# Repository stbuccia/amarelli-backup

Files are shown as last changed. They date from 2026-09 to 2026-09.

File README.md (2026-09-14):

# Liquorice Backup

Liquorice Backup is a liquorice tin backup box. 

## Why

As a photographer travelling without a laptop, you need a safe way to free your camera SD card anywhere. This project was born for that:

* Insert the camera SD into the box: it copies every new photo to a local cache immediately, so you can remove the card right away and keep shooting
* No internet needed for caching; no SD needed for uploading. The box uploads in background to your cloud when Wi-Fi is available
* A small database avoids re-uploading the same file twice

It is a low-cost, open-source alternative to commercial backup devices, built inside an Amarelli liquorice tin.

This project was made for the [Laboratorio di Making](https://www.unibo.it/it/studiare/insegnamenti-competenze-trasversali-moocs/insegnamenti/insegnamento/2025/545359) exam at the University of Bologna.

## How it works

You put your camera microSD card in the box and it backups your photo copying them locally, and then uploading in your favorite cloud storage (WebDav Server ory any place with rclone supports like Dropbox, Google Drive and over 70 more cloud storages). E-ink screen show you the progress, four buttons allow you to interact and a LED show the status with the colour.  

You can check by yourself in this demo video, it shows the local caching, the upload and how you can pause/resume it:

https://github.com/user-attachments/assets/87a310ae-04e9-4852-b67a-d44d25a2fe82

## Documentation

The full step-by-step guide is in the [wiki](wiki/Home.md). Follow the chapters in order the first time:

1. [What you need](wiki/01-what-you-need.md) - parts lists, where to buy and the prices
2. [Wiring and assembly](wiki/02-wiring-and-assembly.md) - how to connect everything
3. [Prepare the SD card and OS](wiki/03-prepare-os.md) - Raspberry Pi OS, SSH and Wi-Fi
4. [Install the software](wiki/04-install-software.md) - The process of installing the project
5. [Backup destination](wiki/05-backup-destination.md) - WebDAV or rclone
6. [Daily use](wiki/06-daily-use.md) - screen, buttons, LED and web page
7. [Run as a service and troubleshooting](wiki/07-service-and-troubleshooting.md) - if you come in to errors check this page for a solution

## Quick start

On the Raspberry Pi, after cloning the repository:

```bash
./install.sh          # installs everything and enables the service
sudo reboot
```

The box starts on its own through the `liquorice` service. To try the software on a PC with no hardware:

```bash
./install.sh --mock
.venv/bin/python software/main.py --mock
```

More in [Install the software](wiki/04-install-software.md).

## Repository layout

+ `software/`: the Python app
+ `config.json`: app settings
+ `.env`: secrets (WebDAV, Wi-Fi). You create this yourself; keep it private and out of git
+ `software/tests/hardware/`: small scripts to test each part
+ `hardware/`: wiring, schematic and electronics notes
+ `systemd/`: the service unit
+ `wiki/`: the step-by-step guide

## Credits

- [Amarelli Fabbrica di Liquirizia SRL](https://www.amarelli.it/) a company which produces delicious liquorice and very nice tin boxes (that i collect)
- [rclone project](https://rclone.org/) , that make my project more universal allowing to backup photos to every possible (virtual) place
- [@sudomod_wermy](https://linktr.ee/sudomod_wermy) which inspires me with him with his [MintyPi](). Sadly the project page is actually down.
- Luca Jacopo, a friend which lent me his 3d printer

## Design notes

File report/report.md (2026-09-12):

# Liquorice Backup

### Un dispositivo di backup fotografico in una scatoletta di liquirizia

Relazione per l'esame di Laboratorio di Making
Alma Mater Studiorum, Università di Bologna
Anno Accademico 2025/26

Autore: Stefano Bucciarelli  
Repository: <https://github.com/stbuccia/amarelli-backup>  
Documentazione utente (wiki): <https://github.com/stbuccia/amarelli-backup/blob/main/wiki/Home.md>

<table>
<tr>
<td style="width:50%; text-align:center; vertical-align:top;">
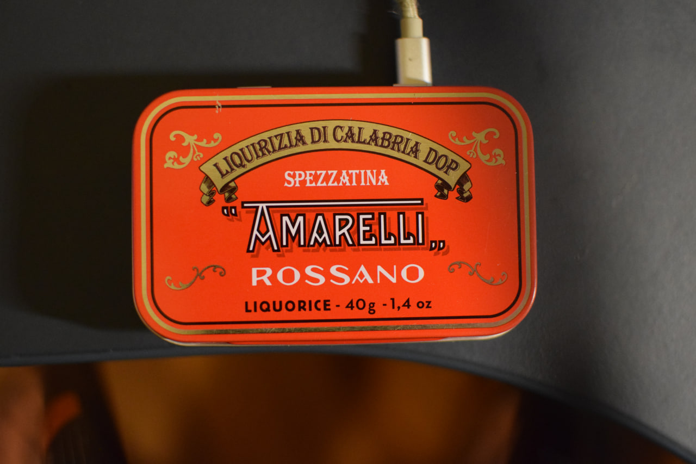
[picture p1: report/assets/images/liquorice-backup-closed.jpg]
Dispositivo chiuso nella scatoletta Amarelli

<br><em>Figura 1: Dispositivo chiuso — scatoletta Amarelli rossa (usabile a coperchio chiuso tramite LED).</em>
</td>
<td style="width:50%; text-align:center; vertical-align:top;">
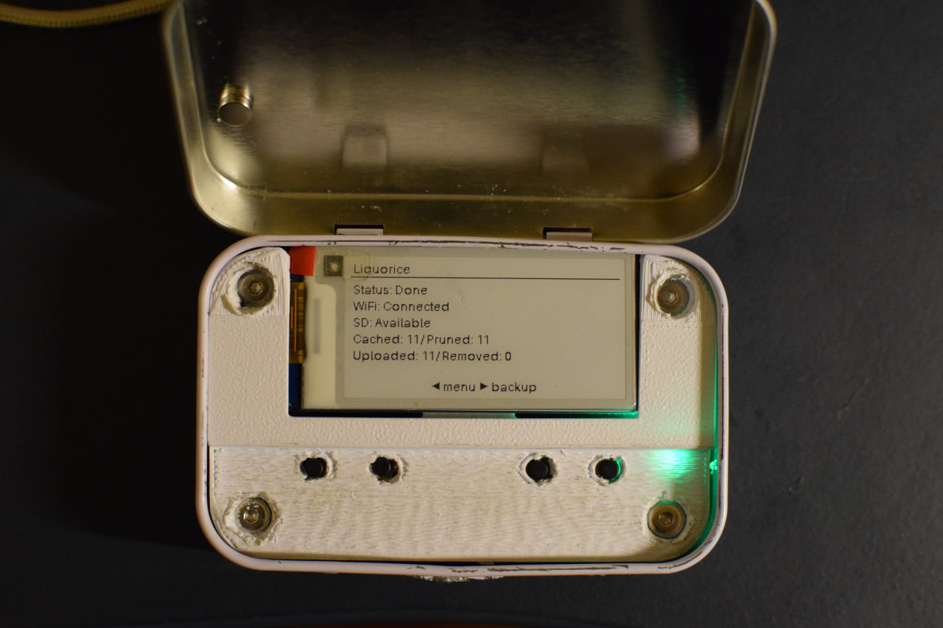
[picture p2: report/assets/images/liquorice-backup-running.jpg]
Dispositivo aperto con schermo acceso

<br><em>Figura 2: Dispositivo aperto — e-paper 2.13" con stato "Done" e LED verde, topper bianco.</em>
</td>
</tr>
</table>

---

## Indice

1. [Introduzione](#1-introduzione)
2. [Hardware](#2-hardware)
3. [Breadboard e circuito](#3-breadboard-e-circuito)
4. [Assemblaggio](#4-assemblaggio)
5. [Modellazione e stampa 3D](#5-modellazione-e-stampa-3d)
6. [Software](#6-software)
7. [Sviluppi futuri](#7-sviluppi-futuri)
8. [Conclusioni](#8-conclusioni)

---

## 1. Introduzione

Questa relazione è in italiano perché è finalizzata all'esame, mentre tutto il resto del repository è in inglese, per garantire migliore riprodubilità.

Liquorice Backup è un dispositivo di backup fotografico costruito dentro una scatoletta di latta di liquirizia Amarelli. L'utilizzo è il seguente, si infila la microSD della fotocamera nel lettore sul fianco e il dispositivo copia subito le foto nuove in una cache locale per poi caricarle in background sul cloud. Un database tiene traccia di cosa ha già fatto, così non carica mai due volte lo stesso file.

I due passaggi sono deliberatamente indipendenti: per fare la cache non serve Internet, per fare l'upload non serve la SD. È questa separazione che rende il dispositivo utile in viaggio, che è il caso d'uso per cui è nato.

L'interazione avviene tramite uno schermo e-paper da 2.13", quattro pulsanti, un LED RGB e, per configurazioni più comode, come per impostare una connessione a una nuova rete WiFi, una pagina web servita dal dispositivo stesso.

Questa relazione si concentra sul perché delle scelte e sui dettagli implementativi, comprese le strade sbagliate. Non è un manuale, quindi chi volesse riprodurre il progetto o usarlo come utente finale trova tutto nella [wiki del repository](https://github.com/stbuccia/amarelli-backup/blob/main/wiki/Home.md).

### 1.1 L'idea

L'idea nasce da un problema reale: quando vado in vacanza porto la fotocamera ma non il portatile, e questo significa che per giorni le foto vivono in un unico posto, la scheda SD nella fotocamera, sperando sempre che non si corrompa. Esistono dispositivi commerciali che risolvono il problema, ma sono costosi, chiusi e legati all'ecosistema del produttore, e non ho trovato un progetto DIY open source equivalente.

Il secondo ingrediente è che il mio gusto apprezza abbondantemente le liquirizia Amarelli e, di conseguenza, un collezionista involontario delle loro scatolette di latta.

Per il progetto però ho scoperto che le lattine Amarelli misurano circa 94 × 60 × 22 mm, che è uno standard di fatto per le scatoline delle caramelle alla menta (ad esempio le Altoids) hanno praticamente le stesse dimensioni. Questo ha due conseguenze concrete. Il progetto diventa universale, perché chi non trova le scatolette Amarelli può usare qualsiasi altra mint tin standard. E come vedremo successivamente esistono già componenti pensati per quel formato, in particolare la Mint Tin Sized Perma-Proto Breadboard, che entra nella scatoletta senza tagli.

L'ispirazione formale viene dal MintyPi di sudomod, una console portatile per retrogaming costruita in una scatoletta di Altoids che avevo visto anni fa su YouTube. Da lì viene la voglia di provarci, ma le due implementazioni divergono, perché MintyPi si basa su un PCB progettato su misura mentre qui ho scelto la strada della perfboard cablata a mano (la scelta è rimandata al paragrafo 3.3).

### 1.2 Requisiti

Oltre a garantire il funzionamento sopra citato ho fissato tre ulteriori requisiti, che poi hanno determinato alcune scelte implementative successive:

1. Usabile anche a scatoletta chiusa. In viaggio il dispositivo starà in uno zaino, non su un tavolo, quindi serve un feedback che funzioni senza guardare lo schermo (il LED RGB) e una modalità automatica in cui il backup parte da solo.
2. Nessuna dipendenza da una rete Wi-Fi già configurata. Un dispositivo da viaggio si trova per definizione su reti sconosciute, da cui la separazione fra cache e upload e la possibilità di far creare al dispositivo un proprio access point.
3. Minimizzare gli accessi via SSH. Se per cambiare un'impostazione devo aprire un terminale, il dispositivo non è finito: da qui il menù a bordo e la pagina web.

---

## 2. Hardware

### 2.1 Il microcomputer: Raspberry Pi Zero W

Ho puntato su Raspberry Pi per la notorietà e per la quantità di documentazione disponibile. La scelta del modello è stata un processo di esclusione.

La gamma "grande" (Pi 3, 4, 5) l'ho esclusa per le dimensioni: 85 × 56 mm, e con i connettori Ethernet e USB-A pieni supera in altezza i 22 mm utili della scatoletta.

La gamma Pico l'ho esclusa perché essendo un microcontrollore non esegue un sistema operativo, ed avrei avuto complicazioni a riguardo, come: niente filesystem montabile, nessun modo di far girare rclone o SQLite, e una memoria RAM troppo piccola.

I Compute Module 4 e 5 li ho esclusi perché sono System-on-Module, non schede complete e non hanno l'header a 40 pin.

Restava la gamma Zero: 65 × 30 mm, header a 40 pin come le sorelle maggiori, Wi-Fi integrato, che qui è un requisito e non un extra. Fra Zero W e Zero 2 W ho scelto lo Zero W per il prezzo, molto inferiore al momento dell'acquisto, accettandone il limite. Avendo i due modelli identici GPIO e dimensioni, il progetto funziona senza modifiche anche con uno Zero 2 W.

### 2.2 Il lettore microSD: il problema della seconda scheda

Il Pi Zero ha un solo slot microSD, occupato dal sistema operativo, quindi serviva una seconda porta per la scheda della fotocamera. Ho valutato tre strade.

La prima era saldare sui pad dello slot SD del Pi. L'ho provato materialmente: non funziona, e a posteriori è ovvio, perché quello slot è collegato al controller SDIO del SoC, che gestisce una scheda sola ed è già occupato dal boot. Non si possono mettere due schede sullo stesso bus senza un controller che le multiplexi.

La seconda era cannibalizzare un adattatore USB-microSD e dissaldare il connettore USB liberando i quattro pad come mostrato in figura (VBUS, GND, D+, D-) :

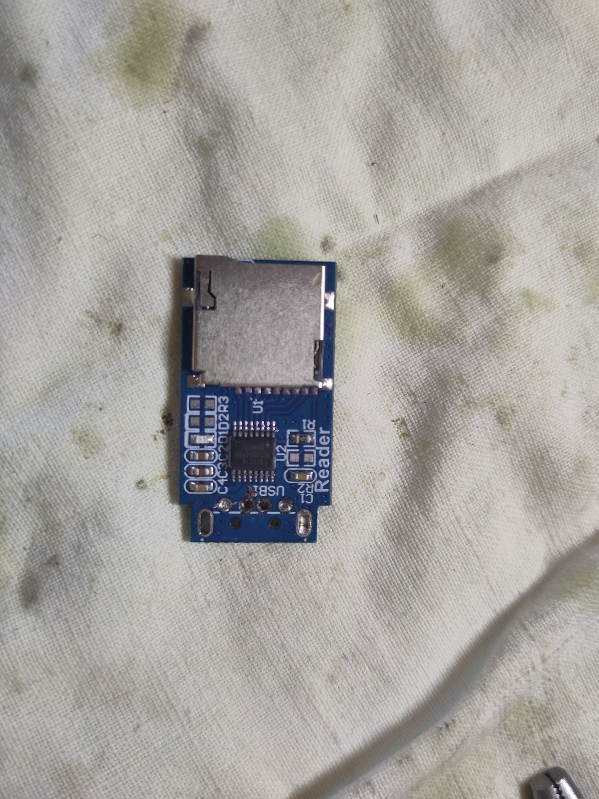
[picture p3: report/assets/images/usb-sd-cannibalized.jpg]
Lettore USB-microSD cannibalizzato


*Figura 3: Lettore USB-microSD cannibalizzato: connettore USB dissaldato, visibili i quattro pad saldati a mano. Strada provata su banco ma scartata perché la Raspberry non rilevava la scheda.*

Per poi collegare i quattro pad del connettore a quattro pad della Raspberry (VBUS in PP1, GND in PP6, D+ in P22 e D- in P23) tramite fili saldati. In fase di test è stata provata questa strada ma dalla Raspberry non veniva letta la SD, quindi è stata scartata.

La seconda, che è quella scelta, è un lettore microSD su SPI: un modulino con sei pin che si attacca al bus SPI0. Il kernel Linux ha il driver `mmc_spi`, quindi la scheda diventa un normale device a blocchi (`/dev/mmcblk1`) montabile come qualsiasi altro. Si è rivelata giusta anche per una ragione che all'inizio non avevo considerato: è la meno esosa in termini di corrente, e visti i problemi di alimentazione descritti più avanti l'opzione USB non avrebbe comunque tenuto.

Il prezzo da pagare è la velocità più ridotta, che si traduce in maggior tempo per la copia locale precedente all'upload remoto. È accettabile perché il collo di bottiglia percepito è comunque l'upload sul cloud.

Un dettaglio importante è che il lettore condivide il bus SPI0 con lo schermo: lo schermo sta su CE0 (BCM 8), il lettore su CE1 (BCM 7), mentre MOSI e CLK sono in comune. È il funzionamento normale di SPI, dove il chip-select decide chi ascolta, ma richiede una configurazione esplicita.

### 2.3 Lo schermo: e-paper contro LCD

Ho valutato sia un display e-paper sia un LCD: L'LCD vince su reattività, colore e prezzo, ma consuma in modo continuo. L'e-paper ha le proprietà opposte, ed entrambe sono allineate ai requisiti: è bistabile, quindi l'immagine consuma solo durante il refresh, che per un dispositivo il cui stato cambia poche volte al minuto è il profilo ideale, ed è leggibile in pieno sole. I contro sono il refresh lento, il bianco e nero puro, nell'ordine dei secondi per un aggiornamento completo, ma dal momento che l'interazione utente è comunque limitata non ho valutato questi fattori come eccessivamente critici.

Ho scelto un Waveshare 2.13" e-Paper HAT (V4): 250 × 122 pixel, monocromatico a 1 bit, controller SSD1680, interfaccia SPI, controllando che la dimensione rientrasse nei limiti imposti dalla lattina. Nonostante abbia preso l'HAT per semplicità, ma non ho usato il suo connettore a 40 pin, perché impilarlo sopra il Raspberry avrebbe consumato tutta l'altezza disponibile. Ho usato invece il connettore laterale a 8 fili, tagliando le terminazioni femmina per saldare direttamente sulla board (vedi paragrafo 4.2).

### 2.4 Pulsanti, LED e reed switch

Quattro pulsanti tattili 6 × 6 × 6 mm, scelti per economicità e reperibilità, collegati fra il proprio GPIO e massa. Il numero è una decisione di progetto: inizialmente pensavo che due bastassero, ma il requisito di minimizzare gli accessi SSH implicava che tutte le impostazioni fossero modificabili a bordo, e quindi un menù navigabile. Con quattro tasti (su, giù, indietro, conferma) la navigazione in un menù è naturale, quindi mi sono sembrati il costo minimo per un'interfaccia decente.

Gli altri due componenti servono al primo requisito, l'usabilità a scatoletta chiusa, che schermo e pulsanti non soddisfano perché presuppongono entrambi il coperchio aperto.

Il primo è un LED indirizzabile WS2812B: la scelta dell'RGB invece di LED monocromatici è dettata dal numero di stati da rappresentare e la codifica avviene per colore, più il lampeggio come dimensione aggiuntiva (vedi paragrafo 6.4).

Il secondo è un reed switch, un interruttore che si chiude in presenza di un campo magnetico, abbinato a un magnetino incollato al coperchio: chiudendo la scatoletta il contatto si chiude e il software manda lo schermo in sleep, risparmiando energia ed evitando refresh inutili di un pannello che nessuno sta guardando. Qui ho sbagliato al primo tentativo comprando i reed in ampolla di vetro, i più comuni ed economici e anche estremamente fragili: si sono rotti mentre piegavo i terminali per farli stare nella board. Sono passato alla versione in plastica, che sicuramente si è prestata di più per essere maneggiata (vedi Figura 7 per il test su breadboard del reed in vetro).

### 2.5 Alimentazione: il tentativo fallito

Nel dispositivo finale la batteria non c'è e si alimenta via micro-USB. Questo implica che il dispositivo deve essere usato vicino a una presa di corrente o tramite powerbank. L'idea della batteria però c'è stata dall'inizio alla fine, e questa reputo sia la mancanza più grande nel risultato finale.

Dopo aver misurato lo spazio residuo avevo identificato una LiPo 803450 da 1500 mAh (50,7 × 34 × 8 mm), abbastanza compatta da lasciare spazio, sul piano orizzontale, anche al modulo di boost e carica.

Il primo tentativo è stato con boost e caricabatteria separati: un boost converter basato su TPS61023 più un modulo di carica per LiPo indipendente. Il problema è stato reso evidente già dai test con raspberry che non c'è nessun power path: con boost e caricatore indipendenti la batteria è contemporaneamente sorgente per il carico e destinazione della carica, e questo rende impossibile usare il dispositivo mentre si carica.

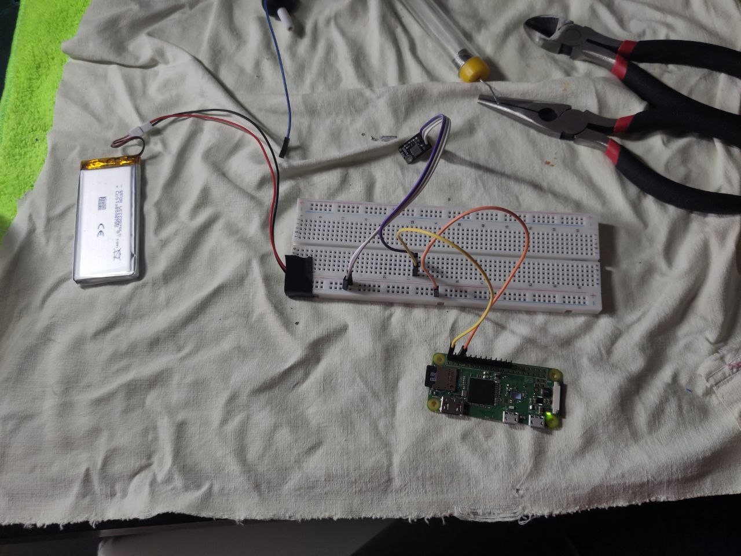
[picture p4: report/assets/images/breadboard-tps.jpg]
Test breadboard con boost TPS61023 e LiPo


*Figura 4: Primo tentativo di alimentazione su breadboard: modulo boost TPS61023 + caricatore LiPo separato (senza power path). Funzionante a banco ma inutilizzabile sotto carica.*

Il secondo tentativo è stato con un Adafruit PowerBoost 1000C, che sulla carta risolveva il problema: integra sulla stessa scheda un caricabatteria per LiPo con gestione del power path erogacorrente a 5V tramite boost TPS61090 e segnala la batteria scarica.

Inizialmente i test sono andati bene, il problema si è manifestato solo con il software completo e tutti i componenti collegati, il Raspberry continuava a riavviarsi, e da lì non ho più avuto tempo per sistemare la cosa. Non ho quindi una diagnosi definitiva, solo delle ipotesi: che il carico completo (Pi con Wi-Fi attivo, refresh dello schermo, lettura della SD e LED acceso) superi comunque l'ampere erogabile dal modulo nei momenti peggiori

Nelle prove avevo usato anche un MAX17043, un fuel gauge I2C, per leggere lo stato di carica e mostrarlo sullo schermo, e i test sul bus I2C erano andati a buon fine.

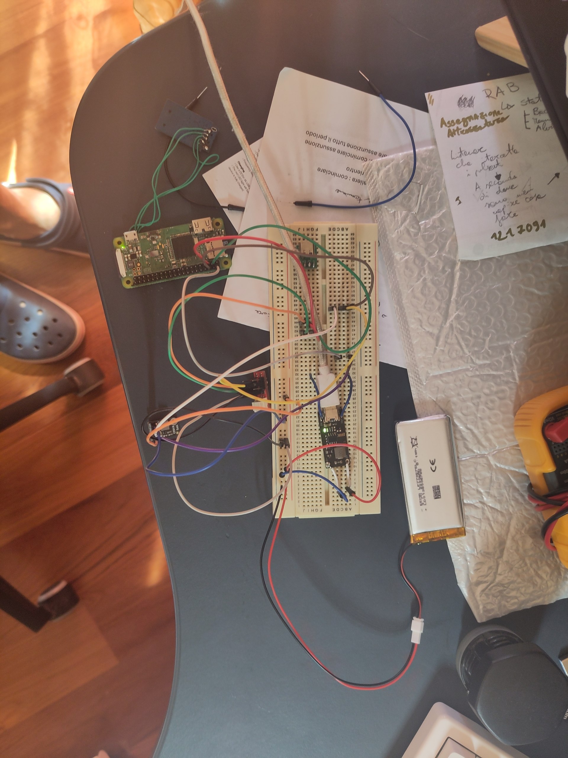
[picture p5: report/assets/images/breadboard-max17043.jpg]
Test breadboard con MAX17043 e LiPo 803450


*Figura 5: Test del fuel gauge MAX17043 su I2C con LiPo 803450 1500 mAh. La lettura dello stato di carica funzionava correttamente.*

Finito il tempo prima della scadenza dell'esame, ho preferito consegnare un dispositivo che funziona in modo affidabile alimentato via USB piuttosto che uno con la batteria e i riavvii. Rimane il primo punto degli sviluppi futuri (vedi capitolo 7), e la buona notizia è che la rinuncia alla batteria ha liberato parecchio spazio in altezza, semplificando l'assemblaggio finale.

---

## 3. Breadboard e circuito

### 3.1 Prototipazione su breadboard

Partendo da un basso livello di competenza elettronica, la breadboard è stata un passaggio necessario. La strategia è stata piuttosto semplice: un componente alla volta, ognuno con il suo test scritto ad hoc, per controllare di aver compreso come andassero collegati i componenti e che non ci fossero guasti fisici.

Questi test sono rimasti nel repository (`software/tests/hardware/`) e sono diventati uno strumento diagnostico permanente: quando qualcosa non va nel dispositivo assemblato, il primo passo è sempre rilanciarli per capire se il problema è nel cablaggio o nel software.

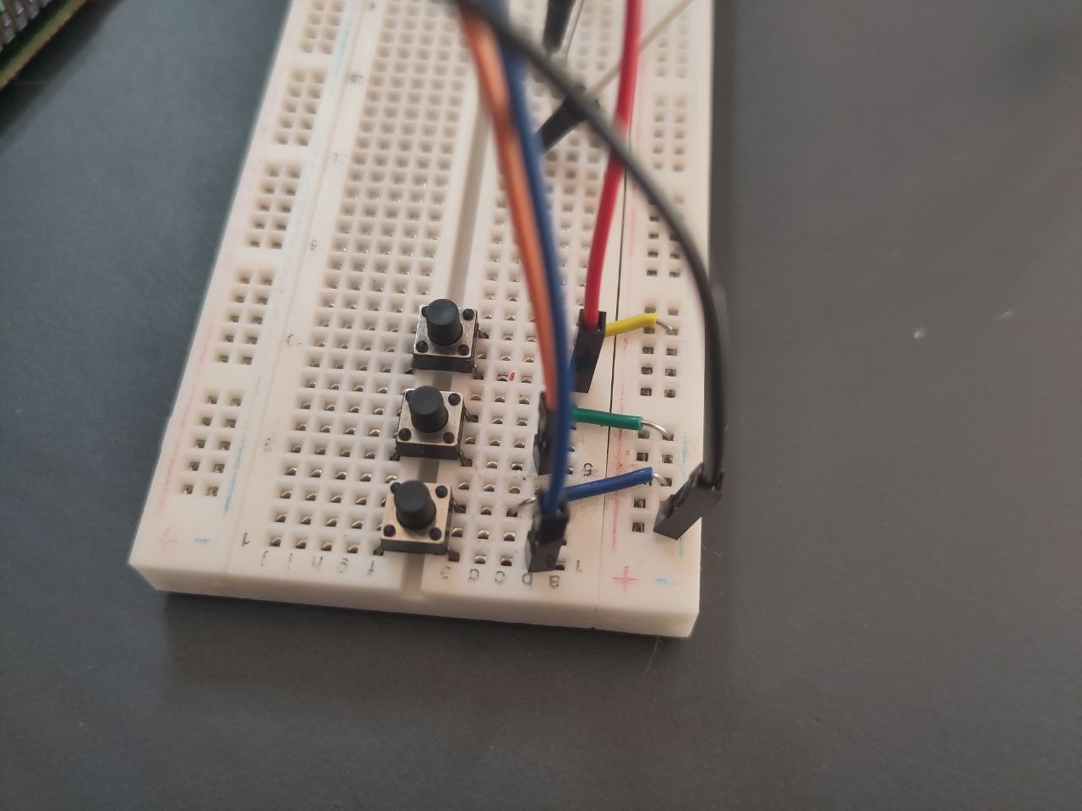
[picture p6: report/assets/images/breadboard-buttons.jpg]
Test pulsanti su breadboard


*Figura 6: Test dei pulsanti tattili su breadboard (tre pulsanti in fase iniziale, poi quattro nel dispositivo finale): verifica di cablaggio e debounce.*

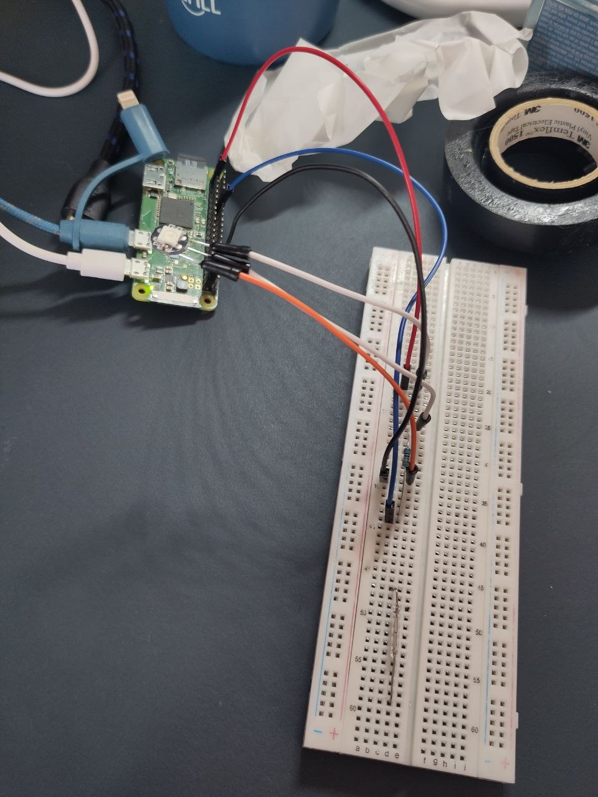
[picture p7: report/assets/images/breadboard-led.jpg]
Test LED WS2812B e reed switch


*Figura 7: Test LED WS2812B + reed switch (ampolla di vetro, poi sostituito con versione in plastica) collegati al Pi Zero W: validazione del feedback a scatoletta chiusa.*

### 3.2 Lo schema elettrico

Prima di passare al circuito definitivo ho disegnato lo schema con EasyEDA (<https://easyeda.com>), un software per la progettazione PCB, l'ho scelto perché gira nel browser e ha una curva di apprendimento molto bassa.

Seguendo i consigli di alcune guide online non ho disegnato i collegamenti come fili, ma ho usato le net label: ogni pin porta un'etichetta, e due pin con la stessa etichetta sono elettricamente connessi.

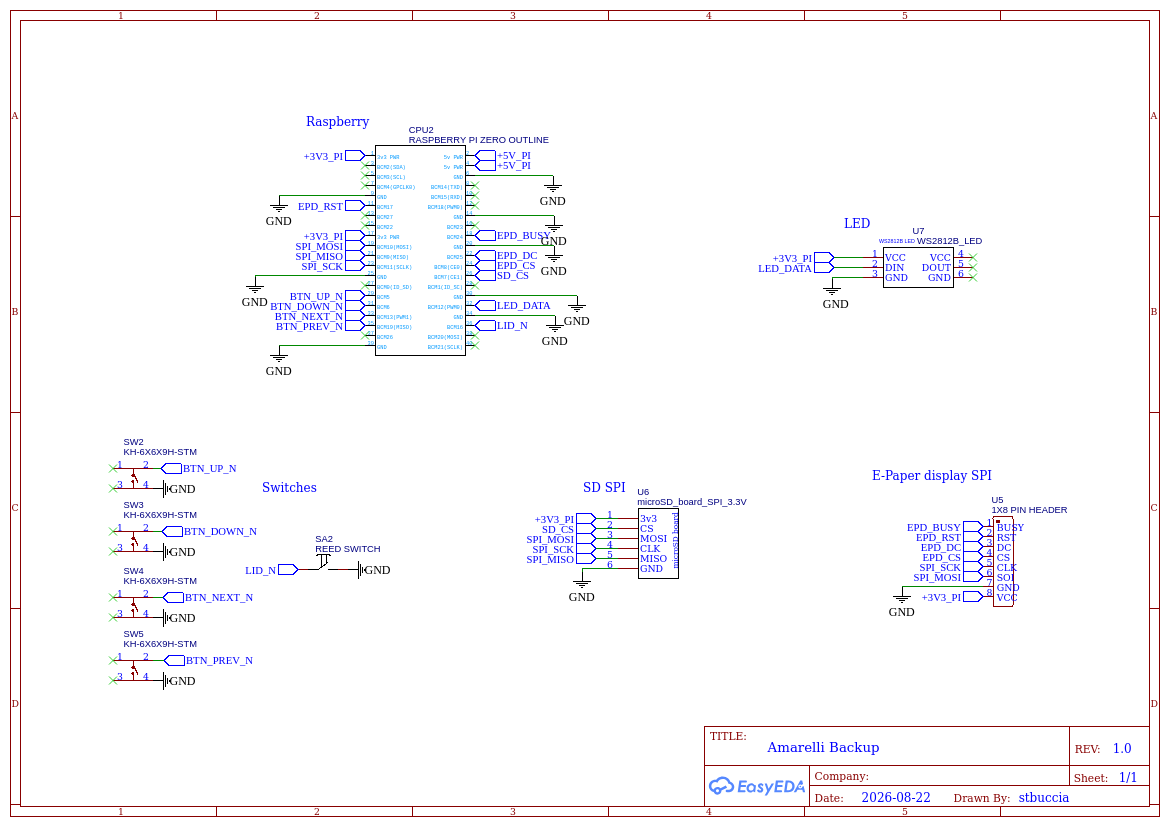
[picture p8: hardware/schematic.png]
Schema elettrico


*Schema elettrico: tutti i collegamenti verso il Raspberry Pi Zero.*

Il risultato, in sintesi:

| Componente | Interfaccia | Pin (BCM) |
|---|---|---|
| Display e-paper | SPI0, CE0 | DIN 10, CLK 11, CS 8, DC 25, RST 27, BUSY 24 |
| Lettore microSD | SPI0, CE1 | MISO 9, CLK 11, MOSI 10, CS 7 |
| Pulsanti | GPIO in pull-up | Left 5, Down 6, Up 13, Right 19 |
| LED WS2812B | PWM0 hardware | DIN 12 |
| Reed switch | GPIO in pull-up | 16 |

Una nota su RST 27: la documentazione Waveshare usa BCM 17 per il reset del display, ma sul mio Raspberry quel pin è danneggiato, quindi ho spostato il segnale su BCM 27 e ho fatto in modo che l'installer applichi la modifica al driver automaticamente (vedi paragrafo 6.1).

### 3.3 Perfboard contro PCB

A schema pronto, EasyEDA permetteva di generare direttamente un PCB da far produrre. Il PCB avrebbe dato dimensioni controllate al millimetro, nessuna saldatura di cablaggio e un risultato più professionale, ma in caso di errore non avrei avuto modo di risolverlo (e con il mio livello di esperienza la probabilità di errore era alta) e il costo era decisamente elevato considerando la spedizione. La perfboard, al contrario, rende ogni errore recuperabile dissaldando, e costa pochi euro, al prezzo di un cablaggio manuale lungo e delicato.

Ho scelto la perfboard, e la scelta è stata resa facile dalla disponibilità di una Mint Tin Sized Perma-Proto Breadboard: una perfboard con piste pre-stampate secondo la logica riga/colonna delle breadboard, prodotta esattamente nel formato delle mint tin. Entra nella scatoletta Amarelli senza tagli né adattamenti e avere piste già presenti riduce molto il cablaggio, perché i pin dei componenti vicini si collegano stando nella stessa colonna e le rotaie `+`/`−` distribuiscono alimentazione e massa in tutta la board.

---

## 4. Assemblaggio

### 4.1 Disposizione dei componenti

La disposizione è il risultato di vincoli che si sovrappongono. Dal lato frontale lo schermo deve stare in alto e i quattro pulsanti devono essere facilmente raggiungibili: ho deciso di rendere la vista dall'alto simmetrica, disponendo i pulsanti sulla stessa linea orizzontale subito sotto lo schermo(l'ordine riprende quello presente su vim da sinistra a destra è indietro, giù, su, conferma) .

Altri due componenti chiedevano di stare nella parte alta della board per funzionare bene: il LED (che deve affacciarsi al suo foro sulla latta per essere visibile a scatoletta chiusa) e il reed switch (che deve trovarsi il più vicino possibile al magnete sul coperchio). Li ho messi sui due bordi laterali, nelle colonne isolate della perma-proto (colonna 0 e colonna 32), dove i fori non sono in comune con altre righe e colonne, così i loro segnali non interferiscono con nient'altro.

Anche il lettore SD è nella parte alta, per una ragione precisa: mantenerlo orientato in modo che la scheda entri diritta rispetto al fianco della latta. Se fosse stato ruotato la SD sarebbe dovuta entrare dal lato opposto.

Di conseguenza al Raspberry Pi è rimasta la parte inferiore, montato capovolto sulla faccia posteriore della board, con l'header saldato dal lato inferiore e il bordo superiore del Pi allineato al bordo superiore della board (scelta necessaria perché la microusb sia raggiungibile dall'esternoa). Un'osservazione a posteriori: avendo rinunciato alla batteria ed essendo quindi obbligato ad esporre la microusb e avrei potuto ruotare il Raspberry per farlo appoggiare sul fondo della latta e avere in questo modo la microusb non ruotata, con lo stesso discorso fatto in precedenza con la SD.

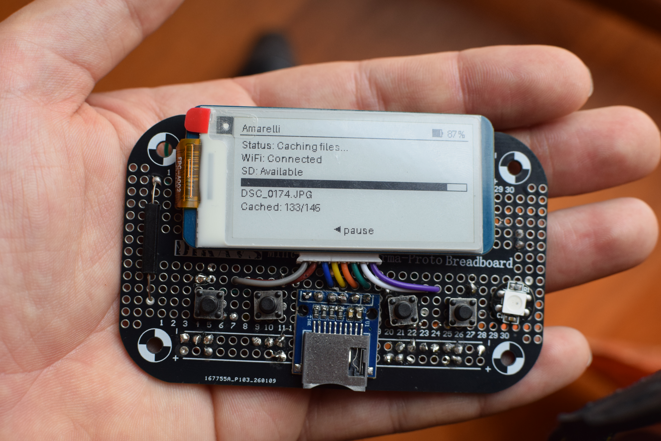
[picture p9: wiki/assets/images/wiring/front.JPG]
Vista frontale


*Vista frontale: schermo e Raspberry allineati al bordo superiore della board.*

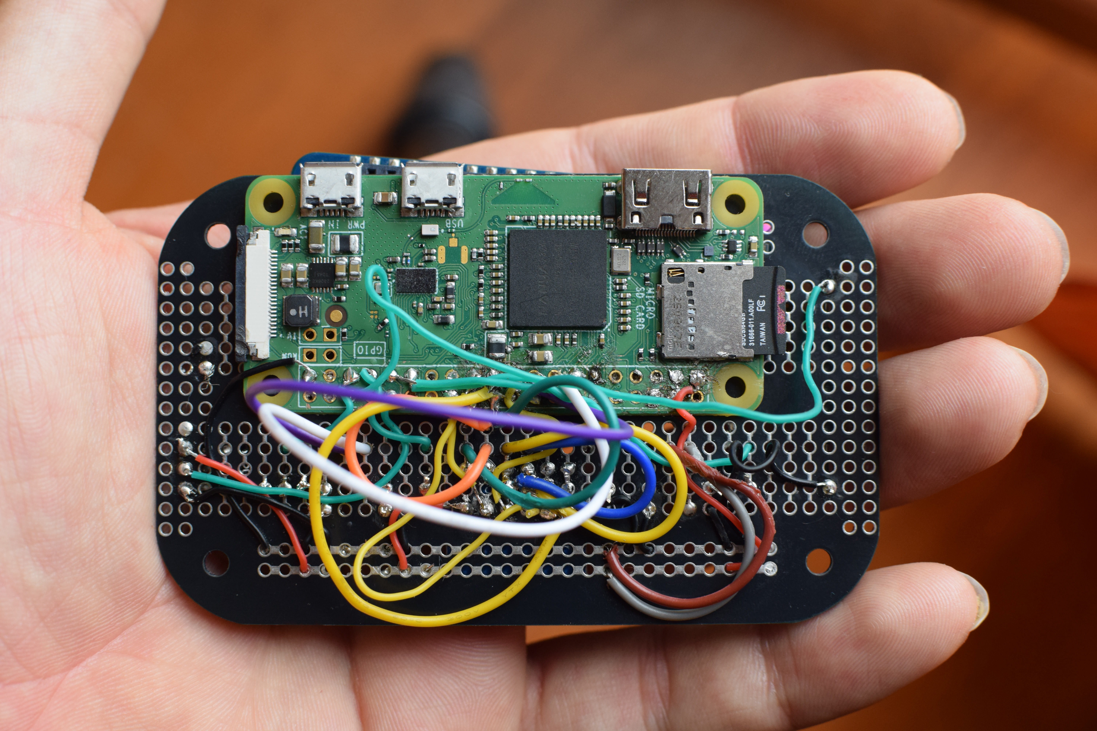
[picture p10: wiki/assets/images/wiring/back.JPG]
Vista posteriore


*Vista posteriore: il Pi fissato sul retro della board e tutti i cavi di collegamento.*

### 4.2 Saldature e cablaggio

Due componenti non sono saldati ma incollati con nastro biadesivo forte (3M 5952 VHB): il Raspberry e lo schermo. È una scelta deliberata, perché sono i due pezzi più costosi e gli unici che potrei voler recuperare, e il biadesivo dà una tenuta meccanica sufficiente senza rendere lo smontaggio distruttivo. Tutti gli altri componenti sono saldati, usando dove utile degli header a pettine come supporto e tagliandone poi la parte in eccesso.

Il collegamento fra schermo e Raspberry è stato la parte più laboriosa, perché i due si trovano su facce opposte della board. Il connettore a 8 fili in dotazione allo schermo ha terminazioni femmina che non servono a nulla in questo contesto, quindi le ho tagliate ottenendo fili nudi, li ho fatti passare attraverso i fori della perfboard verso il lato inferiore e li ho saldati a destinazione. A seconda del segnale la destinazione è diversa: i segnali dedicati al display (CS/CE0, DC, RST, BUSY) vanno direttamente sui pin del Raspberry, mentre quelli condivisi con il lettore SD (MOSI e CLK) vanno saldati nella stessa colonna in cui è già attestato il lettore, sfruttando le piste della perma-proto per realizzare il bus condiviso senza doppie saldature sullo stesso pin. VCC e GND si prendono dalle rotaie `+`/`−`, alimentate a loro volta dal pin 1 (3,3 V) e dal pin 39 (GND).

Tutto il cablaggio corre sul retro del dispositivo, così la faccia anteriore resta pulita e il topper stampato in 3D può appoggiarsi in piano.

Un consiglio che vale la pena mettere per iscritto: prima di dare tensione ho verificato con il multimetro la continuità delle rotaie e l'assenza di cortocircuiti fra pin adiacenti, in particolare che nessun filo mettesse in contatto 5 V e 3,3 V.

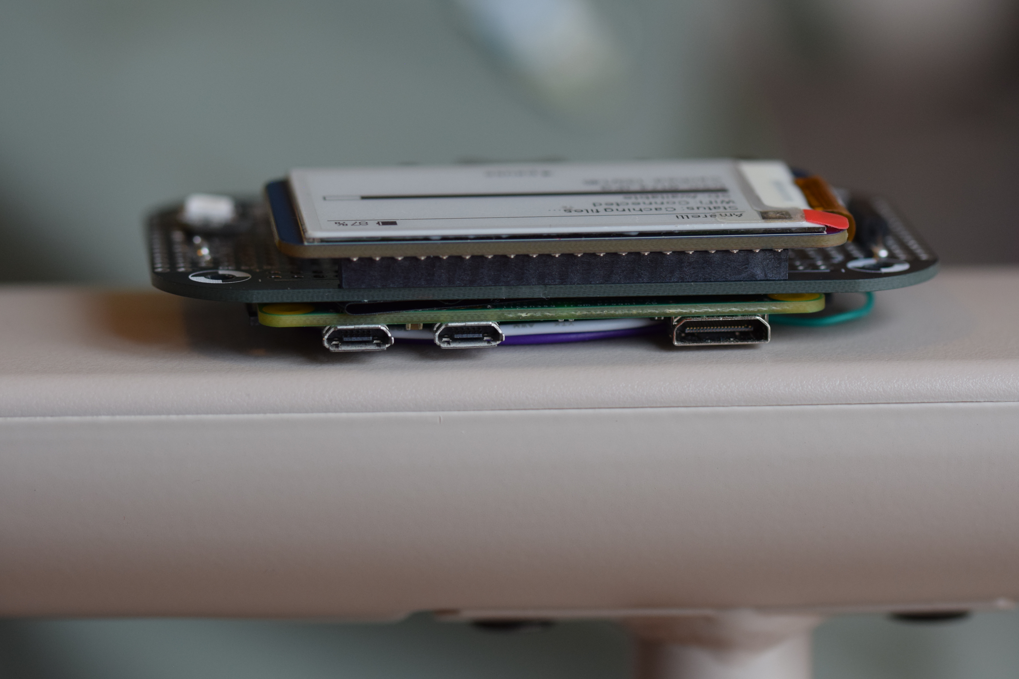
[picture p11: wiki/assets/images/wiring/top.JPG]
Vista dall alto


*Vista dall'alto a cablaggio completato.*

Senza la batteria l'ingombro complessivo sull'asse Z è rimasto ampiamente sotto i 22 mm disponibili (lo stack è base stampata, Raspberry, perfboard e schermo, con il topper a chiudere).

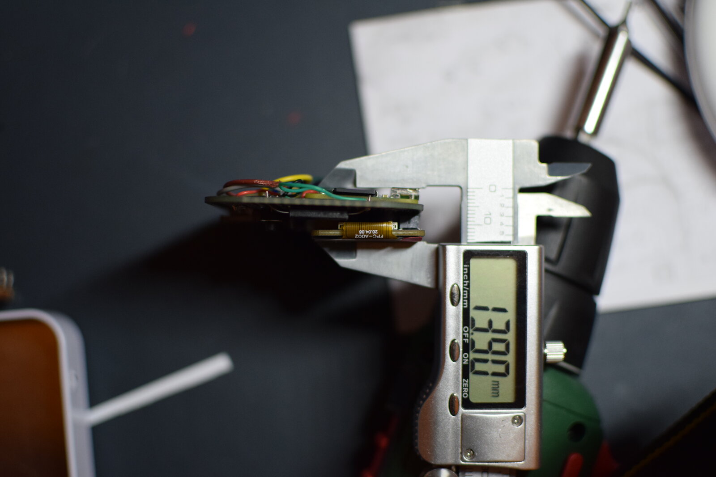
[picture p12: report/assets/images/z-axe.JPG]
Misura altezza stack su asse Z con calibro


*Figura 8: Misura con calibro digitale dell'ingombro su asse Z: 13.90 mm per lo stack (base + Raspberry + perfboard + schermo), ben sotto il limite di 22 mm della scatoletta.*

---

## 5. Modellazione e stampa 3D

L'idea di stampare delle parti in 3D c'è stata fin dall'inizio, per due benefici distinti (fissare il circuito in modo definitivo dentro la scatoletta e rendere il risultato esteticamente presentabile nascondendo il circuito sottostante). Una perfboard nuda con fili a vista dentro una scatoletta di latta è un prototipo, mentre con due cornici stampate diventa un oggetto.

I pezzi sono tre, e sono nel repository in `hardware/3d models/` in formato `.3mf`:

- Base: Cornice che appoggia sul fondo della latta, incollata con biadesivo. Solleva la board per farci stare la Raspberry e lascia dei fori per permettere l'avvitamento in fase di fissaggio.
- Topper: Cornice superiore con le aperture per lo schermo e per i quattro pulsanti. È il pezzo estetico: copre cablaggi e saldature lasciando emergere solo ciò che serve. Qua i fori servono per infilarci dentro le viti.
- Cover: Guscio esterno che avvolge la latta. Non fa parte del dispositivo finito, serve come maschea di foratura.

Come per lo schema elettrico, avendo competenze nulle in materia ho scelto il software Onshape (<https://onshape.com>), un CAD parametrico che gira nel browser.

La modellazione è stata prima di tutto una fase di misura: ho usato un calibro digitale per rilevare dimensioni e distanze reciproche di ogni componente (area visibile del pannello, posizione dei quattro pulsanti rispetto al bordo della board, quota della fessura del lettore SD, posizione delle prese micro-USB). Il metodo di costruzione base è stato principalmente il seguente: schizzo sul piano frontale con la geometria delle aperture e dei contorni, seguito da estrusioni additive per generare il materiale della cornice e sottrattive per ricavare fori e finestre.

Il pezzo più complicato è stato il topper, per un motivo che deriva da una scelta fatta a monte: i pulsanti tattili 6 × 6 × 6 mm sono più bassi della superficie dello schermo, quindi il topper non poteva essere una lastra piana e ha richiesto una sorta di gradino, con la zona dello schermo su un piano e quella dei pulsanti su un piano più basso. Quel gradino ha avuto una conseguenza in stampa, perché la faccia dei pulsanti aveva del vuoto sottostante. Il topper è stato quindi stampato con supporti (è l'unico dei tre pezzi che ne ha bisogno) e la sua superficie risulta meno uniforme, richiedendo una rifinitura a mano con cutter e carta abrasiva.

La stampa è stata affidata a un amico che ha messo a disposizione la sua stampante, una Bambu Lab H2D con nozzle standard da 0,4 mm. Il materiale scelto è PLA Basic bianco di eSUN, conservato in AMS che lo mantiene a temperatura ambiente ed essicca l'umidità in maniera passiva. Il colore bianco è stato scelto per richiamare il bianco del pannello e-paper e la parte inferiore della scatoletta.

Dei tre pezzi, solo il topper ha richiesto i supporti, generati in modalità automatica con strategia tree, a causa del gradino descritto sopra; base e cover sono stati stampati senza supporti. Il consumo indicativo di filamento è di 19 g per il topper e 8 g complessivi per gli altri due pezzi.

<table>
<tr>
<td style="width:33%; text-align:center; vertical-align:top;">
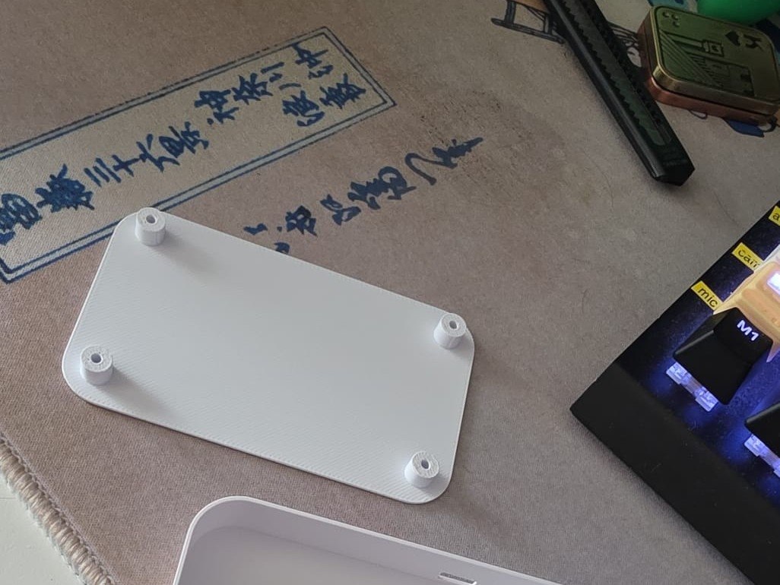
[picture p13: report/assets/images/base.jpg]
Base stampata in PLA bianco

<br><em>Figura 9a: Base — 4 pilastrini, solleva la board per il Raspberry.</em>
</td>
<td style="width:33%; text-align:center; vertical-align:top;">
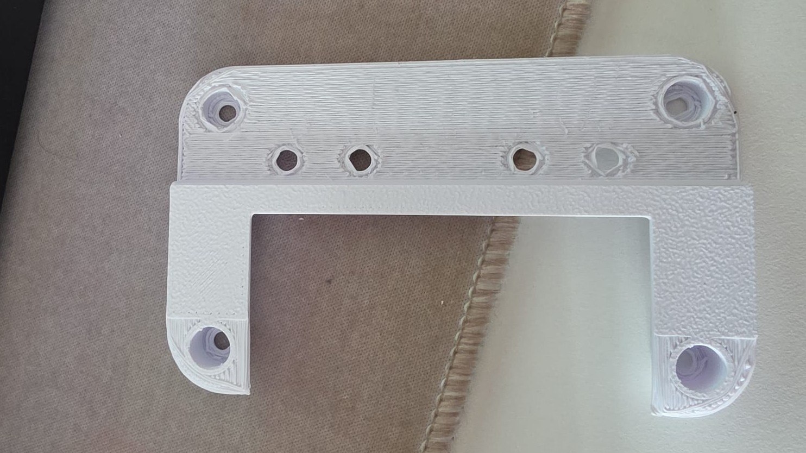
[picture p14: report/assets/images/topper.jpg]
Topper stampato con gradino

<br><em>Figura 9b: Topper — finestra e-paper + 4 fori pulsanti, gradino visibile.</em>
</td>
<td style="width:33%; text-align:center; vertical-align:top;">
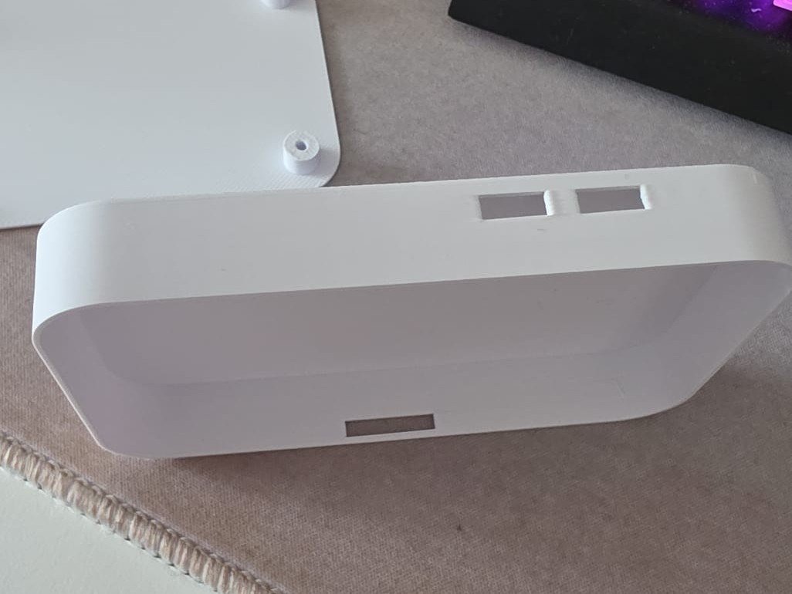
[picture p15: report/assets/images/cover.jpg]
Cover maschera di foratura

<br><em>Figura 9c: Cover — guscio esterno maschera di foratura.</em>
</td>
</tr>
</table>

Una nota che non è tecnica ma fa parte del progetto: avendo a disposizione nove scatolette Amarelli diverse, la scelta di quale usare non era ovvia, così ho coinvolto amici e parenti in una votazione. Ha vinto la più classica, ovvero la numero 1:

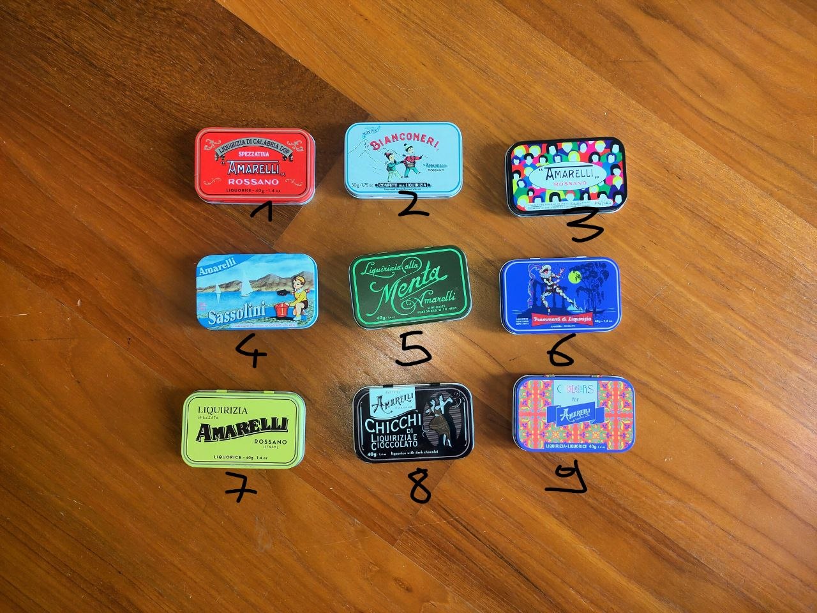
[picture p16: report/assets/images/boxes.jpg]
Le nove scatolette Amarelli candidate


*Figura 10: Le nove scatolette Amarelli candidate numerate 1-9. La votazione tra amici e parenti ha premiato la n.1, la più classica (rossa).*

---

## 6. Software

### 6.1 Configurazione del Raspberry

Il sistema operativo è Raspberry Pi OS Lite (32 bit), senza desktop, perché gni servizio grafico è sprecato.

Tutta la configurazione è automatizzata in `install.sh`.. Lo script è idempotente, quindi rieseguirlo non rompe nulla e serve anzi come strumento di riparazione. Oltre a installare le dipendenze necessarie e configurare il progetto fa le seguenti operazioni.

Prima fra tutte il riconoscimento del lettore SD, oltre ad attivare SPI (`dtparam=spi=on`), fa riconoscere al kernel una scheda SD su SPI richiedendo un device tree overlay dichiarando che sul secondo chip-select di SPI0 c'è uno slot SD:

```
dtoverlay=anyspi,spi0-1,dev=mmc-spi-slot,speed=10000000
```

Con questa riga in `config.txt` il sistema espone entrambi i device (`/dev/spidev0.0` per il display, `/dev/spidev0.1` per il lettore) e la scheda della fotocamera compare come `/dev/mmcblk1`.

Poi per quanto rigurda il driver Waveshare per il display, che come da documentazione viene clonato da GitHub. L'installer lo scarica, applica con `sed` la modifica del pin di reset da BCM 17 a BCM 27 (vedi paragrafo 3.2) e lo copia nel virtualenv.

Infine è l'avvio automatico, gestito da un'unit systemd generata da un template sostituendo utente e percorsi reali. Un dettaglio: `KillSignal=SIGINT` fa sì che systemd non termini il processo brutalmente ma gli mandi un SIGINT, che in Python diventa una `KeyboardInterrupt` e risale fino al blocco `finally` di `main.py` (che spegne il LED, smonta la scheda, chiude i GPIO e manda l'e-paper in sleep con un refresh completo). pannello con un'immagine fantasma e il LED acceso.

### 6.2 Ambiente di sviluppo

Il codice è scritto in python, le dipendenze sono in `pyproject.toml`, con quelle specifiche del Raspberry (`spidev`, `lgpio`, `RPi.GPIO`, `rpi_ws281x`) isolate in un extra opzionale, così l'installazione funziona anche su un PC dove quei pacchetti non si compilerebbero.

Lo sviluppo è avvenuto prevalentemente su un laptop, con git come mezzo di sincronizzazione verso il dispositivo e all'occorrenza sshfs per fare modifiche dirette quando serviva provare qualcosa sull'hardware senza passare da un commit. I segreti (credenziali WebDAV e password dell'access point) sono in un file `.env` fuori da git, mentre la configurazione non sensibile è in `config.json`.

### 6.3 Architettura

Il software è organizzato in moduli con responsabilità singole, tutti in `software/`, in seguito lascio una breve descrizione di ogni modulo:

```
main.py         orchestrazione: avvio, event loop, collegamento dei pezzi
backup.py       macchina a stati della pipeline di backup
cache.py        copia dalla SD alla cache locale, pruning
uploader.py     pipeline di upload astratta, con i backend webdav_uploader e rclone_uploader
database.py     accesso a SQLite (models.py contiene la dataclass FileRecord)
sdcard.py       rilevamento e mount della scheda della fotocamera
display.py      rendering e-paper: viste, composizione, refresh
menu.py         albero di menù e navigazione
led_status.py   stato -> colore del LED
keylistener.py  input: pulsanti GPIO o tastiera, più il reed switch
eventbus.py     bus di eventi pub/sub
config.py       configurazione (config.json e .env), persistenza
wifi.py         access point, scansione e connessione via nmcli
flask_app.py    pagina web di configurazione
```

Il principio organizzativo è che la logica di backup non sa nulla dell'interfaccia, e viceversa: `backup.py` non importa `display.py` né `led_status.py`, ma pubblica eventi e chi è interessato reagisce.

In seguito illustro i design pattern usati nel progetto.

Macchina a stati, in `backup.py`, che è il pattern portante. Un enum con nove stati (`IDLE`, `CACHING`, `UPLOADING`, `REMOTE_CLEANUP`, `PRUNING`, `COMPLETED`, `PAUSED`, `RETRYING`, `ERROR`) e una lista dichiarativa di fasi, dove ogni voce dice quale metodo chiamare su quale oggetto:

```python
_PHASES = [
    (State.CACHING,        "_cache",    "copy"),
    (State.UPLOADING,      "_uploader", "upload"),
    (State.REMOTE_CLEANUP, "_uploader", "cleanup_remote"),
    (State.PRUNING,        "_cache",    "prune"),
]
```

Il motore itera sulla lista, salta le fasi non pertinenti alla modalità corrente e gestisce in un unico punto retry, pausa ed errori. Il vantaggio è che la ripresa dopo una pausa diventa banale: si memorizza lo stato da cui si è usciti, si cerca il suo indice e si riparte da lì.

Repository, in `database.py`, che incapsula tutto SQLite: nessun altro modulo scrive SQL, ma chi ha bisogno di dati chiama metodi il cui nome descrive l'intenzione (`find_pending_uploads()`, `mark_uploaded()`) e riceve oggetti `FileRecord`.

Event bus, in `eventbus.py`, con implementazione minimale (un dizionario evento/handler, un `on()` e un `emit()`). Un dettaglio che si è rivelato importante è che `emit()` racchiude ogni handler in un `try/except` che logga l'eccezione senza propagarla, quindi un bug nel rendering non può interrompere un backup in corso: per un dispositivo di backup è la priorità giusta. Gli eventi in circolazione riguardano i cambi di stato (`backup:state`), l'avanzamento sui singoli file (`file:cached`, `file:uploaded`), l'input (`key:press`), le modifiche di configurazione (`config:set`) e il rendering (`ui:redraw`, `menu:opened`).

Template method con strategy e factory, in `uploader.py`. La classe astratta `Uploader` implementa una volta sola tutta la logica comune a qualsiasi destinazione (ciclo sui file pendenti, creazione delle directory remote, aggiornamenti del database, statistiche, classificazione degli errori), mentre le sottoclassi implementano solo tre metodi primitivi: `ensure_remote_dir()`, `put()` e `delete()`.

Composite, nel menù, che è un albero di `MenuItem` dove ogni nodo può avere figli. Le voci del menù principalmente modificano un'impostazione in questo modo: il nodo padre porta la chiave di configurazione e i figli portano il valore, quindi selezionare un figlio significa scrivere quella chiave con quel valore, senza scrivere codice per ogni singola impostazione.

### 6.4 I componenti principali

Il database è un solo file SQLite con una sola tabella, dove ogni riga è un file visto sulla scheda. L'idea che tiene insieme tutto è che lo stato di un file è dedotto dai timestamp (`cached_at`, `uploaded_at`, `pruned_at`) e non memorizzato in una colonna "stato" da mantenere coerente: `cache_path` valorizzato con `uploaded_at` nullo significa "in attesa di upload", e così via. È questo che rende il dispositivo idempotente e resistente alle interruzioni, perché se si spegne a metà upload alla riaccensione i file già caricati non vengono ritoccati e gli altri riprendono, senza nessuna logica di ripristino. Sulla chiave di unicità ho cambiato idea a metà progetto: all'inizio era sull'hash del contenuto, che sembrava sensato, ma causava molti rallentamenti in fase di caching, quindi ho optato per definire l'unicità del file sul percorso di origine.

La cache è il modulo dedicato alla copia dei file in locale. Prima di copiare, il modulo confronta dimensione e mtime con il record nel database e salta i file già a posto senza leggerli. Il pruning, infine, cancella le copie locali secondo una politica configurabile (subito, dopo 7 giorni, dopo 30, mai) con una regola ferrea: si cancella solo ciò che risulta già caricato.

Gli uploader sono due. WebDAV usa `webdavclient3`, e l'unico punto non ovvio è che WebDAV non ha un `mkdir -p`, quindi la creazione delle directory cammina sui componenti del percorso creando quelli mancanti. Rclone invoca il binario esterno via `subprocess` con tre comandi (`mkdir`, `copyto`, `deletefile`), e appoggiarsi a rclone è stata una scelta obbligata perché implementare un uploader per ogni servizio a mano sarebbe stata improponibile. Viene invocato con `--retries 1`, cioè disabilitando il suo meccanismo di retry, perché i retry devono stare in un solo posto (la macchina a stati, che è l'unica che sa mostrare "Retrying..." sullo schermo, far lampeggiare il LED e rispettare una richiesta di pausa).

Attraverso entrambi i backend passa la distinzione fra errori transitori e permanenti, che determina il comportamento visibile: un errore transitorio fa riprovare con backoff esponenziale (5, 10, 20 secondi), uno permanente ferma il backup e chiede all'utente di intervenire. La classificazione avviene su parole chiave nel messaggio (`401`, `403`, `invalid credentials`) e, per rclone, sugli exit code che non migliorano con un retry.

Il rilevamento della scheda usa `lsblk --json` e parte da `mmcblk1`, perché `mmcblk0` è la scheda di sistema, e distingue due domande che all'inizio confondevo (se il device esiste, che serve all'interfaccia per mostrare la scheda come presente appena la si infila, e se è montato e leggibile, che serve alla logica di backup). Il mount ha anche un'attesa esplicita del device node dopo `udevadm settle`, perché fra il momento in cui il kernel riconosce la scheda e quello in cui il nodo è utilizzabile passa un tempo non nullo, e su SPI è più lungo che su un lettore nativo: senza questa attesa il mount fallisce in modo intermittente, che è il tipo di bug peggiore da diagnosticare.

Il display funziona per composizione: si crea un'immagine Pillow a un bit per pixel di 250 × 122, e sopra scrivono tre livelli (la status bar in alto, la vista attiva al centro, la legenda in basso). Le frecce contenute nella legenda sono disegnate come poligoni e non scritte come caratteri, perché il font di default non ha i glifi Unicode dei triangoli e su un pannello a 1 bit un carattere mancante diventa un rettangolo vuoto. Sulla gestione del pannello ci sono due accorgimenti nati da altrettanti problemi reali. Il primo frame usa l'inizializzazione completa e i successivi la modalità veloce, che è molto più rapida ma accumula ghosting, con un refresh completo rieseguito all'uscita dell'applicazione.

E i redraw sono coalescati, perché gli eventi di avanzamento arrivano a raffica (uno per file copiato) e ridisegnare a ogni evento accoderebbe centinaia di refresh lasciando lo schermo sempre indietro: le viste quindi non disegnano ma alzano un flag, e l'event loop esegue al massimo un refresh per ciclo.

Il LED traduce lo stato in un colore più un flag di lampeggio:

| Colore | Stato |
|---|---|
| Bianco | avvio |
| Verde | pronto, oppure completato |
| Giallo | in attesa di una scheda |
| Blu | copia nella cache (lampeggia) |
| Ciano | upload (lampeggia) |
| Magenta | pulizia del remoto o pruning (lampeggia) |
| Arancione | in pausa (fisso) o in retry (lampeggia) |
| Rosso | errore |

Il criterio della codifica è che il lampeggio significa "sto lavorando" e il colore fisso "sto aspettando te, o ho finito". A scatoletta chiusa questo basta per sapere se si può mettere via il dispositivo, che era esattamente il requisito. Il lampeggio gira su un thread dedicato, perché legarlo all'event loop lo renderebbe irregolare (e un LED che lampeggia in modo irregolare sembra un guasto).

Per l'input ci sono due implementazioni della stessa interfaccia: quella GPIO usa `gpiozero.Button` con debounce di 50 ms delegato alla libreria, quella da terminale legge la tastiera in raw mode e decodifica le sequenze di escape delle frecce (ed è ciò che permette di pilotare l'interfaccia da PC in mock). Il reed switch è a parte perché non è un tasto ma uno stato, quindi espone sia una lettura immediata (usata all'avvio, per non accendere lo schermo se il dispositivo parte già chiuso) sia una coda di transizioni.

### 6.5 Un caso d'uso completo

Vale la pena seguire una volta l'intero percorso, da quando l'utente preme Conferma a quando la foto è sul cloud.

La pressione chiude BCM 19 verso massa, `gpiozero` applica il debounce e il callback deposita il tasto in una coda. L'event loop lo estrae e pubblica `key:press`, e l'handler decide in base a due cose (quale vista è attiva e in quale stato è il backup): con la vista di stato attiva e il backup in `IDLE`, il tasto destro significa "avvia".

Prima di avviare, in modalità manuale viene ritentato il mount, perché il caso normale è che l'utente accenda il dispositivo e poi infili la scheda. Se il mount riesce si istanzia la cache e la si passa al backup, e se non riesce ma il database contiene file pendenti il backup parte comunque, perché si può caricare senza scheda.

`Backup.start()` congela le impostazioni in vigore (un cambio di configurazione a metà backup non produce comportamenti misti), passa a `CACHING` e lancia il thread della pipeline. La fase di cache attraversa la scheda, filtra per estensione, confronta con il database, copia a chunk sul file temporaneo, fa il rename atomico e scrive il record, emettendo un evento per ogni file. Ogni evento raggiunge la vista di stato, che incrementa i contatori e avanza la barra, e in parallelo il LED è già passato a blu lampeggiante perché aveva ricevuto il cambio di stato.

La fase di upload recupera i pendenti dal database e per ciascuno calcola il percorso remoto preservando la struttura di cartelle, poi chiama il backend. Al successo il file viene marcato come caricato, al fallimento viene incrementato il contatore dei tentativi ma il file resta pendente, così il tentativo successivo lo riprende. Se la rete cade si passa a `RETRYING`, con LED arancione lampeggiante e attesa a backoff esponenziale spezzettata in intervalli da 50 ms (così una richiesta di pausa viene comunque raccolta subito), e dopo tre tentativi si va in `ERROR`.

Segue poi il pruning delle copie locali (in modalità upload) o la pulizia del remoto (in modalità mirror, dove i file non più presenti sulla scheda vengono rimossi anche dal cloud): le due fasi sono mutuamente esclusive per costruzione. Alla fine si passa a `COMPLETED` con le statistiche aggregate e lo stato "Done".

Il percorso di una modifica di configurazione è più corto ma mostra bene il ruolo dell'event bus. Selezionando un valore nel menù viene emesso `config:set`, e quel singolo evento scatena reazioni in quattro punti diversi: `Config` riscrive `config.json` su disco (quindi l'impostazione sopravvive a un riavvio), `Backup` intercetta la modalità upload/mirror e la applica al backup successivo e `main` ricostruisce l'uploader se è cambiato il backend.

### 6.6 Modalità mock e pagina web

Il flag `--mock` sostituisce l'hardware con dei sostituti software (uno schermo che accetta tutte le chiamate senza fare nulla, la tastiera invece dei pulsanti, il reed switch disattivato, il LED in modalità log) e stampa su stdout la vista corrente in forma testuale a ogni refresh:

```
[DISPLAY] BACKUP | Liquorice | Caching files... (CACHING) | wifi:ON sd:ON | cached:12 pend:12 up:0 bar:12/40 file:IMG_0042.JPG
```

Combinato con l'opzione "Fake SD" del menù (che legge da una cartella locale invece che dal lettore SPI) e con la possibilità di usare una cartella locale come destinazione rclone, permette di eseguire l'intera pipeline su un PC senza avere fisicamente a disposizione la raspberry. È ciò che ha reso possibile sviluppare l'interfaccia senza avere il dispositivo sottomano.

Il modulo `wifi.py` gestisce la rete tramite `nmcli`: sa creare un access point con SSID e password prese dal `.env`, scansionare le reti, connettersi e dimenticare una rete. Sopra questo c'è un captive portal (un piccolo server DNS che risponde a qualsiasi query con l'indirizzo del dispositivo, più i tipici endpoint di rilevamento usati da Android e iOS), il cui effetto è che collegandosi alla rete del dispositivo il telefono apre da solo la pagina di configurazione, senza che l'utente debba conoscere o digitare un indirizzo IP. La pagina, servita da Flask sulla porta 5000, permette di scegliere la rete Wi-Fi, modificare tutte le impostazioni del menù (più alcune che sul menù non ci stanno, come il remoto rclone) e leggere i log. Le modifiche passano dallo stesso evento `config:set`, quindi menù e pagina web sono due interfacce sullo stesso meccanismo e non possono divergere.

Va detto che il server web è in ascolto su `0.0.0.0:5000` senza autenticazione e in HTTP, quindi chiunque sia sulla stessa rete può cambiare la configurazione del dispositivo e leggerne i log. Sull'access point del dispositivo, protetto da password WPA, il rischio è contenuto, ma su una rete condivisa non lo è. Per questo motivo ho scelto di renderlo dispobile solo se

Il logging accompagna tutto (console a livello INFO e file a livello DEBUG, più l'output del servizio via `journalctl`), ed è utile sia in modalità mock, perché rende evidente ciò che accade, che in modalità normale per poter risalire ad eventuali errori.

---

## 7. Sviluppi futuri

Ci sono diversi aspetti migliorabili in questo progetto.

La batteria è il primo punto, e quello che manca al progetto per essere davvero autonomo. Il PowerBoost 1000C c'è già, quindi il lavoro da fare è capire perché il Raspberry si riavvia: misurare la tensione sul rail 5 V durante i picchi, aggiungere capacità di bulk vicino al carico e verificare se il problema si sposta. Da aggiungere poi il fuel gauge MAX17043 su I²C, già testato con successo, per mostrare lo stato di carica sullo schermo.

I pulsanti più alti sono una modifica a costo quasi nullo che semplifica due fasi del progetto: i 6 × 6 × 6 mm scelti sono più bassi dello schermo, e questo ha generato il gradino nel topper che è stato il problema principale della modellazione e della stampa (vedi capitolo 5). Con pulsanti più alti il topper diventerebbe una lastra piana, stampabile senza supporti e con una superficie migliore.

Il PCB migliorerebbe la riproducibilità. Allo stato attuale il progetto non è difficile da ripetere (la wiki riporta tutte le posizioni riga/colonna sulla perma-proto e i test hardware permettono di verificare ogni collegamento prima di chiudere la scatoletta), ma resta una quantità di saldature a mano che con un PCB sparirebbe del tutto, insieme al rischio di errore che portano con sé. Lo schema EasyEDA c'è già, e ora che il circuito è validato sul campo il rischio principale del PCB, cioè sbagliare in modo irreversibile, è molto ridotto.

L'interfaccia ha margini di miglioramento: il pannello 250 × 122 a un bit è sfruttato in modo essenziale, e ci sarebbe spazio per icone dedicate, un'indicazione dei tempi stimati e una gestione più fine dei refresh parziali per aggiornare solo la barra di avanzamento invece di tutto lo schermo.

Sul server web servirebbe un'autenticazione: anche una semplice basic auth con credenziali nel `.env` alzerebbe sensibilmente la barriera, ed è il minimo prima di consigliare a qualcuno di lasciare il server attivo su una rete non propria.

---

## 8. Conclusioni

Il dispositivo funziona e fa quello che doveva fare: si infila la scheda, si preme un tasto (o non si preme niente, in modalità automatica), le foto finiscono nella cache locale e poi sul cloud, senza mai duplicare un upload e senza bisogno di un computer. I tre requisiti iniziali sono soddisfatti, perché si può usare a scatoletta chiusa seguendo il LED, non serve una rete già configurata e ogni impostazione è raggiungibile dal menù o dalla pagina web senza aprire un terminale.

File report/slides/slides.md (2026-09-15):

---
title: "Liquorice Backup"
subtitle: "Un dispositivo di backup fotografico in una scatoletta di liquirizia"
author: "Stefano Bucciarelli, Laboratorio di Making, A.A. 2025/26"
---

# Indice

- Introduzione: demo, idea, funzionalità
- Hardware: part list, schema, saldature, stampa 3D, assemblaggio
- Software: configurazione, moduli, design pattern, caso d'uso
- Sviluppi futuri

# Demo

- Tre video nella home del progetto:
  [github.com/stbuccia/amarelli-backup](https://github.com/stbuccia/amarelli-backup/blob/main/wiki/Home.md)
- `demo.mp4`: caching, upload in background, pausa e ripresa
- `cover.mp4`: chiusura del coperchio, blocco dello schermo
- `wifi.mp4`: nuova rete Wi-Fi da access point e pagina web

# L'idea

- Esperienza personale in viaggio: no backup per la SD della fotocamera
- Nessun DIY open source che risolve il problema
- Collezionista involontario di scatolette Amarelli

# Funzionalità e impostazioni

- Destinazione: qualsiasi remoto `rclone` (Dropbox, Drive, S3, ...) o WebDAV nativo
- **Mirroring**: le cancellazioni sulla SD si propagano al remoto
- **Pruning** della cache: subito, dopo 7 giorni, dopo 30 giorni, conserva
- Filtro file: tutti, foto (JPG+RAW), solo JPG
- Modalità: manuale passo a passo o automatica a latta chiusa (LED)
- Ogni impostazione da menù o dalla pagina web, salvata su `config.json`

# 2. Hardware

# Part list

| Componente | Ruolo | Prezzo | In uso |
|---|---|---|---|
| Raspberry Pi Zero W | cervello, Wi-Fi integrato | 34,51 € | Sì |
| Waveshare 2.13" e-Paper | schermo, CE0 | 14,69 € | Sì |
| Lettore microSD SPI | scheda fotocamera, CE1 | 2,07 € | Sì |
| LED WS2812B | stato a latta chiusa | 2,09 € | Sì |
| 4 pulsanti 6 × 6 × 6 mm | interfaccia input utente | 1,29 € | Sì |
| Reed switch + magnete | coperchio | 8,69 € | Sì |
| PowerBoost 1000C | boost 5 V + power path | n.d. | No |
| MAX17043 | fuel gauge I²C | n.d. | No |
| LiPo 803450 | batteria 1500 mAh | n.d. | No |

# Part list: note

- Totale: **110,71 €** (con sd, latta, viti, fili e biadesivo) + spedizione
- Microcomputer per esclusione: Pi 3/4/5 grandi, Pico senza OS, CM senza header
- Lettore SD su SPI e non sulla porta USB
- E-paper e non LCD: bistabile, leggibile al sole, refresh lento accettabile
- Reed in plastica: quelli in ampolla di vetro si sono rotti
- Alimentazione finale: micro-USB, niente batteria

# Il lettore SD si è rotto

::: columns
:::: column
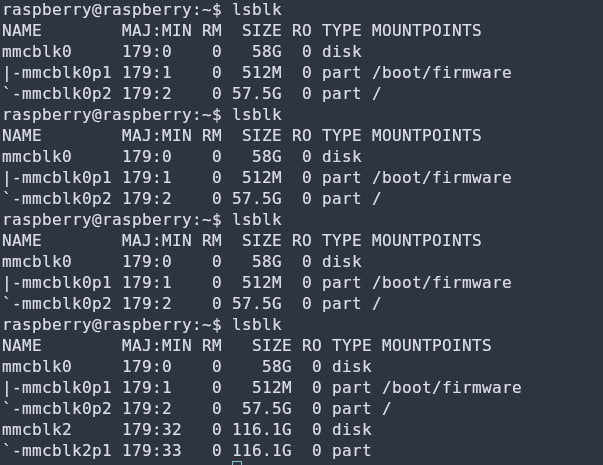
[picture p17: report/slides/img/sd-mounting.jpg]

::::
:::: column
- Rotto progressivamente in pochi giorni
- Scheda rilevata a tratti, poi più nulla
- Pipeline ok con Fake SD e cache
- Ipotesi scartata: contatti del modulo SPI
- Modulo da sostituire
::::
:::

# Schema finale

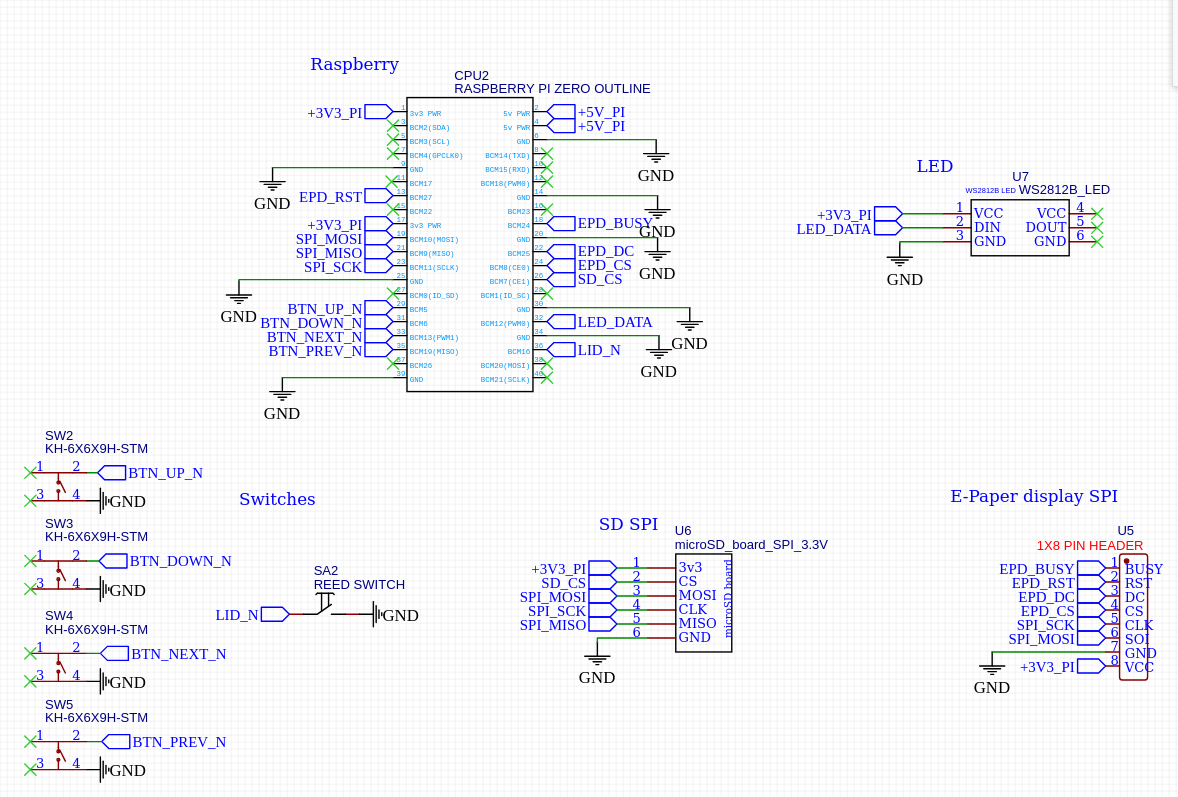
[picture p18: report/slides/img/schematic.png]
Datasheet, collegamenti con net label. RST su BCM 27 perché BCM 17 è danneggiato


# Schema finale

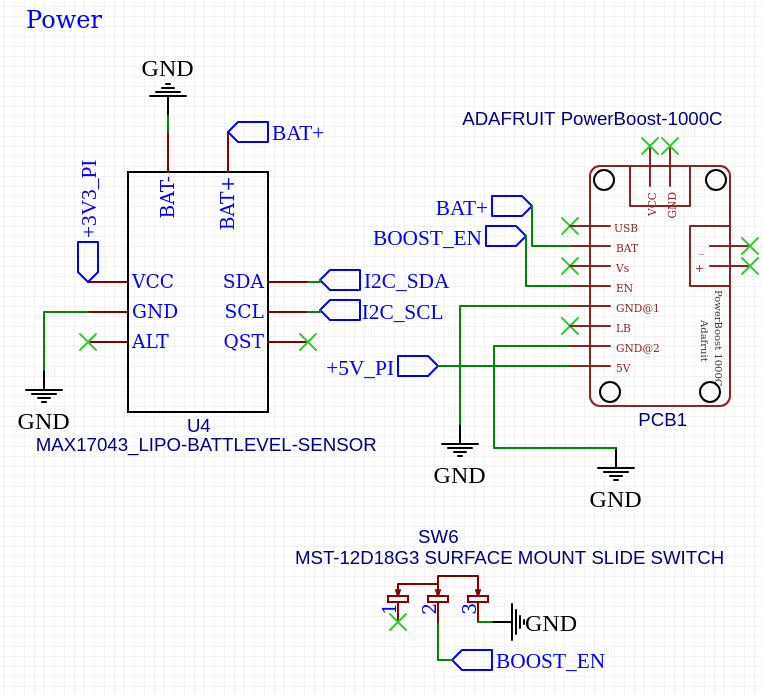
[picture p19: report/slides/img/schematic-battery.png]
Datasheet alimentazione batteria (non in uso)


# Saldature e cablaggio

::: columns
:::: column
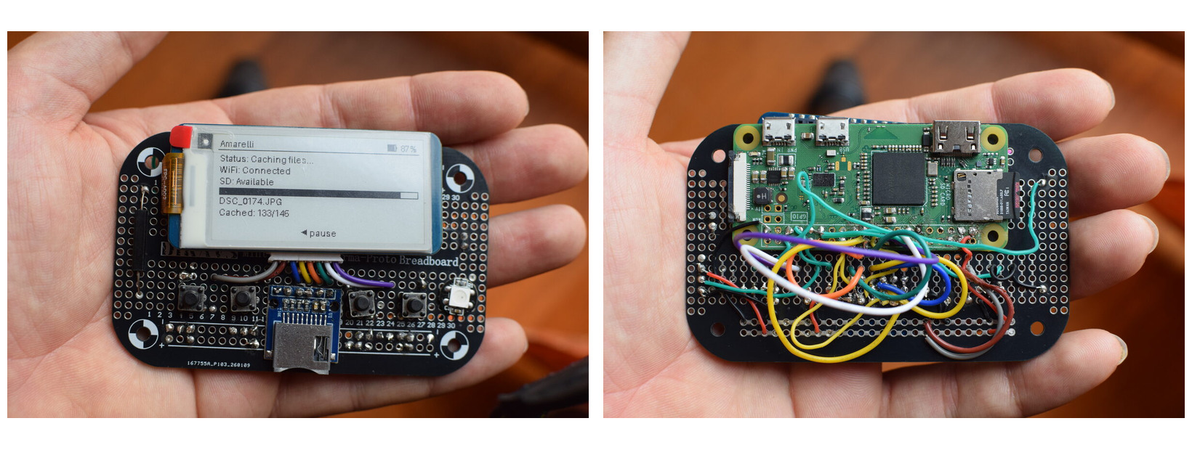
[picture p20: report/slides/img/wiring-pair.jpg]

::::
:::: column
- Perma proto board delle dimensioni esatte
- Componenti tutti sul lato frontale
- Pi: facce opposte, 8 fili
- MOSI/CLK sulla colona del lettore SD
- Cablaggio tutto sul retro
::::
:::

# Stampa 3D

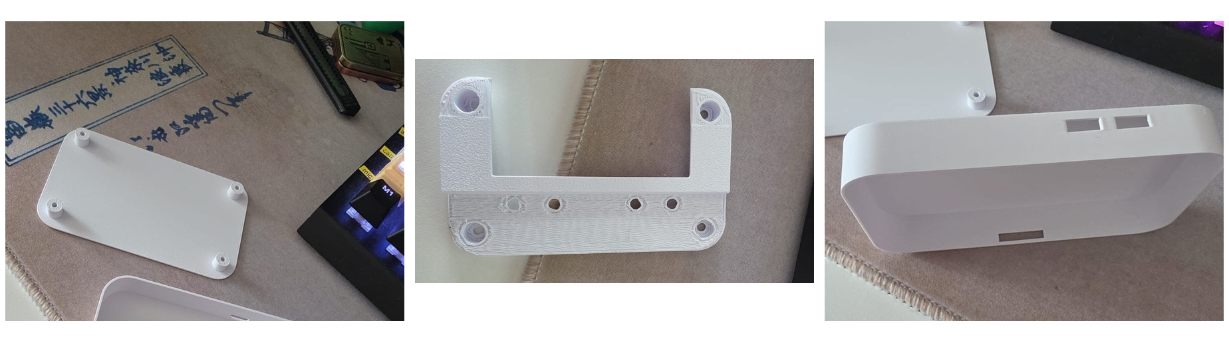
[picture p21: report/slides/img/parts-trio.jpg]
Base (solleva la board), topper (schermo e pulsanti, gradino → supporti), cover (maschera di foratura)


# Assemblaggio

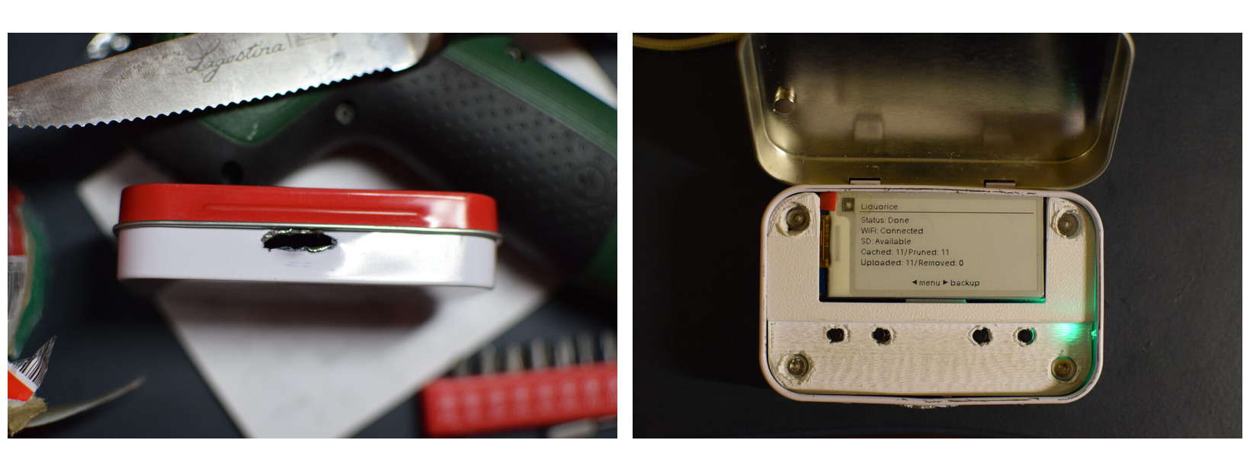
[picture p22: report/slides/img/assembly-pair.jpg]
Fori segnati con la cover e rifiniti a mano, poi base, board e topper avvitati


# 3. Software

# Configurazione

- Raspberry Pi OS Lite 32 bit, tutto in `install.sh` (idempotente)
- Lettore SD: `dtparam=spi=on` + device tree overlay
- Display `spidev0.0`, lettore `spidev0.1`, scheda `/dev/mmcblk1`
- Driver Waveshare: patch `sed` del reset BCM 17 → 27
- systemd

# Moduli

- `main.py` orchestrazione, loop
- `backup.py` macchina a stati: `cache.py` copia e pruning, `uploader.py` webdav / rclone 
- `menu.py` gestione del menu
- `config.py` file di configurazione
- `database.py` SQLite
- `wifi.py` access point, `flask_app.py` web
- `keylistener.py`: interfaccia di input 
- `display.py` e `led_status.py` interfaccia di output

# Design pattern

- Event bus: `on()` / `emit()`
- Macchina a stati (`backup.py`): IDLE, CACHING, UPLOADING, PRUNING, REMOVING, PAUSED, RETRYING, ERROR, DONE
- Repository (`database.py`): SQL solo qui, `FileRecord`
- Template method + strategy (`uploader.py`)
    - sottoclassi: `ensure_remote_dir()`, `put()`, `delete()`
- Composite (menù): struttura ad albero

# Caso pratico: caching

- BCM 19 a massa → coda 
- Main: vista attiva + stato → stato e `IDLE` = avvia
- Mount ritentato; con soli pendenti si parte senza scheda
- `Backup.start()`: impostazioni congelate, thread avviato
- Filtro estensione, confronto dimensione/mtime con il DB
- `backup:state` a ogni transizione → fase sullo schermo, LED blu lampeggiante
- `cache:file` per ogni file scandito → avanza la barra e contatori display

# Caso pratico: upload

- Pendenti dal DB
- Stato dedotto dai timestamp (`cached_at`, `uploaded_at`)
- Idempotenza: interruzione a metà → riprende senza ripristino
- `file:uploaded` a conferma di un trasferimento
- Pruning locale (upload) o pulizia del remoto (mirror): `file:pruned`, `file:remote_deleted`
- `backup:state` con `COMPLETED`: statistiche, "Done", LED verde

# 4. Sviluppi futuri

- Lettore SD: Rimpiazzare con un nuovo modulo
- Batteria: Alternativa a PowerBoost 1000C (PowerBoost 1000 Basic)
- Pulsanti più alti: topper piano, stampabile senza supporti e migliore pressione 
- PCB: schema pronto, circuito già validato

# Grazie

- Repository: [github.com/stbuccia/amarelli-backup](https://github.com/stbuccia/amarelli-backup)
- Documentazione utente e demo: [wiki/Home.md](https://github.com/stbuccia/amarelli-backup/blob/main/wiki/Home.md)

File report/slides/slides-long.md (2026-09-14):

---
title: "Liquorice Backup"
subtitle: "Un dispositivo di backup fotografico in una scatoletta di liquirizia"
author: "Stefano Bucciarelli — Laboratorio di Making, A.A. 2025/26"
---

# Indice

- Introduzione: idea e requisiti
- Hardware: scelte per esclusione
- Breadboard e circuito
- Assemblaggio
- Modellazione e stampa 3D
- Software: architettura e componenti
- Sviluppi futuri
- Conclusioni

# Il dispositivo

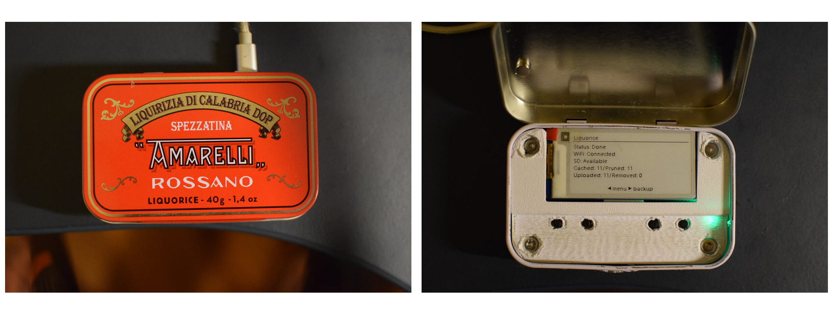
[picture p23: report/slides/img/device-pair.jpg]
Chiuso: usabile tramite LED — Aperto: e-paper 2.13" con stato "Done"


# 1. Introduzione

# 1. Cos'è

- Scatoletta di latta Amarelli → dispositivo di backup fotografico
- microSD della fotocamera nel lettore sul fianco
- Cache locale immediata → upload sul cloud in background
- Database: mai due volte lo stesso file
- Due passaggi indipendenti
    - cache: non serve Internet
    - upload: non serve la SD
- Interfaccia: e-paper 2.13", 4 pulsanti, LED RGB, pagina web
- Relazione sul *perché* delle scelte, strade sbagliate incluse

# 1.1 L'idea

- Problema reale: in vacanza fotocamera sì, portatile no
- Foto per giorni in un solo posto: la SD nella fotocamera
- Soluzioni commerciali: costose, chiuse, legate all'ecosistema
- Nessun equivalente DIY open source
- Secondo ingrediente: collezionista involontario di scatolette Amarelli

# 1.1 Dalla scatoletta al formato standard

- Amarelli ≈ 94 × 60 × 22 mm = standard di fatto delle mint tin (Altoids)
- Conseguenza 1: progetto universale, qualsiasi mint tin va bene
- Conseguenza 2: esistono componenti per quel formato
    - Mint Tin Sized Perma-Proto Breadboard
- Ispirazione: MintyPi di sudomod (Altoids + retrogaming)
- Divergenza: MintyPi usa un PCB su misura, qui perfboard cablata a mano

# 1.2 Requisiti

1. Usabile a scatoletta chiusa → LED RGB + modalità automatica
2. Nessuna rete Wi-Fi già configurata → cache/upload separati, access point proprio
3. Minimizzare gli accessi SSH → menù a bordo + pagina web

- Non sono desiderata: hanno determinato le scelte implementative

# 2. Hardware

# 2.1 Raspberry Pi Zero W

- Raspberry: notorietà e documentazione disponibile
- Modello scelto per esclusione
    - Pi 3/4/5: 85 × 56 mm, connettori oltre i 22 mm utili
    - Pico: microcontrollore, no OS, no filesystem, no rclone/SQLite, RAM
    - Compute Module 4/5: System-on-Module, no header 40 pin
- Zero: 65 × 30 mm, header 40 pin, Wi-Fi integrato (requisito, non extra)
- Zero W vs Zero 2 W: prezzo → Zero W
- GPIO e dimensioni identici: funziona anche con Zero 2 W

# 2.2 Il problema della seconda scheda

- Un solo slot microSD, occupato dal sistema operativo
- Strada 1: saldare sui pad dello slot SD del Pi
    - provata materialmente, non funziona
    - bus SDIO: una scheda sola, già occupata dal boot
- Strada 2: adattatore USB-microSD cannibalizzato
    - 4 pad (VBUS, GND, D+, D−) → PP1, PP6, P22, P23
    - SD non rilevata dal Raspberry → scartata

# 2.2 Il tentativo USB cannibalizzato

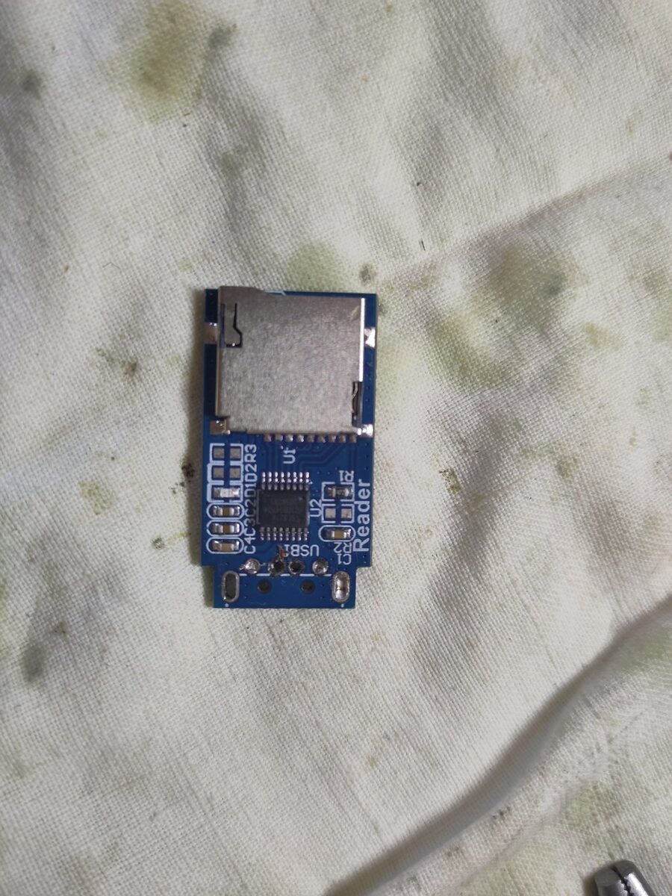
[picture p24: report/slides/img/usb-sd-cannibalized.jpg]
Connettore USB dissaldato, quattro pad saldati a mano


# 2.2 La soluzione: lettore microSD su SPI

- Modulino a sei pin sul bus SPI0
- Driver kernel `mmc_spi` → `/dev/mmcblk1`, device a blocchi normale
- Vantaggio non previsto: il meno esoso in corrente
    - con i problemi di alimentazione, l'USB non avrebbe tenuto
- Prezzo: velocità ridotta → più tempo per la copia locale
    - accettabile, il collo di bottiglia percepito è l'upload
- Bus SPI0 condiviso con lo schermo
    - display su CE0 (BCM 8), lettore su CE1 (BCM 7), MOSI e CLK in comune

# 2.3 E-paper contro LCD

- LCD: reattivo, colore, economico — ma consumo continuo
- E-paper: bistabile, consuma solo al refresh
    - stato che cambia poche volte al minuto → profilo ideale
    - leggibile in pieno sole
    - contro: refresh nell'ordine dei secondi, bianco e nero puro
- Interazione limitata → i contro non sono critici

# 2.3 Waveshare 2.13" e-Paper HAT (V4)

- 250 × 122 px, monocromatico 1 bit, controller SSD1680, SPI
- Dimensioni verificate sui limiti della lattina
- HAT preso per semplicità, ma connettore 40 pin non usato
    - impilarlo consumava tutta l'altezza disponibile
- Usato il connettore laterale a 8 fili, terminazioni femmina tagliate

# 2.4 Pulsanti

- 4 pulsanti tattili 6 × 6 × 6 mm, fra GPIO e massa
- Economici e reperibili
- Da 2 a 4: conseguenza del requisito "no SSH"
    - tutte le impostazioni modificabili a bordo → menù navigabile
- Su, giù, indietro, conferma = costo minimo per un'interfaccia decente

# 2.4 LED e reed switch

- Servono il requisito "scatoletta chiusa": schermo e pulsanti presuppongono il coperchio aperto
- LED WS2812B indirizzabile
    - molti stati da rappresentare → codifica per colore + lampeggio
- Reed switch + magnete incollato al coperchio
    - chiusura → schermo in sleep, nessun refresh inutile
    - primo errore: reed in ampolla di vetro, rotti piegando i terminali
    - sostituiti con la versione in plastica

# 2.5 Alimentazione: il tentativo fallito

- Risultato finale: nessuna batteria, alimentazione micro-USB
- È la mancanza più grande del progetto
- Batteria individuata: LiPo 803450 1500 mAh (50,7 × 34 × 8 mm)
- Tentativo 1: boost TPS61023 + caricatore LiPo separato
    - nessun power path
    - batteria sorgente e destinazione insieme → inutilizzabile sotto carica

# 2.5 Secondo tentativo e rinuncia

- Adafruit PowerBoost 1000C: power path + boost TPS61090 + segnale batteria scarica
- Test iniziali ok; con software completo il Pi si riavviava
- Nessuna diagnosi definitiva, solo ipotesi
    - picchi di corrente: Wi-Fi + refresh schermo + lettura SD + LED
- MAX17043 (fuel gauge I²C) testato con successo
- Scelta: consegnare un dispositivo affidabile via USB
- Effetto collaterale positivo: spazio libero in altezza

# 2.5 I test di alimentazione

Boost TPS61023 con caricatore separato e fuel gauge MAX17043 su I²C

# 3. Breadboard e circuito

# 3.1 Prototipazione su breadboard

- Punto di partenza: competenza elettronica bassa
- Strategia: un componente alla volta, un test ad hoc per ognuno
    - verificare di aver capito i collegamenti
    - escludere guasti fisici
- I test sono rimasti nel repository: `software/tests/hardware/`
- Diventati strumento diagnostico permanente
    - problema nel dispositivo assemblato → cablaggio o software?

# 3.1 I test sui componenti

Pulsanti (cablaggio e debounce) e LED WS2812B con reed switch

# 3.2 Lo schema elettrico

- Disegnato con EasyEDA: gira nel browser, curva di apprendimento bassa
- Non fili ma net label: stessa etichetta = connessione elettrica
- Nota su RST: la documentazione Waveshare usa BCM 17
    - sul mio Raspberry quel pin è danneggiato → spostato su BCM 27
    - patch applicata automaticamente dall'installer

# 3.2 Schema

Tutti i collegamenti verso il Raspberry Pi Zero

# 3.2 I collegamenti

| Componente | Interfaccia | Pin (BCM) |
|---|---|---|
| Display e-paper | SPI0, CE0 | DIN 10, CLK 11, CS 8, DC 25, RST 27, BUSY 24 |
| Lettore microSD | SPI0, CE1 | MISO 9, CLK 11, MOSI 10, CS 7 |
| Pulsanti | GPIO pull-up | Left 5, Down 6, Up 13, Right 19 |
| LED WS2812B | PWM0 hardware | DIN 12 |
| Reed switch | GPIO pull-up | 16 |

# 3.3 Perfboard contro PCB

- PCB: dimensioni al millimetro, nessun cablaggio, risultato professionale
    - errore irrecuperabile, alta probabilità di errore, costo con spedizione
- Perfboard: ogni errore recuperabile dissaldando, pochi euro
    - prezzo: cablaggio manuale lungo e delicato
- Scelta facilitata dalla Mint Tin Sized Perma-Proto Breadboard
    - piste pre-stampate riga/colonna, formato mint tin esatto
    - entra senza tagli; rotaie `+`/`−` distribuiscono alimentazione e massa

# 4. Assemblaggio

# 4.1 Disposizione dei componenti

- Risultato di vincoli sovrapposti; vista dall'alto simmetrica
- Schermo in alto, 4 pulsanti in linea sotto
    - ordine vim: indietro, giù, su, conferma
- LED e reed in alto, sulle colonne isolate della perma-proto (0 e 32)
    - LED affacciato al foro sulla latta, reed vicino al magnete
    - fori non condivisi → nessuna interferenza di segnale
- Lettore SD in alto: orientato perché la scheda entri diritta nel fianco

# 4.1 Il Raspberry

- Parte inferiore, capovolto sulla faccia posteriore della board
- Header saldato dal lato inferiore, bordo superiore allineato a quello della board
- Vincolo: la micro-USB deve essere raggiungibile dall'esterno
- A posteriori: senza batteria si poteva ruotare il Pi e appoggiarlo sul fondo
    - micro-USB non ruotata, come fatto con il lettore SD

# 4.2 Saldature e cablaggio

- Non saldati ma biadesivo 3M 5952 VHB: Raspberry e schermo
    - i pezzi più costosi, gli unici da recuperare → smontaggio non distruttivo
- Tutto il resto saldato, con header a pettine come supporto
- Schermo ↔ Pi: la parte più laboriosa, facce opposte della board
    - terminazioni femmina tagliate, fili passati nei fori
    - segnali dedicati (CS, DC, RST, BUSY) → pin del Raspberry
    - segnali condivisi (MOSI, CLK) → colonna del lettore SD, via piste
    - VCC/GND dalle rotaie, da pin 1 (3,3 V) e pin 39 (GND)

# 4.2 Accortezze

- Tutto il cablaggio sul retro → faccia anteriore pulita, topper in piano
- Prima di dare tensione: multimetro
    - continuità delle rotaie
    - assenza di corti fra pin adiacenti, in particolare 5 V contro 3,3 V

# 4.2 Il cablaggio

Fronte e retro: schermo e Pi allineati al bordo superiore, cavi tutti sul retro

# 4.2 Ingombro sull'asse Z

Stack (base + Pi + perfboard + schermo) = 13,90 mm, limite 22 mm

# 5. Modellazione e stampa 3D

# 5. Perché stampare in 3D

- Due benefici distinti
    - fissare il circuito in modo definitivo dentro la scatoletta
    - nascondere il circuito → risultato presentabile
- Perfboard nuda con fili a vista = prototipo
- Con due cornici stampate = oggetto

# 5. I tre pezzi

- In `hardware/3d models/`, formato `.3mf`
- Base: appoggia sul fondo, incollata con biadesivo
    - solleva la board per far stare il Raspberry, fori per l'avvitamento
- Topper: aperture per schermo e 4 pulsanti
    - pezzo estetico, copre cablaggi e saldature
- Cover: guscio esterno, non fa parte del dispositivo
    - serve come maschera di foratura

# 5. Modellazione: metodo

- Competenze CAD nulle → Onshape: parametrico, gira nel browser
- Prima di tutto una fase di misura, con calibro digitale
    - area visibile del pannello
    - posizione dei 4 pulsanti rispetto al bordo
    - quota della fessura del lettore SD, prese micro-USB
- Costruzione: schizzo sul piano frontale
    - estrusioni additive per la cornice
    - estrusioni sottrattive per fori e finestre

# 5. Il topper: il pezzo difficile

- Conseguenza di una scelta a monte: pulsanti 6 × 6 × 6 mm più bassi dello schermo
- Non una lastra piana ma un gradino: schermo su un piano, pulsanti più in basso
- In stampa: vuoto sotto la faccia dei pulsanti
    - unico pezzo con supporti (automatici, strategia tree)
    - superficie meno uniforme → rifinitura a mano con cutter e carta abrasiva

# 5. La stampa

- Bambu Lab H2D, nozzle standard 0,4 mm (stampante prestata da un amico)
- PLA Basic bianco eSUN, conservato in AMS (temperatura ambiente, essiccazione passiva)
- Bianco per richiamare il pannello e-paper e il fondo della scatoletta
- Base e cover senza supporti
- Filamento: 19 g il topper, 8 g gli altri due

# 5. I pezzi stampati

Base, topper con gradino e cover (maschera di foratura)

# 5. La scelta della scatoletta

Nove candidate, votazione fra amici e parenti: vince la n.1, la più classica

# 6. Software

# 6.1 Configurazione del Raspberry

- Raspberry Pi OS Lite 32 bit: ogni servizio grafico è sprecato
- Tutto automatizzato in `install.sh`
- Idempotente: rieseguirlo non rompe nulla, è anche strumento di riparazione
- Riconoscimento del lettore SD: `dtparam=spi=on` + device tree overlay

```
dtoverlay=anyspi,spi0-1,dev=mmc-spi-slot,speed=10000000
```

- `/dev/spidev0.0` display, `/dev/spidev0.1` lettore, scheda = `/dev/mmcblk1`

# 6.1 Driver e avvio automatico

- Driver Waveshare clonato da GitHub
    - patch `sed` del pin di reset BCM 17 → BCM 27
    - copiato nel virtualenv
- Unit systemd generata da un template (utente e percorsi reali)
- `KillSignal=SIGINT`: non termina brutalmente
    - SIGINT → `KeyboardInterrupt` → blocco `finally` di `main.py`
    - LED spento, scheda smontata, GPIO chiusi, e-paper in sleep con refresh completo

# 6.2 Ambiente di sviluppo

- Python, dipendenze in `pyproject.toml`
- Dipendenze hardware in un extra opzionale
    - `spidev`, `lgpio`, `RPi.GPIO`, `rpi_ws281x`
    - l'installazione funziona anche su PC
- Sviluppo su laptop
    - git come mezzo di sincronizzazione verso il dispositivo
    - sshfs per modifiche dirette senza passare da un commit
- Segreti (WebDAV, password AP) in `.env` fuori da git
- Configurazione non sensibile in `config.json`

# 6.3 Architettura: i moduli

- `main.py` orchestrazione, event loop
- `backup.py` macchina a stati della pipeline
- `cache.py` copia SD → cache, pruning
- `uploader.py` upload astratto: backend webdav e rclone
- `database.py` SQLite (`models.py`: FileRecord)
- `sdcard.py` rilevamento e mount della scheda
- `display.py` `menu.py` `led_status.py` `keylistener.py` interfaccia
- `eventbus.py` `config.py` `wifi.py` `flask_app.py`

# 6.3 Il principio organizzativo

- La logica di backup non sa nulla dell'interfaccia, e viceversa
- `backup.py` non importa `display.py` né `led_status.py`
- Pubblica eventi: chi è interessato reagisce
- Conseguenza: interfaccia sostituibile e backup non interrompibile da un bug di rendering

# 6.3 Macchina a stati e repository

- Macchina a stati (`backup.py`): il pattern portante
    - 9 stati: IDLE, CACHING, UPLOADING, REMOTE_CLEANUP, PRUNING, COMPLETED, PAUSED, RETRYING, ERROR
    - lista dichiarativa di fasi: stato → oggetto → metodo
    - il motore itera, salta le fasi non pertinenti, gestisce retry, pausa ed errori in un punto
    - ripresa dopo pausa: indice dello stato salvato → si riparte da lì
- Repository (`database.py`)
    - nessun altro modulo scrive SQL
    - metodi che dichiarano l'intenzione: `find_pending_uploads()`, `mark_uploaded()`

# 6.3 Event bus

- Implementazione minimale: un dizionario evento/handler, `on()`, `emit()`
- `emit()` incapsula ogni handler in try/except e logga senza propagare
    - un bug nel rendering non può interrompere un backup
    - per un dispositivo di backup è la priorità giusta
- Eventi in circolazione
    - `backup:state`, `file:cached`, `file:uploaded`
    - `key:press`, `config:set`, `ui:redraw`, `menu:opened`

# 6.3 Uploader e menù

- Template method + strategy + factory (`uploader.py`)
    - la classe astratta implementa la logica comune una volta sola
    - ciclo sui pendenti, directory remote, database, statistiche, errori
    - le sottoclassi: `ensure_remote_dir()`, `put()`, `delete()`
- Composite (menù): albero di `MenuItem`, ogni nodo può avere figli
    - padre = chiave di configurazione, figlio = valore
    - selezionare un figlio scrive la chiave: nessun codice per singola impostazione

# 6.4 Il database

- Un solo file SQLite, una sola tabella: una riga per file visto sulla scheda
- Lo stato è dedotto dai timestamp, non memorizzato in una colonna
    - `cached_at`, `uploaded_at`, `pruned_at`
    - `cache_path` valorizzato + `uploaded_at` nullo = in attesa di upload
- Risultato: idempotenza e resistenza alle interruzioni, senza logica di ripristino
- Cambio di idea a metà progetto
    - unicità sull'hash del contenuto → troppo lenta in caching
    - unicità sul percorso di origine

# 6.4 La cache

- Copia dei file dalla SD al disco locale
- Prima di copiare confronta dimensione e mtime con il record nel database
    - i file già a posto non vengono nemmeno letti
- Pruning: politica configurabile (subito, 7 giorni, 30 giorni, mai)
- Regola ferrea: si cancella solo ciò che risulta già caricato

# 6.4 Gli uploader

- WebDAV (`webdavclient3`): non esiste `mkdir -p`
    - la creazione cammina sui componenti del percorso
- Rclone: binario esterno via `subprocess` (`mkdir`, `copyto`, `deletefile`)
    - scelta obbligata: un uploader a mano per ogni servizio è improponibile
    - invocato con `--retries 1`
    - i retry devono stare in un solo posto: la macchina a stati
    - è l'unica che sa mostrare "Retrying...", far lampeggiare il LED, rispettare una pausa

# 6.4 Errori transitori e permanenti

- Transitorio → nuovo tentativo con backoff esponenziale: 5, 10, 20 s
- Permanente → backup fermo, intervento dell'utente
- Classificazione
    - parole chiave nel messaggio: `401`, `403`, `invalid credentials`
    - per rclone: exit code che non migliorano con un retry

# 6.4 Rilevamento e mount della scheda

- `lsblk --json`, si parte da `mmcblk1` (`mmcblk0` è la scheda di sistema)
- Due domande distinte, che all'inizio confondevo
    - il device esiste → serve all'interfaccia per mostrare la scheda presente
    - è montato e leggibile → serve alla logica di backup
- Mount con attesa esplicita del device node dopo `udevadm settle`
    - fra riconoscimento del kernel e nodo utilizzabile passa un tempo non nullo
    - su SPI è più lungo → senza attesa, mount fallito in modo intermittente

# 6.4 Il display

- Composizione: immagine Pillow 250 × 122 a 1 bit per pixel
- Tre livelli: status bar in alto, vista attiva al centro, legenda in basso
- Frecce disegnate come poligoni, non come caratteri
    - il font di default non ha i glifi dei triangoli → rettangolo vuoto
- Primo frame con init completa, successivi in modalità veloce
    - accumula ghosting → refresh completo all'uscita
- Redraw coalescati: eventi a raffica, uno per file
    - le viste alzano un flag, l'event loop fa un refresh per ciclo

# 6.4 Il LED

| Colore | Stato |
|---|---|
| Bianco | avvio |
| Verde | pronto oppure completato |
| Giallo | in attesa di una scheda |
| Blu (lampeggia) | copia nella cache |
| Ciano (lampeggia) | upload |
| Magenta (lampeggia) | pulizia del remoto o pruning |
| Arancione | in pausa (fisso) o in retry (lampeggia) |
| Rosso | errore |

# 6.4 Il criterio della codifica

- Lampeggio = "sto lavorando"
- Colore fisso = "sto aspettando te, o ho finito"
- A scatoletta chiusa basta questo per sapere se si può mettere via il dispositivo
- Lampeggio su un thread dedicato
    - legato all'event loop sarebbe irregolare
    - un LED irregolare sembra un guasto

# 6.4 L'input

- Due implementazioni della stessa interfaccia
    - GPIO: `gpiozero.Button`, debounce di 50 ms delegato alla libreria
    - terminale: tastiera in raw mode, decodifica delle sequenze di escape
    - la seconda permette di pilotare l'interfaccia da PC in mock
- Reed switch a parte: non è un tasto ma uno stato
    - lettura immediata all'avvio (non accendere lo schermo se parte chiuso)
    - coda di transizioni

# 6.5 Caso d'uso: dalla pressione all'avvio

- BCM 19 verso massa → debounce `gpiozero` → tasto in coda
- Event loop estrae e pubblica `key:press`
- L'handler decide su due cose: vista attiva e stato del backup
    - vista di stato + `IDLE` + tasto destro = avvia
- Modalità manuale: mount ritentato prima di partire
    - il caso normale è accendere e poi infilare la scheda
    - mount ok → cache istanziata e passata al backup
    - mount fallito ma file pendenti → si parte comunque, si può caricare senza scheda

# 6.5 La fase di cache

- `Backup.start()` congela le impostazioni in vigore
    - un cambio a metà backup non produce comportamenti misti
- Passa a `CACHING` e lancia il thread della pipeline
- Attraversa la scheda, filtra per estensione, confronta con il database
- Copia a chunk su file temporaneo, rename atomico, scrittura del record
- Un evento per ogni file → contatori e barra di avanzamento
- Il LED è già blu lampeggiante: aveva ricevuto il cambio di stato

# 6.5 La fase di upload

- Pendenti dal database, percorso remoto che preserva la struttura di cartelle
- Successo → file marcato come caricato
- Fallimento → contatore tentativi incrementato, file resta pendente
- Rete caduta → `RETRYING`, LED arancione lampeggiante
    - backoff esponenziale spezzettato in intervalli da 50 ms
    - una richiesta di pausa viene raccolta subito
    - dopo tre tentativi → `ERROR`

# 6.5 Chiusura e configurazione

- Pruning locale (modalità upload) oppure pulizia del remoto (modalità mirror)
    - mutuamente esclusive per costruzione
- Fine: `COMPLETED`, statistiche aggregate, stato "Done"
- Percorso di una modifica di configurazione: un solo evento `config:set`
    - `Config` riscrive `config.json` → sopravvive al riavvio
    - `Backup` applica la modalità al backup successivo
    - `main` ricostruisce l'uploader se è cambiato il backend

# 6.6 Modalità mock

- `--mock` sostituisce l'hardware con sostituti software
    - schermo no-op, tastiera invece dei pulsanti, reed disattivato, LED in log
- Vista corrente stampata su stdout a ogni refresh

```
[DISPLAY] BACKUP | Caching files... (CACHING)
| wifi:ON sd:ON | cached:12 pend:12 up:0 bar:12/40
```

- Con "Fake SD" e rclone verso una cartella locale: intera pipeline su PC
- È ciò che ha reso possibile sviluppare l'interfaccia senza il dispositivo

# 6.6 Wi-Fi e captive portal

- `wifi.py` via `nmcli`: crea l'access point (SSID e password dal `.env`), scansiona, connette, dimentica
- Captive portal
    - server DNS che risponde a ogni query con l'indirizzo del dispositivo
    - endpoint di rilevamento tipici di Android e iOS
- Effetto: collegandosi alla rete il telefono apre da solo la pagina
    - nessun indirizzo IP da conoscere o digitare

# 6.6 La pagina web

- Flask sulla porta 5000
- Scelta della rete Wi-Fi, tutte le impostazioni del menù, più il remoto rclone, log
- Passa dallo stesso evento `config:set`
    - menù e pagina web sono due interfacce sullo stesso meccanismo, non possono divergere
- Limite noto: `0.0.0.0:5000`, HTTP, nessuna autenticazione
    - sull'access point protetto da WPA il rischio è contenuto
    - su una rete condivisa no
- Logging: console INFO, file DEBUG, servizio via `journalctl`

# 7. Sviluppi futuri

# 7. Batteria e pulsanti

- Batteria: il primo punto, il PowerBoost 1000C c'è già
    - misurare la tensione sul rail 5 V durante i picchi
    - aggiungere capacità di bulk vicino al carico, vedere se il problema si sposta
    - poi MAX17043 su I²C per lo stato di carica sullo schermo
- Pulsanti più alti: costo quasi nullo, semplifica due fasi
    - il topper diventa una lastra piana
    - stampabile senza supporti, superficie migliore

# 7. PCB, interfaccia, sicurezza

- PCB: migliorerebbe la riproducibilità
    - spariscono tutte le saldature a mano e il rischio che portano
    - schema EasyEDA già pronto, circuito validato sul campo → rischio ridotto
- Interfaccia: il pannello è sfruttato in modo essenziale
    - icone dedicate, tempi stimati, refresh parziali (solo la barra)
- Server web: autenticazione, anche una basic auth con credenziali nel `.env`
    - il minimo prima di lasciarlo attivo su una rete non propria

# 8. Conclusioni

- Il dispositivo funziona e fa quello che doveva fare
    - si infila la scheda, si preme un tasto (o niente, in automatico)
    - cache locale, poi cloud, senza duplicare un upload, senza un computer
- I tre requisiti sono soddisfatti
    - usabile a scatoletta chiusa seguendo il LED
    - nessuna rete già configurata necessaria
    - ogni impostazione dal menù o dalla pagina web, senza terminale
- Manca la batteria: rinuncia consapevole per consegnare qualcosa di affidabile

# Grazie

- Repository: github.com/stbuccia/amarelli-backup
- Documentazione utente: `wiki/Home.md`

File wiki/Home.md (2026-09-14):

# Liquorice Backup

This project turns a cute Amarelli liquorice tin (like [these](https://www.amarelli.it/categoria-prodotto/liquirizia/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)) into a small photo backup box.

You put your camera's micro sd card into the box and the box copies the photos and sends them to a place you pick: Webdav server, Nextcloud, Google Drive, Dropbox, and more. A small screen shows the progress, an LED strip shows the state by colour, and you can interact with buttons and scrren and changing options with menu. You could also configure wifi and some options via web page accessible from external device.

## Demo

### 1. Caching, upload and pause: `demo.mp4`

Shows how the box copies photos to the local cache immediately (no internet needed), then uploads them in background when Wi-Fi is available, with the ability to pause/resume the upload from the buttons/menu.

https://github.com/user-attachments/assets/318411bd-aac7-48a8-9b28-a56dbcda2e6b

### 2. Closing the tin and screen lock: `cover.mp4`

Closing the lid triggers the screen lock / cover handling.

https://github.com/user-attachments/assets/9cb672e0-f81e-46bb-84d8-f59a53d57a41

### 3. Configuring another Wi-Fi: `wifi.mp4`

How to connect to a new Wi-Fi network from the box: start the access point from the menu, connect from phone/laptop and open `http://<box-ip>:5000` to enter the new credentials.

https://github.com/user-attachments/assets/718ee54f-ab58-4cac-961d-e77d3bd64055

This guide takes you from zero to a working box. Read the chapters in order the first time.

## Chapters

1. [What you need](01-what-you-need.md): the parts to buy, where do you find them and how much they cost
2. [Wiring and assembly](02-wiring-and-assembly.md): how to connect the parts in the board
3. [Prepare the SD card and OS](03-prepare-os.md): set up Raspberry Pi OS, user and service
4. [Install the software](04-install-software.md): run the installer
5. [Backup destination](05-backup-destination.md): configure cloud service where photos go
6. [Daily use](06-daily-use.md): User guide
7. [Run as a service and troubleshooting](07-service-and-troubleshooting.md): if you have a problem you should check here

## How it works

- You insert the camera card into a small card reader on the box
- The box copies the photos to a local cache first, then uploads them
- For the caching internet connection is not needed, for the upload sd card is not needed
- A small database remembers what it already sent, so it never sends the same file twice
- You can check the box work watching the eink screen or the led colour
- To connect to an unkwown wifi net, you can start an access point from menu, and then connecting from an external device, then going to the web page at `http://<box-ip>:5000`, and setting wifi credentials

## Two ways to run it

- **On the Raspberry Pi**: the real box, with screen, buttons, LED and card reader
- **Mock mode on a normal PC**: no hardware. Good for trying the software in your everyday PC

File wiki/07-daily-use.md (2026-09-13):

# 6. Daily use

Day to day, you use three things: the screen, the four buttons, and the LED strip. There is also a web page for settings.

## Making a backup

1. Take the microSD card out of your camera
2. Put it in the box's card reader
3. The box finds the card and mounts it at `/mnt/liquorice-sd`. The screen shows `Ready`
4. Start the backup (press the confirm button, or let it run on its own in automatic mode, see below)
5. The box copies the photos to a local cache, then uploads them. The screen shows the progress
6. When the LED turns green and the screen says it is done, take the card out

If there is no card and nothing waiting in the cache, the screen shows `Waiting for SD card`.

The main screen also reports the network: `WiFi: Connected (CasaWiFi)` with the name of the network the box is on, `WiFi: Connected (AP liquorice)` while its own hotspot is up, or `WiFi: Disconnected`.

## The buttons

There are four buttons, from left to right they are: **Up**, **Down**, **Confirm/Right**, **Back/Left**.

In the menu:

- **Up / Down**: move between items
- **Confirm**: open a submenu or choose a value
- **Left**: go back, or close the menu at the top level

During a backup:

- Any button **pauses** the backup. This is on purpose, so it works no matter how your buttons are wired
- While paused: **Confirm** resumes, **Back** opens the menu

## The menu on the box

Press Left from the main screen to open the menu:

- **WiFi**
  - *Start AP + Web server* : the box makes its own Wi-Fi network and starts the settings web page on it, so you can reach it when there is no other network. For security, the web page is only ever reachable through this hotspot, never on your regular Wi-Fi. The legend at the bottom tells you how it went: `web 192.168.4.1:5000` when both are up, `AP ok - WEB ERROR!` if the hotspot is up but the page is not
  - *Show IP* : show the box's IP address
  - *Stop AP* : turn off the hotspot and the web page, and rejoin a Wi-Fi network the box already knows: first the one it was using before the hotspot, then any other saved network in range (up to three attempts). The legend shows which one it landed on (`WiFi: <name>`). This does **not** forget any saved network or change your Wi-Fi setup (to forget a network, use *Forget* on the web page instead)

Both entries do their work in the background: the screen shows `Starting AP...` or `Stopping AP...` right away and you can keep using the menu while NetworkManager takes its few seconds. If you pick one while the other is still running, the legend says `WiFi busy...` and the request is ignored, so the box never runs two network operations on the same radio.
- **Mode**
  - *Upload only* : copy photos up; never delete on the remote
  - *Mirroring* : make the remote match the source (can delete remote files)
- **Cache** : how long to keep the local copies after upload
  - *Delete now*, *After 7 days*, *After 30 days*, *Keep forever*
- **File type** : what to back up
  - *All files*, *Photos only (JPG+RAW)*, *JPG only*
- **Operation**
  - *Manual*: you confirm each backup
  - *Automatic (LED)*: the box mounts, caches and uploads on its own; you can keep the box closed and follow it by the LED colour
- **Debug**
  - *Fake SD*: `Off (real SD)` reads from the SPI card reader, `On (fake-sd dir)` reads the photos from the local folder `~/liquorice/fake-sd` instead (the folder is created if missing). Handy to try a full backup with no card inserted; the switch takes effect right away, no restart needed.

The menu saves your choices to `config.json`.

## What the box is doing during a backup

The screen and the LED both tell you which step the box is on. There are only a handful of steps, and they mostly follow one another in order.

When you start a backup, the box first **caches** the photos: it copies them off the card onto its own storage. Then it **uploads** them to wherever you pointed it. That is the whole job in *Upload only* mode. Afterwards it may do a  **pruning**: old cached copies you asked it not to keep forever.

*Mirroring* mode is slightly different. Instead of pruning, it does a **remote cleanup**: if you deleted photos on the card (also from the camera), it removes them from the remote too, so the two match. You never see both cleanup and pruning in the same run, which one happens depends on the mode you chose.

When everything goes through, the box lands on **completed** and waits. Press the confirm button and it drops back to idle, ready for the next card.

A few things can interrupt that straight line:

- **You press a button mid-backup.** The box pauses. It remembers exactly where it was, so pressing Right picks up from that step; pressing Left opens the menu instead.
- **The network hiccups.** The box doesn't give up: it waits a moment and tries the same step again. On the screen and LED this shows as *retrying*. If it keeps failing after a few tries, it stops.
- **Something it can't fix, like a wrong password.** The box stops on **error** and shows a short message. Fix the cause, press confirm to clear it, and start again.

So the happy path is just *idle → caching → uploading → completed*, with pruning or remote cleanup slipped in near the end depending on the mode, and pause, retry and error branching off only when they need to.

## LED colours

The LED strip tells you the state at a glance:

| Colour | Meaning |
|---|---|
| White | Booting |
| Green | Ready, or done |
| Yellow | Waiting for a card |
| Blue | Copying files to the cache |
| Cyan | Uploading |
| Magenta | Cleaning up the remote / pruning old cache |
| Orange | Paused, or retrying |
| Red | Error |

During long steps (caching, uploading, cleanup, pruning, retrying) the LED blinks.

## The lid (reed switch)

When you shut the lid, the magnet trips the reed switch and the screen sleeps to save power. Open the lid to wake it. Backups keep running with the lid shut.

## The web page

The box runs a small web page, but only while its hotspot is on: **`http://<box-ip>:5000`**

Use *WiFi > Start AP + Web server* to turn on both together, connect your phone or computer to the box's own Wi-Fi network, find the IP with *WiFi > Show IP* (it stays on screen until you change screen again), then open the page. From there you can also set the box's regular Wi-Fi network. When you are done, *WiFi > Stop AP* stops the hotspot and the web page, and tries to rejoin a previously known network if one is in range.

The box only has one Wi-Fi radio, so it cannot run the hotspot and join your regular network at the same time: connecting to a new network from the web page turns the hotspot off first. For that reason a secured network you have never used asks for its password right there in the list, next to *Connect*: without it the attempt would fail with `Secrets were required, but not provided` after the hotspot (and this page) had already gone offline. Networks you already saved connect straight away with their stored password, and open networks need nothing. The confirmation dialog reminds you that the page goes offline while the box tries.

If the new network's password is wrong or it cannot be reached, the box brings its own hotspot back automatically, so it is never left with neither the hotspot nor a working connection. Reload `http://192.168.4.1:5000` after rejoining the box's own network to see what happened.

Next: [Run as a service and troubleshooting](07-service-and-troubleshooting.md).

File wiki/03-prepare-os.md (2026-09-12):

# 3. Prepare the SD card and OS

Here you put a working Raspberry Pi OS on the Pi's own microSD card (not the camera card) and log in over the network

## 1. Write the operating system

1. Download and open **Raspberry Pi Imager** on your computer
2. Choose **Raspberry Pi OS Lite (32-bit)**. "Lite" has no desktop, which is what this project wants
3. Choose the Pi's microSD card as the target
4. Open the settings (the gear icon) before you write, and set:
   - **Hostname** -- for example `liquorice`. Then you can reach the box as `liquorice.local`.
   - **Username** -- pick any username you like, with your own password. The installer adapts the service to whatever user you choose
   - **Enable SSH** -- turn it on, with password login
   - **Wi-Fi** -- enter your network name, password, and country
5. Write the card and wait for it to finish.

> The examples below use the username `raspberry`: replace it with yours. Nothing
> in the project depends on it, the service is generated at install time from the
> user and the folder you install from.

## 2. First boot and login

1. Put the card in the Pi (the Pi's own slot, not the external reader)
2. Power the Pi on. Wait a minute or two for the first boot
3. From your computer, connect over SSH:

   ```bash
   ssh raspberry@liquorice.local
   ```

   Use your own username instead of `raspberry`. If `liquorice.local` does not work, find the Pi's IP address in your router and use it: `ssh <user>@<ip>`

## 3. Update the system

Once you are logged in:

```bash
sudo apt update && sudo apt full-upgrade -y
sudo reboot
```

Log back in after the reboot

## 4. Check Python

The software needs Python 3.10 or newer. Raspberry Pi OS Lite already has it.
Check:

```bash
python3 --version
```

## 5. Get the project

Clone the project into your home folder, so it ends up at `~/liquorice-backup`:

```bash
cd ~
git clone <repository-url> liquorice-backup
cd liquorice-backup
```

If `git` is missing, install it first with `sudo apt install -y git`

Now install the software: [Install the software](04-install-software.md).

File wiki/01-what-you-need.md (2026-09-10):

# 1. What you need

Buy or find these parts before you start. I have ordered this from Italy, some links could not works in other states, but surely you could find with normal text research.

## Main parts

| Photo | Part | Notes | Link | Price |
|---|---|---|---|---|
|RPi| Raspberry Pi Zero W / 2W | The brain of the box. I have used the Zero W, but the Zero 2 W is also better | [Aliexpress](https://it.aliexpress.com/item/1005005171008740.html) | 34.51€ |
|box| An Amarelli liquorice tin | You could use also other thin that has the standard 94 x 60 x 22  mm. You buy the case, but also you have the liquorices| Local market, but you can order it on [Amarelli website](https://www.amarelli.it/categoria-prodotto/lattine-amarelli/) | 4.50€ |
|sd| microSD card for the Pi | As you want from 16 GB, but not much lower to camera SD card, I use a 64 GB. This holds the system, it is not for the camera, but space is also used for local copy (caching) | [Aliexpress](https://it.aliexpress.com/item/1005009911349196.html) | 22.99€ |
|board| Mint Tin-Sized Perma-Proto Breadboard | Luckly someone produces this board that fits perfectly | [Aliexpress](https://it.aliexpress.com/item/1005002684081953.html)| 2.72€ |
|screen| Waveshare 2.13" e-Paper HAT (V4) | The screen. It must be the V4 version. Other versions use a different driver. | [Washare website](https://www.waveshare.com/product/displays/e-paper/2.13inch-e-paper-hat-plus.htm) | 14.69€ |
|sd-spi| External microSD reader (SPI) | Reads the camera card. It must be an SPI reader, not a USB one. You push the camera card in here. | [Aliexpress](https://www.aliexpress.com/item/1005009513901655.html) | 2.07€ |
|led| WS2812B LED | Need one, but also more is a good idea | [Aliexpress](https://it.aliexpress.com/item/1005009513901655.html) | 2.09€ |
|buttons| 4 push buttons  6 x 6 x 6 | For the menu on the box, you could also take taller ones. At least four | [Aliexpress](https://it.aliexpress.com/item/1005006046180384.html) | 1.29€ |
|reed| Reed switch + small magnet | A magnet switch, you must prefer the plastic ones beacause are less fragile. | [Amazon](https://www.amazon.it/dp/B07Z4RR4QV) | 8.69€ |
|screw| M3 x 6mm Flat Head Screws | For assembly 3d printed models | [Amazon](https://www.amazon.it/dp/B0FZBX7NF3) | 7.48€ |
|wires| 16-30AWG 5 Colors DIY Wire Silicone | For wiring components | [Aliexpress](https://it.aliexpress.com/item/1005007671008743.html) | 5.99€ |
|tape| 3M 5952 Strong Double Sided Adhesive Tape VHB | For fixing parts | [Aliexpress](https://www.aliexpress.com/item/1005007671008743.html) | 2.69€ | 

Total price: **110.71€** + shipping. This price is what I actually paid, could change depending location and when parts are ordered

## Needed but not included in price

All these object I had already, so the are not buyed

- Power supply micro-USB, 5V 2 A or more
- Electric soldering iron
- Multimeter
- Caliber
- Glue
- 3d printed models

When you have the parts, go to [Wiring](02-wiring.md).

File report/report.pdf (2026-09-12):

# Liquorice Backup

Un dispositivo di backup fotografico in una scatoletta di liquirizia

Relazione per l'esame di Laboratorio di Making Alma Mater Studiorum, Università di Bologna Anno Accademico 2025/26

Autore: Stefano Bucciarelli
Repository: https://github.com/stbuccia/amarelli-backup
Documentazione utente (wiki): https://github.com/stbuccia/amarelli-backup/blob/main/wiki/Home.md (https://github.com/stbuccia/amarelli-backup/blob/main/wiki/Home.md)


Figura 1: Dispositivo chiuso — scatoletta Amarelli rossa (usabile a coperchio chiuso tramite LED).


Figura 2: Dispositivo aperto — e-paper 2.13" con stato "Done" e LED verde, topper bianco.

## Indice

Introduzione
Hardware
Breadboard e circuito
Assemblaggio
Modellazione e stampa 3D
Software
Sviluppi futuri
Conclusioni

## 1. Introduzione

Questa relazione è in italiano perché è finalizzata all'esame, mentre tutto il resto del repository è in inglese, per garantire migliore riprodubilità.

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
Liquorice Backup è un dispositivo di backup fotografico costruito dentro una scatoletta di latta di liquirizia Amarelli. L'utilizzo è il seguente, si infila la microSD della fotocamera nel lettore sul fianco e il dispositivo copia subito le foto nuove in una cache locale per poi caricarle in background sul cloud. Un database tiene traccia di cosa ha già fatto, così non carica mai due volte lo stesso file.

I due passaggi sono deliberatamente indipendenti: per fare la cache non serve Internet, per fare l'upload non serve la SD. È questa separazione che rende il dispositivo utile in viaggio, che è il caso d'uso per cui è nato.

L'interazione avviene tramite uno schermo e-paper da 2.13", quattro pulsanti, un LED RGB e, per configurazioni più comode, come per impostare una connessione a una nuova rete WiFi, una pagina web servita dal dispositivo stesso.

Questa relazione si concentra sul perché delle scelte e sui dettagli implementativi, comprese le strade sbagliate. Non è un manuale, quindi chi volesse riprodurre il progetto o usarlo come utente finale trova tutto nella wiki del repository. (https://github.com/stbuccia/amarelli-backup/blob/main/wiki/Home.md)

### 1.1 L'idea

L'idea nasce da un problema reale: quando vado in vacanza porto la fotocamera ma non il portatile, e questo significa che per giorni le foto vivono in un unico posto, la scheda SD nella fotocamera, sperando sempre che non si corrompa. Esistono dispositivi commerciali che risolvono il problema, ma sono costosi, chiusi e legati all'ecosistema del produttore, e non ho trovato un progetto DIY open source equivalente.

Il secondo ingrediente è che il mio gusto apprezza abbondantemente le liquirizia Amarelli e, di conseguenza, un collezionista involontario delle loro scatolette di latta.

Per il progetto però ho scoperto che le lattine Amarelli misurano circa 94 × 60 × 22 mm, che è uno standard di fatto per le scatoline delle caramelle alla menta (ad esempio le Altoids) hanno praticamente le stesse dimensioni. Questo ha due conseguenze concrete. Il progetto diventa universale, perché chi non trova le scatolette Amarelli può usare qualsiasi altra mint tin standard. E come vedremo successivamente esistono già componenti pensati per quel formato, in particolare la Mint Tin Sized Perma-Proto Breadboard, che entra nella scatoletta senza tagli.

L'ispirazione formale viene dal MintyPi di sudomod, una console portatile per retrogaming costruita in una scatoletta di Altoids che avevo visto anni fa su YouTube. Da lì viene la voglia di provarci, ma le due implementazioni divergono, perché MintyPi si basa su un PCB progettato su misura mentre qui ho scelto la strada della perfboard cablata a mano (la scelta è rimandata al paragrafo 3.3).

### 1.2 Requisiti

Oltre a garantire il funzionamento sopra citato ho fissato tre ulteriori requisiti, che poi hanno determinato alcune scelte implementative successive:

Usabile anche a scatoletta chiusa. In viaggio il dispositivo starà in uno zaino, non su un tavolo, quindi serve un feedback che funzioni senza guardare lo schermo (il LED RGB) e una modalità automatica in cui il backup parte da solo.
Nessuna dipendenza da una rete Wi-Fi già configurata. Un dispositivo da viaggio si trova per definizione su reti sconosciute, da cui la separazione fra cache e upload e la possibilità di far creare al dispositivo un proprio access point.
Minimizzare gli accessi via SSH. Se per cambiare un'impostazione devo aprire un terminale, il dispositivo non è finito: da qui il menù a bordo e la pagina web.

## 2. Hardware

### 2.1 Il microcomputer: Raspberry Pi Zero W

Ho puntato su Raspberry Pi per la notorietà e per la quantità di documentazione disponibile. La scelta del modello è stata un processo di esclusione.

La gamma "grande" (Pi 3, 4, 5) l'ho esclusa per le dimensioni: 85 × 56 mm, e con i connettori Ethernet e USB-A pieni supera in altezza i 22 mm utili della scatoletta.

La gamma Pico l'ho esclusa perché essendo un microcontrollore non esegue un sistema operativo, ed avrei avuto complicazioni a riguardo, come: niente filesystem montabile, nessun modo di far girare rclone o SQLite, e una memoria RAM troppo piccola.

I Compute Module 4 e 5 li ho esclusi perché sono System-on-Module, non schede complete e non hanno l'header a 40 pin.

Restava la gamma Zero: 65 × 30 mm, header a 40 pin come le sorelle maggiori, Wi-Fi integrato, che qui è un requisito e non un extra. Fra Zero W e Zero 2 W ho scelto lo Zero W per il prezzo, molto inferiore al momento dell'acquisto, accettandone il limite. Avendo i due modelli identici GPIO e dimensioni, il progetto funziona senza modifiche anche con uno Zero 2 W.

### 2.2 Il lettore microSD: il problema della seconda scheda

Il Pi Zero ha un solo slot microSD, occupato dal sistema operativo, quindi serviva una seconda porta per la scheda della fotocamera. Ho valutato tre strade.

La prima era saldare sui pad dello slot SD del Pi. L'ho provato materialmente: non funziona, e a posteriori è ovvio, perché quello slot è collegato al controller SDIO del SoC, che gestisce una scheda sola ed è già occupato dal boot. Non si possono mettere due schede sullo stesso bus senza un controller che le multiplexi.

La seconda era cannibalizzare un adattatore USB-microSD e dissaldare il connettore USB liberando i quattro pad come mostrato in figura (VBUS, GND, D+, D-) :

1.

2.

3.


Figura 3: Lettore USB-microSD cannibalizzato: connettore USB dissaldato, visibili i quattro pad saldati a mano. Strada provata su banco ma scartata perché la Raspberry non rilevava la scheda.

Per poi collegare i quattro pad del connettore a quattro pad della Raspberry (VBUS in PP1, GND in PP6, D+ in P22 e D- in P23) tramite fili saldati. In fase di test è stata provata questa strada ma dalla Raspberry non veniva letta la SD, quindi è stata scartata.

La seconda, che è quella scelta, è un lettore microSD su SPI: un modulino con sei pin che si attacca al bus SPI0. Il kernel Linux ha il driver mmc_spi , quindi la scheda diventa un normale device a blocchi ( /dev/mmcblk1 ) montabile come qualsiasi altro. Si è rivelata giusta anche per una ragione che all'inizio non avevo considerato: è la meno esosa in termini di corrente, e visti i problemi di alimentazione descritti più avanti l'opzione USB non avrebbe comunque tenuto.

Il prezzo da pagare è la velocità più ridotta, che si traduce in maggior tempo per la copia locale precedente all'upload remoto. È accettabile perché il collo di bottiglia percepito è comunque l'upload sul cloud.

Un dettaglio importante è che il lettore condivide il bus SPI0 con lo schermo: lo schermo sta su CE0 (BCM 8), il lettore su CE1 (BCM 7), mentre MOSI e CLK sono in comune. È il funzionamento normale di SPI, dove il chip-select decide chi ascolta, ma richiede una configurazione esplicita.

### 2.3 Lo schermo: e-paper contro LCD

Ho valutato sia un display e-paper sia un LCD: L'LCD vince su reattività, colore e prezzo, ma consuma in modo continuo. L'e-paper ha le proprietà opposte, ed entrambe sono allineate ai requisiti: è bistabile, quindi l'immagine consuma solo durante il refresh, che per un dispositivo il cui stato cambia poche volte al minuto è il profilo ideale, ed è leggibile in pieno sole. I contro sono il refresh lento, il bianco e nero puro, nell'ordine dei secondi per un aggiornamento completo, ma dal momento che l'interazione utente è comunque limitata non ho valutato questi fattori come eccessivamente critici.

Ho scelto un Waveshare 2.13" e-Paper HAT (V4): 250 × 122 pixel, monocromatico a 1 bit, controller SSD1680, interfaccia SPI, controllando che la dimensione rientrasse nei limiti imposti dalla lattina. Nonostante abbia preso l'HAT per semplicità, ma non ho usato il suo connettore a 40 pin, perché impilarlo sopra il Raspberry avrebbe consumato tutta l'altezza disponibile. Ho usato invece il connettore laterale a 8 fili, tagliando le terminazioni femmina per saldare direttamente sulla board (vedi paragrafo 4.2).

### 2.4 Pulsanti, LED e reed switch

Quattro pulsanti tattili 6 × 6 × 6 mm, scelti per economicità e reperibilità, collegati fra il proprio GPIO e massa. Il numero è una decisione di progetto: inizialmente pensavo che due bastassero, ma il requisito di minimizzare gli accessi SSH implicava che tutte le impostazioni fossero modificabili a bordo, e quindi un menù navigabile. Con quattro tasti (su, giù, indietro, conferma) la navigazione in un menù è naturale, quindi mi sono sembrati il costo minimo per un'interfaccia decente.

Gli altri due componenti servono al primo requisito, l'usabilità a scatoletta chiusa, che schermo e pulsanti non soddisfano perché presuppongono entrambi il coperchio aperto.

Il primo è un LED indirizzabile WS2812B: la scelta dell'RGB invece di LED monocromatici è dettata dal numero di stati da rappresentare e la codifica avviene per colore, più il lampeggio come dimensione aggiuntiva (vedi paragrafo 6.4).

Il secondo è un reed switch, un interruttore che si chiude in presenza di un campo magnetico, abbinato a un magnetino incollato al coperchio: chiudendo la scatoletta il contatto si chiude e il software manda lo schermo in sleep, risparmiando energia ed evitando refresh inutili di un pannello che nessuno sta guardando. Qui ho sbagliato al primo tentativo comprando i reed in ampolla di vetro, i più comuni ed economici e anche estremamente fragili: si sono rotti mentre piegavo i terminali per farli stare nella board. Sono passato alla versione in plastica, che sicuramente si è prestata di più per essere maneggiata (vedi Figura 7 per il test su breadboard del reed in vetro).
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

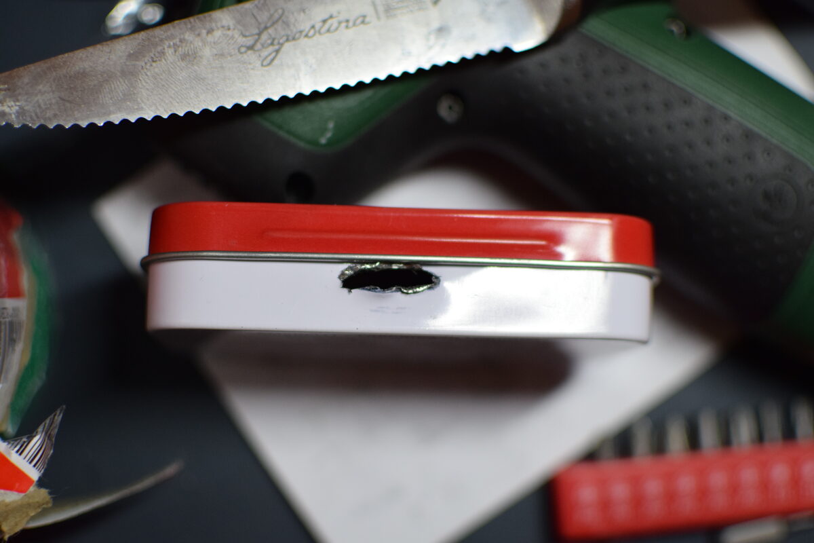
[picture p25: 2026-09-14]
report/slides/img/tin-sd-hole.jpg

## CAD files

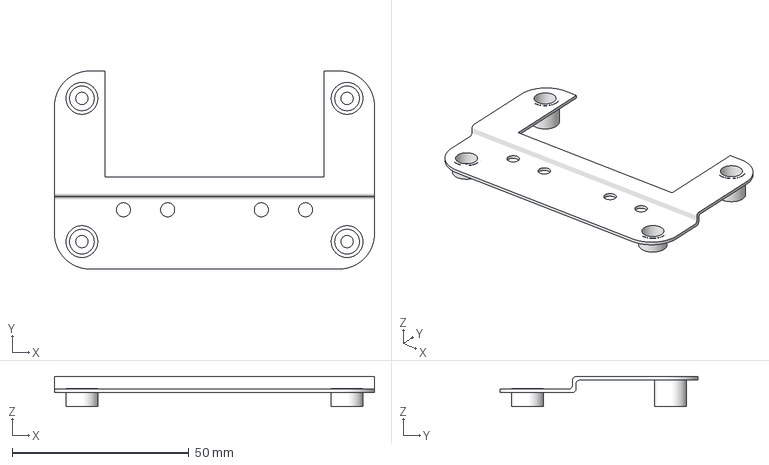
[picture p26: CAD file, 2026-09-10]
hardware/3d models/topper.3mf
90.5 x 56.0 x 8.60 mm

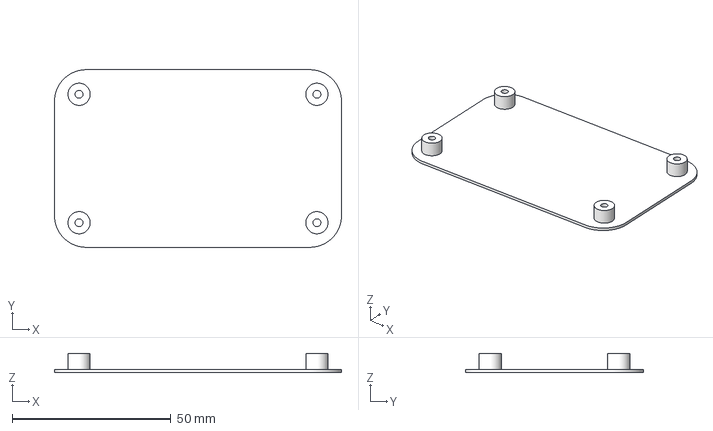
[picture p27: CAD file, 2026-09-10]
hardware/3d models/base.3mf
90.5 x 56.0 x 6.00 mm

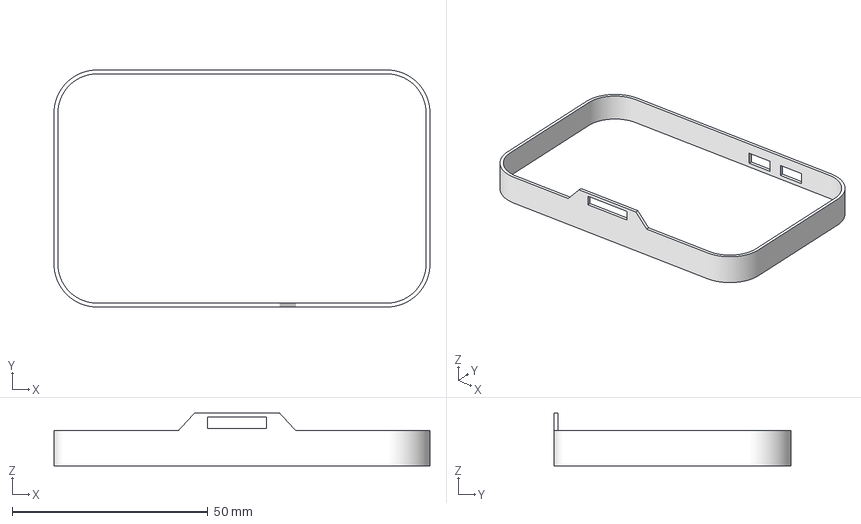
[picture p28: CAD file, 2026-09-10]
hardware/3d models/cover.3mf
96.0 x 60.5 x 13.5 mm

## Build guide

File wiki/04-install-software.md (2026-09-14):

# 4. Install the software

The project has an installer script. It does the hard work: system packages, SPI setup, the Python environment, the display driver, GPIO permissions, and the auto-start service.

Run it from inside the project folder, as your normal user. Do not use `sudo`; the script asks for `sudo` itself when it needs it.

```bash
cd ~/liquorice-backup
./install.sh
```

## What the installer does

- Installs system packages: `git`, `network-manager`, Python build tools, image libraries, and `rclone`.
- Turns on SPI and adds the setting for the card reader (at 10 MHz), so both chip-selects show up.
- Creates the mount point `/mnt/liquorice-sd` and the data folder `~/liquorice/cache`
- Creates a Python environment in `.venv` and installs the app into it
- Downloads the Waveshare screen driver, fixes the reset pin to BCM 27, and copies it into the environment
- Adds your user to the `gpio`, `kmem` and `spi` groups, so the LED strip and GPIO work
- Installs and enables the `liquorice` service, so the box starts on its own. The installer takes `systemd/liquorice.service` and rewrites the project folder, the Python path and `HOME` with the real ones, so nothing is hardcoded. The service runs as root, which is what the LED strip (PWM on `/dev/mem`), the hotspot and the card mount need
- Adds a `sudoers` rule so the app can mount the camera card read-only on `/mnt/liquorice-sd` without a password. It allows only `mkdir`, `mount -o ro` and `umount` on that one mount point

## Reboot

Reboot so the SPI setting and the new group memberships take effect:

```bash
sudo reboot
```

## Create the .env file

Your secrets do not live in the code. You must create a file called `.env` in the project folder yourself. It holds your backup login and your Wi-Fi hotspot settings. It is kept out of git on purpose, so it is never shared.

Create it now with the keys below (fill in your own values later, in chapter 5):

```bash
cd ~/liquorice-backup
cat > .env <<'EOF'
# WebDAV backup (fill these in only if you use WebDAV)
WEBDAV_HOSTNAME=
WEBDAV_FOLDER=
WEBDAV_LOGIN=
WEBDAV_PASSWORD=

# Wi-Fi hotspot the box can start on its own
WIFI_AP_SSID=Liquorice
WIFI_AP_PASSWORD=change-me
WIFI_INTERFACE=wlan0
EOF
chmod 600 .env
```

Chapter 5 explains what to put in each key. If you use rclone (Google Drive, Dropbox, and so on), you can leave the WebDAV keys empty

## Check that it worked

After the reboot, log back in and run a few checks

**Both SPI devices are there** (display on `0.0`, card reader on `0.1`):

```bash
ls -l /dev/spidev*
```

You should see `/dev/spidev0.0` and `/dev/spidev0.1`

**The screen driver uses the right reset pin (BCM 27):**

```bash
cd ~/liquorice-backup
.venv/bin/python -c "import waveshare_epd.epdconfig as e; print(e.__file__); print('RST:', e.RST_PIN)"
```

The output must show `RST: 27`

**Test each part of the hardware** with the small scripts in `software/tests/hardware/`. Run these now, right after wiring and installing, so you catch any wiring mistake early:

```bash
.venv/bin/python software/tests/hardware/test_display.py        # writes "Hello world" on the screen
.venv/bin/python software/tests/hardware/test_buttons.py        # prints which button you press
.venv/bin/python software/tests/hardware/test_reed_switch.py    # shows lid open/closed
sudo .venv/bin/python software/tests/hardware/test_led.py       # lights up the LED strip
software/tests/hardware/mount-sdcard.sh status                  # shows the card reader state
```

The LED test may need `sudo`, because the LED strip uses PWM/DMA, which some systems only allow as root.

## Trying it without a Raspberry Pi (mock mode)

You can run the software on a normal PC to explore the app and the web page, with no hardware. Use the `--mock` flag:

```bash
./install.sh --mock
.venv/bin/python software/main.py --mock
```

Mock mode only creates the environment, installs the dependencies, and prepares `~/liquorice`. It does not touch SPI, GPIO, the service, or the screen driver. To fake a card, point `sd_src` at a local folder (mock install makes `~/liquorice/fake-sd`), set `sd_mount` to `false`, and drop a few `.jpg` files in there. See chapter 5 for the config file.

### Running mock mode on the Pi's card from a PC

Mounting the Raspberry Pi's SD card on a PC and running `.venv/bin/python software/main.py --mock` from it does not work:

```
ModuleNotFoundError: No module named 'PIL'
```

That `.venv` belongs to the Pi: it was built by the Pi's Python (3.11) and its packages live in `lib/python3.11/`. On the PC `.venv/bin/python` resolves to the system Python, which looks in `lib/python3.<your version>/` and finds nothing. Worse, `./install.sh --mock` from that folder would pip-install PC packages into the Pi's environment and break it. The installer now refuses to do that and tells you so.

Use a separate environment instead, and leave the card's one alone:

```bash
LIQUORICE_VENV="$HOME/liquorice-mock-venv" ./install.sh --mock
"$HOME/liquorice-mock-venv/bin/python" -B software/main.py --mock
```

`-B` keeps Python from writing `__pycache__` onto the card. If your PC already has Pillow, Flask, python-dotenv and nmcli installed system-wide, `python3 -B software/main.py --mock` works too, with no environment at all. Better still, work on a normal clone of the repository on the PC and keep the card only for the box.

Next, pick where your photos should go: [Backup destination](05-backup-destination.md).

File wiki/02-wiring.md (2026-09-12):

# 2. Wiring and assembly

This chapter shows where to solder component on the board and how to connect each part to the Raspberry Pi. You can follow the [electrical schematic](../hardware/schematic.png) if you want a picture to follow.

Electrical schematic
*Electrical schematic: overview of all connections to the Raspberry Pi (see `hardware/schematic.png`).*

Remember that the perma-proto breadboard there is row-column connection logic.

In this guide I use board row and column coordinates in order to give you precise assembly. The column is already numered on the board, the row numeber instead needs to be counted, I refer them counting above the bottom `+/-` row

## Order of assembly

1. The Raspberry Pi, fixed in bottom face of the perma-proto breadboard
2. Buttons, card reader, LED strip and reed switch
3. The screen last, since it covers most of the header.

After wiring you should look something like:

Front view
*Front view: the top part of the Raspberry and the Screen, must coincide with the top border of the board*

Back view
*Back view: the Pi fixed on the back face of the board.*

Top view
*Top view: with all parts soldered*

## Raspberry Pi

The Pi Zero is mounted upside-down on the back face of the perma-proto board, like in the following picture, checking that the upper side of the raspberry coincide with the upper board of the board, and that Raspberry is centered (you can check it if it cover all the pin of `+/-` rows). For the moment use not the strongest tape, in order to move a bit during the 3d printing assembly.

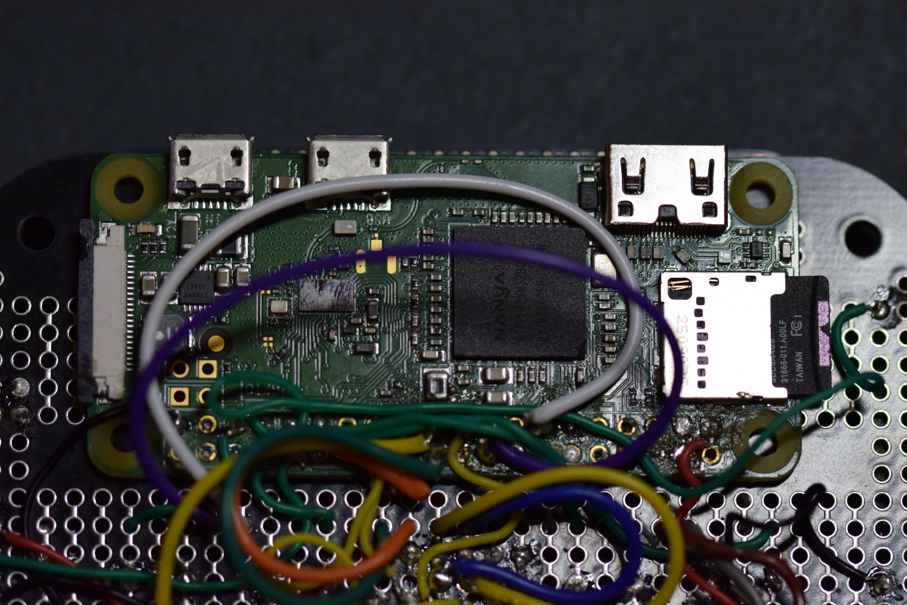
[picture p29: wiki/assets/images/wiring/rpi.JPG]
Raspberry Pi mounted

*Raspberry Pi Zero mounted on the back face of the perma-proto board: header centered and soldered on the lower side.*

## 3v3 and GND

Wire and solder  3.3 V pin (like 1) and GND like (39) along the `+`/`-` rails so every module can pick them up nearby. Keep the rails continuous and check with a multimeter before powering on.

## Buttons

There are four buttons: **Up**, **Down**, **Confirm (Right)**, and **Back (Left)**. Wire one side of each button to its BCM pin following the table, and the other side to the `-` column of the board. Place them in the **row 2**, as shown in the pictures below

| Button | BCM | Physical pin | Column  of the board |
|---|---|---|---|
| Up | 5 | 29 | 4 and 6|
| Down | 6 | 31 | 9 and 11|
| Confirm (Right) | 13 | 33 | 20 and 22 |
| Back (Left) | 19 | 35 | 25 and 27|

These are the pins the software reads.

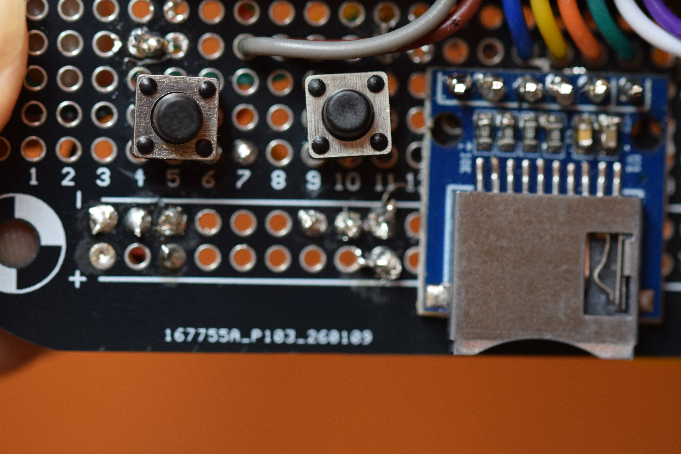
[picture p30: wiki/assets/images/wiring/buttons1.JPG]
Buttons: overview

*The up and down buttons.*

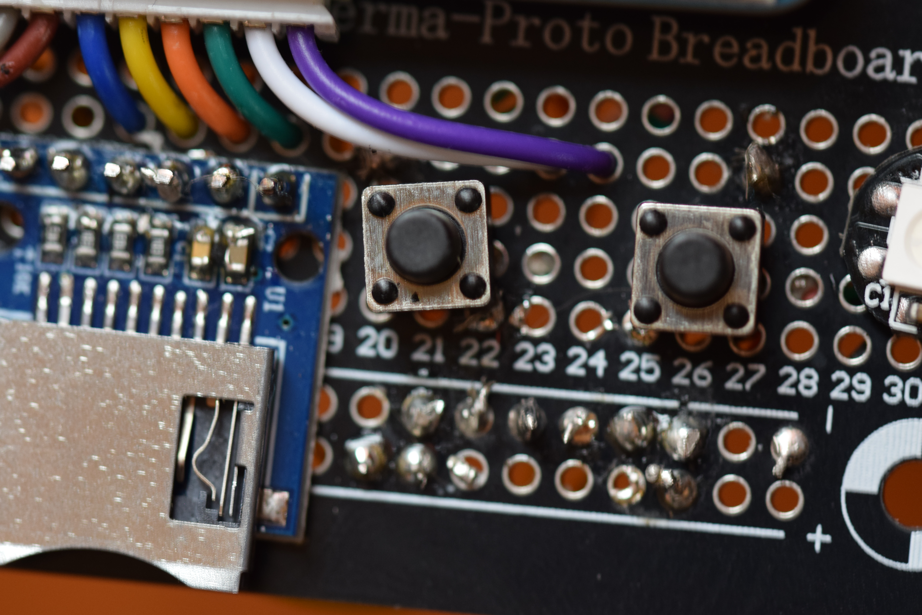
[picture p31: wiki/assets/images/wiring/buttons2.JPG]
Buttons: detail

*The confirm and back buttons*

## Card reader (external, SPI)

The camera card reader shares the same SPI0 bus as the display, but uses the second chip-select (CE1). The installer turns it on with a small system setting and runs the bus at 10 MHz.
Place also the card SPI pinout in the **row 3**.

| SD signal | BCM | Physical pin | Column |
|---|---|---|---|
| GND | GND |  `-`  | 13 |
| MISO | 9 | 21 | 14 |
| CLK  | 11 | 23 |15 |
| MOSI | 10 | 19 |16 |
| CS | 7 | 26 |17 |
| 3v3 | 3.3 V | `+` | 18 |

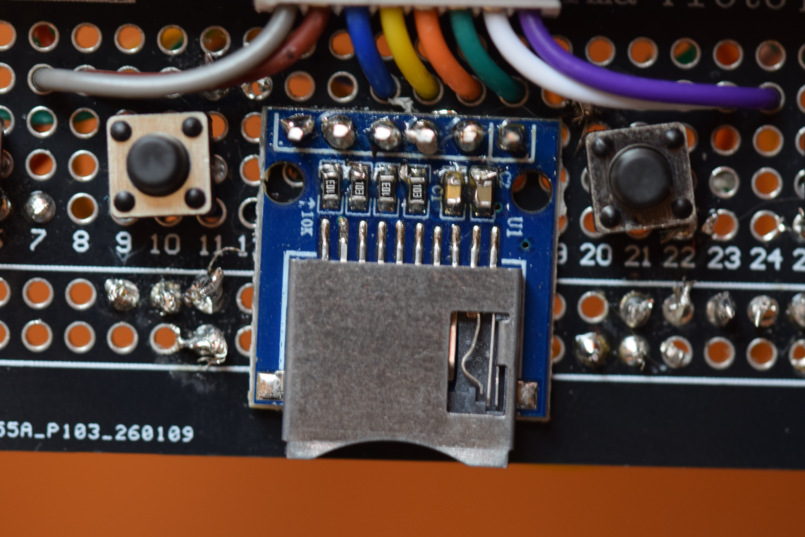
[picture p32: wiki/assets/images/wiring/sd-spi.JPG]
SPI card reader

*External microSD reader placement in the board*

After the software is installed and the Pi reboots, the card is mounted for you at `/mnt/liquorice-sd`.

## LED strip (WS2812B, 10 LEDs)

Place the led vertically in the right part of the board,  where the holes are not connected with other rows and columns, in the column *32* 

| LED wire | BCM | Physical Pin | Row | 
|---| --- | --- | --- |
| GND |  GND | `-` | 2 |
| DIN | BCM 12 | 32 | 3 |
| 5 V | 5V | 2 (or 4) | 4 |

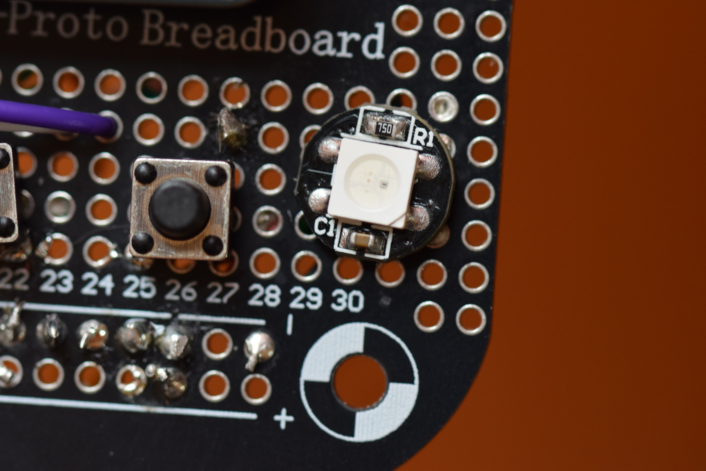
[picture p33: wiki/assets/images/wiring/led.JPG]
LED

*Led placement in the board *

## Reed switch (lid sensor)

Place the led vertically in the left part of the board, where the holes are not connected with other rows and columns, in the column *0* 

| Reed wire | BCM | Physical Pin | Row
|---|---|---|---|
| Upper part | 16 | 36 | 12 | 
| Lower part | GND | `-` | 2 | 

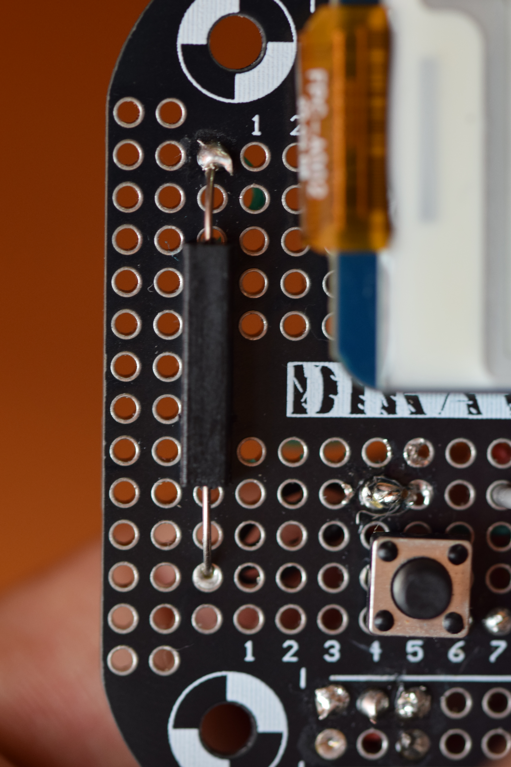
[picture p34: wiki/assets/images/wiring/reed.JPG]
Reed switch

*Reed switch on the edge of the board: one wire to BCM 16 (pin 36), the other to GND.*

Keep attention reed switch is very fragile!
Glue the magnet to the lid, so shutting the lid closes the switch. When the switch is closed, the box treats the lid as shut and sleeps the screen.

## Display (Waveshare 2.13" e-Paper, V4)

The display uses the SPI0 bus. Before wiring you to insert the wire connector in the screen hat, then you should cut the final part of the wire in order to have a male wire in one side (instead female). Then solder the wire following the table below, consider that some pin are shared with the Card Reader (MOSI, CLK) you have to solder the wire in the same column. Consider that the top side of the display must coincide with the top side of the board, otherwise it does not fit in the box.

| Display signal | BCM | Physical pin | 
|---|---|---|
| VCC | 3.3 V | + |
| GND | GND | - |
| DIN | 10 | 19 |
| CLK | 11 | 23 |
| CS / CE0 | 8 | 24 |
| DC | 25 | 22 |
| RST | 27 | 13 |
| BUSY | 24 | 18 |

In this project the reset wire (RST) goes to **BCM 27**, not the BCM 17 that Waveshare uses by default because in my RPi that pin is broken. The installer fixes the driver for you (see chapter 4), so keep RST on BCM 27.

## Check before you power on

- No wire touches both 5 V and 3.3 V.
- The display RST goes to BCM 27 (pin 13).
- The LED data wire is on BCM 12 (pin 32).
- No pin is shorted to the pin next to it.

## Test the hardware

Before assembly with the 3d printed part and placing it in the Amarelli box it's better proceeding with software installation and configuration, in order to run test for verifying that everything is working. 

Once everything is wired, you should test each part before you trust the box. The test scripts need the software, so you run them after you install it. There is a small script for the screen, the buttons, the reed switch, the LED strip, and the card reader

When everything is wired, go to [Prepare the SD card and OS](03-prepare-os.md).

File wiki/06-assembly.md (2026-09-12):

# 6. Assembly

Now that the board is wired and the software is installed and tested, it's time to put everything inside the Amarelli tin. This chapter covers the 3D printed parts and how to fit them in the box.

Do not rush this part. The tin is thin and the holes need to be made by hand, so check the fit at every step before you fix anything permanently.

## 3D printed parts

You need three printed parts: the base, the cover and the topper. The files are in the repository under `hardware/3d models/`.

| Part | What it is | Download | Photo |
|---|---|---|---|
| **Base** | The bottom frame that sits inside the tin and holds the board. | [base.3mf](../hardware/3d%20models/base.3mf) | Base |
| **Cover** | The outer shell that wraps the tin. You use it as a template for the holes. | [cover.3mf](../hardware/3d%20models/cover.3mf) | Cover |
| **Topper** | The top frame with cutouts for the screen and the four buttons. | [topper.3mf](../hardware/3d%20models/topper.3mf) | Topper |

#### Printing settings

Tested on a **Bambu Lab H2D** with **eSUN PLA Basic white** in AMS. Standard **0.4 mm nozzle**.

| Part | Filament | Supports |
|---|---|---|
| **Base** | ~8 g | No |
| **Cover** | ~8 g | No |
| **Topper** | ~19 g | Yes — auto placement, **Tree** supports |

> **Supports:** you only need supports for the **topper**. The base and the cover print fine without them. For the topper use Tree supports with auto placement (overhangs for the screen and button openings), otherwise the bridges will sag and the screen won't sit flat. After printing remove the supports carefully with a cutter and clean the edges with sandpaper.

## What you need for this step

At this point you should have: 

- The three printed parts above
- The Amarelli tin (empty)
- The wired perma-proto board with Pi, screen, buttons, LED and reed switch already soldered

For the assembly you have also to use :

- Fine tip permanent marker
- Small drill / electric screwdriver with a fine tip
- Cutter and fine sandpaper 
- Strong double-sided tape: I used the [3M 5952 VHB](../01-what-you-need.md) from the part list
- 4x M3 x 6 mm flat head screws: also in the [part list](../01-what-you-need.md)

Test the hardware once more before you close everything (see [Install the software](04-install-software.md): the `test_display.py`, `test_buttons.py` etc.). If there is a need to fix a wire it's easier to do it now.

## Assembly steps

### 1. Mark the holes on the tin

1. Take the empty tin and put it inside the printed cover
2. With the **fine tip permanent marker**, mark all the holes (sd, micro-usb and led) through the printed parts onto the tin. Do it from inside and outside so the marks are visible.

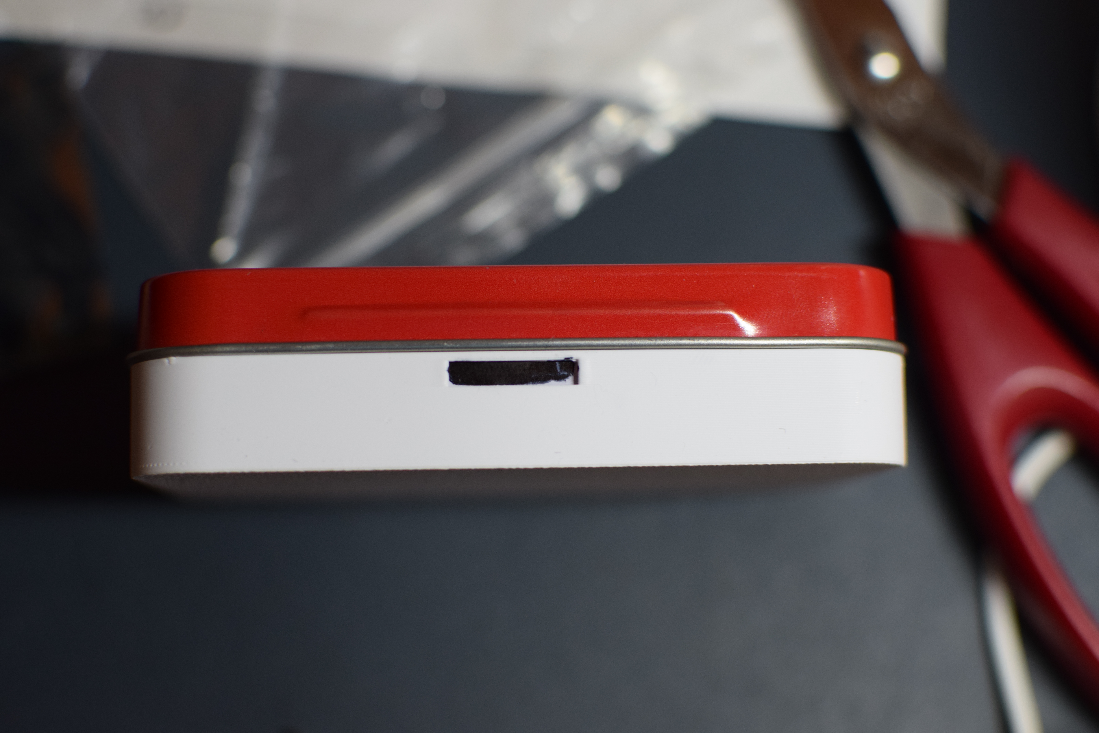
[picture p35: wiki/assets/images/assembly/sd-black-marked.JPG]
SD slot marked on the tin

*Marking the SD opening through the cover: the black marker line shows where to cut.*

### 2. Drill and finish the holes

1. Start each mark with the **electric screwdriver with a fine tip**. Don't push hard, just make a small pilot hole. The tin is thin and bends easily.
2. Enlarge and square the holes with pincers like **pliers**. Cut a little at a time.
3. Clean every edge with **cutter** and **sandpaper** so there are no burrs. The SD card should slide without catching and the USB plugs should go in without forcing.

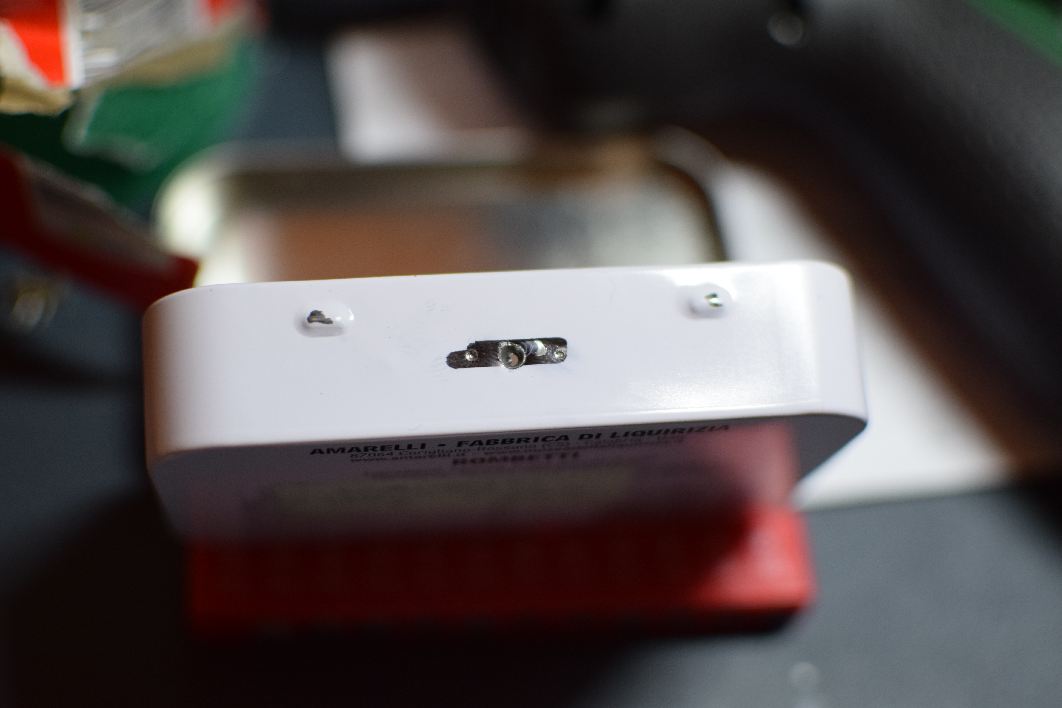
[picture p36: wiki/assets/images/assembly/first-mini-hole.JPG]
Pilot hole

*First pilot hole made with the fine tip: start small, don't push hard.*

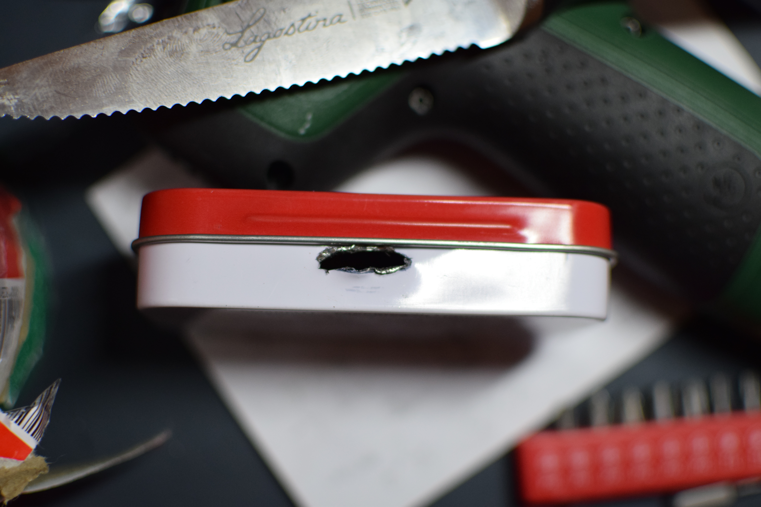
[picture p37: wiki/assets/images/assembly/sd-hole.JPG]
SD hole finished

*SD slot after enlarging: the card should slide.* 

### 3. Fix the base

1. Remove the cover from the tin.
2. Insert the **base** inside the tin, on the bottom.
3. Fix it with a couple of strips of **strong double-sided tape (3M 5952 VHB)**. Press firmly for some seconds, it should not move when you shake the tin.

### 4. Place the board and align the Pi

1. Put the wired board inside, on top of the base.
2. **Align the SD slot of the external reader and the micro-USB sockets of the Raspberry Pi** with the holes you just made on the side of the tin. Look from the outside and from the inside.
3. When the alignment is right: both USB ports are centered and the SD clicks in and out cleanly: fix the **Raspberry Pi to the base with strong tape**. For the moment don't press too hard, just enough to keep it from shifting. You still need a little play for the topper.
4. If a hole is off by a millimetre, take the board out and widen it with cutter and sandpaper.

### 5. Fit the topper and the screen

1. Place the **topper** on top of the board.
2. The **screen and the four buttons must come out** through the topper openings, flat and centered. If they rub or don't pass, enlarge the cutouts with cutter and sandpaper. Remove only a little at a time and test again.
3. When the screen sits flush and the buttons all click freely, fix the **screen to the board with a small piece of strong tape**, you can just place it below the pins hat

### 6. Close everything with screws

1. Check that **the holes of the base, the perma-proto board and the topper are all aligned**. You should see through them in one straight line at each corner.
2. Put the **M3 x 6 mm screws** in. Start them by hand so you don't cross-thread.
3. Tighten with the **electric screwdriver**: easier and more even than by hand. Don't over-tighten, the printed plastic will crack if you force it.

That's it. Give it a shake: nothing should rattle inside. Power it on placing the micro-usb, close the lid and check that the reed switch sleeps the screen, then open it and check that `Ready` shows up.

<!-- Final Foto --> 

Next: [Daily use](07-daily-use.md): how to use the box day to day.

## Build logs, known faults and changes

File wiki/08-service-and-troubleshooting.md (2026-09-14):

# 7. Run as a service and troubleshooting

## Auto-start service

The installer sets up a service called `liquorice` and turns it on, so the box starts on its own every time it powers up. You do not need to log in and launch anything.

The service runs `main.py` from the project folder as the user who ran the installer, and restarts it if it crashes.

### Managing the service

```bash
sudo systemctl status liquorice     # check the status
sudo systemctl restart liquorice    # restart after a config or code change
sudo systemctl stop liquorice       # stop it
sudo systemctl start liquorice      # start it again
```

### Watching the logs

```bash
journalctl -u liquorice -f          # live service output
```

The app also writes its own log to `~/liquorice/liquorice.log`, you can set also log location in `config.json` setting `log_path`

### Manual running

To run it yourself (for example while testing), stop the service first, so two copies do not fight over the hardware:

```bash
sudo systemctl stop liquorice
cd ~/liquorice-backup
sudo .venv/bin/python software/main.py
```

### If you move or rename things

The service file is installed from `systemd/liquorice.service`: the installer rewrites the working directory, the Python path, the command and `HOME` with the ones it finds when you run it, so any username and any project path work. What it does *not* rewrite is `User=root`: the app needs root for the LED strip (PWM and DMA go through `/dev/mem`), for the hotspot profile via `nmcli` and for mounting the card. `HOME` still points at your home, so the `~` paths in `config.json` (database, cache, log) keep resolving where your data is instead of `/root`.

If you move the project, run the installer again from the new location:

```bash
./install.sh
sudo systemctl restart liquorice
```

To see what was generated:

```bash
systemctl cat liquorice
```

## Troubleshooting

### The screen stays blank

- Check the reset pin. The driver must use BCM 27:

  ```bash
  .venv/bin/python -c "import waveshare_epd.epdconfig as e; print('RST:', e.RST_PIN)"
  ```

  It must print `RST: 27`. If not, run `./install.sh` again.

- Check both SPI devices are there:

  ```bash
  ls -l /dev/spidev*
  ```

  You need `/dev/spidev0.0` (display) and `/dev/spidev0.1` (card reader). If they are missing, SPI is off run the installer again and reboot. Make sure you have the **V4** panel; other versions need a different driver. Remember the lid: if the reed switch reads "closed", the screen sleeps. Open the lid, or move the magnet away.

### The LED strip does nothing

- The LED needs GPIO access. The installer adds your user to the `gpio` group, but that only takes effect after a reboot or a fresh login.
- Under the `liquorice` service the strip also needs to write to `/dev/mem` (the WS2812B driver drives PWM through DMA). That is why the unit runs with

  ```
  User=root
  ```

  and why the installer does not rewrite that line. If the service ends up running as a normal user you get this in the log, and the box works but stays dark:

  ```
  LED disabilitato: permessi /dev/mem insufficienti (ws2811_init failed with code -5 (mmap() failed))
  ```

  Check with `systemctl cat liquorice | grep ^User`. A non-root service can also drive the strip with `AmbientCapabilities=CAP_SYS_RAWIO CAP_DAC_OVERRIDE` instead, but both capabilities are needed: with only one of them the library crashes with a segmentation fault.

  After editing the unit, run `sudo systemctl daemon-reload && sudo systemctl restart liquorice`.
- Test it directly (may need `sudo`):

  ```bash
  sudo .venv/bin/python software/tests/hardware/test_led.py
  ```

- Check the data wire is on BCM 12 (physical pin 32).

### The card is not found

- Check the reader and mount state:

  ```bash
  software/tests/hardware/mount-sdcard.sh status
  ```

  The same script also does `mount` and `umount`.
- In `config.json`, `sd_mount` should be `true` for a real reader. Set it to `false` only when you fake the card with a local folder.
- The card is expected at `/mnt/liquorice-sd` (the `sd_src` setting in `config.json`)

### The buttons do the wrong thing

- Check the wiring against [Wiring and assembly](02-wiring-and-assembly.md):
  Up = BCM 5, Down = BCM 6, Confirm/Right = BCM 13, Back/Left = BCM 19, other side to ground
- Test which button is which:

  ```bash
  .venv/bin/python software/tests/hardware/test_buttons.py
  ```

### Uploads fail

- Check the destination is reachable from the Pi:

  ```bash
  rclone listremotes
  rclone ls <your-remote>:
  ```

- A login error, or an unrecoverable rclone exit code (1, 3, 4, 7), stops the backup and shows `Error` on the screen. Fix the remote or the login, then start the backup again
- Read `~/liquorice/liquorice.log` and `journalctl -u liquorice -f` for the exact message

### Cannot reach the web page

- Get the IP from *WiFi > Show IP*, then open `http://<box-ip>:5000`.
- The web page only runs while the box's hotspot is on. Use *WiFi > Start AP + Web server*, join the box's own network, then open the page

### "AP error!" on the screen when starting the hotspot

- Read the log: `journalctl -u liquorice -e`. A generic `Error starting AP: Connection activation failed` almost always means the AP profile was built for an interface that does not exist. NetworkManager says it plainly:

  ```bash
  journalctl -u NetworkManager -e | grep "Liquorice AP"
  # ... result="fail" reason="No suitable device found for this connection
  # (device wlan0 not available because profile is not compatible with device
  # (mismatching interface name))."
  ```

- The cause is `WIFI_INTERFACE` in `.env`. On the Raspberry Pi the Wi-Fi device is `wlan0`, not the `wlp0s...`/`wlx...` name a desktop Linux gives it. Check the real name and fix the file:

  ```bash
  nmcli -t -f DEVICE,TYPE device status | grep ':wifi$'
  ```

  The app now falls back to the first real Wi-Fi device and logs a warning (`Wi-Fi interface '...' not found ... using 'wlan0' instead`), but it is better to correct `.env` and restart the service.
- The AP password must be at least 8 characters, otherwise WPA2 refuses it. A shorter one is rejected up front and the screen shows `AP PASSWORD < 8 CHAR!`.
- `Error starting AP: [Errno 2] No such file or directory: 'iptables'` was a different case: the hotspot was really up (you could see the SSID) but the captive portal setup failed, so the screen said `AP error!` and the web server never started. Recent Raspberry Pi OS images only ship `nft`, not `iptables`. The app now uses whichever of the two is installed, and a failure here no longer stops the AP or the web page: it only logs `Captive portal redirect not active: open http://192.168.4.1:5000 by hand`.
- Whenever the AP fails to start, the log also gets a diagnostic block written on purpose for the case where the box is unreachable and you can only read the card afterwards:

  ```
  AP diagnostics: interface=wlan0 (configured=wlan0, available=wlan0) firewall=nft(/usr/sbin/nft) openssl=/usr/bin/openssl
  AP diagnostics [nmcli -f]: DEVICE  TYPE  STATE  CONNECTION | wlan0  wifi  disconnected  --
  AP diagnostics [nmcli -f]: RUNNING  STATE  WIFI  WIFI-HW | running  connected  enabled  enabled
  AP diagnostics [rfkill list]: ...
  ```

  `WIFI: disabled` or a soft-blocked radio in `rfkill` explains an activation failure that otherwise looks generic.

### The hotspot is on but you are not sure about the web page

The legend at the bottom of the screen always reports it after *Start AP + Web server*:

- `web 192.168.4.1:5000` : hotspot and web page both up, open that address
- `AP ok - WEB ERROR!` : hotspot up, web server failed to start (usually port 5000 already in use). The reason is in `~/liquorice/liquorice.log` as `Error starting Flask on ...`
- `AP error!` / `AP PASSWORD < 8 CHAR!` / `NO AP PASSWORD!` : the hotspot itself did not start, see above

### The screen freezes and the buttons do nothing after Start/Stop AP

This was a real bug, fixed: the nmcli calls ran inside the button handler, so the main loop stopped reading buttons and stopped refreshing the e-ink until NetworkManager was done, which with several saved networks could take minutes. Now both entries work in a background thread: the screen shows `Starting AP...` / `Stopping AP...` immediately and the menu stays usable, and a second request while one is running is refused with `WiFi busy...`.

If it still happens, the block is elsewhere. Check the log for the last line before the silence (`~/liquorice/liquorice.log`) and look for a slow SD mount or a stuck e-ink refresh (`journalctl -u liquorice -e`).

### `ModuleNotFoundError: No module named 'PIL'` in mock mode

You are running the Pi's `.venv` from another computer (typically with the card mounted under `/run/media/...`). That environment was built by the Pi's Python and its packages are in `lib/python3.11/`, invisible to a different Python version. Use a separate environment, as described in [Install the software](04-install-software.md#running-mock-mode-on-the-pis-card-from-a-pc), and do not run `./install.sh --mock` from the card: it would replace the Pi's packages with your PC's. The installer refuses this on purpose now.

### "Connect" on the web page just kills the hotspot

Fixed. The list used to send *Connect* with no password, so on a secured network NetworkManager answered `Secrets were required, but not provided` — but by then the hotspot was already down, and the restore failed too (`Disconnecting device failed`), leaving the box with neither the hotspot nor a network. Now a secured network that is not saved yet asks for its password in the list, the request is refused before the radio is touched if the password is missing, and `nmcli device disconnect` failing no longer stops the hotspot from coming back.

### The screen freezes and the box gets slow, and the log says BUSY

```
display - ERROR :: e-Paper BUSY alto da oltre 20s: frame non confermato, a schermo resta l'immagine vecchia...
```

The e-ink controller is not releasing its BUSY line, so the panel never confirms the refresh. The app gives up on that wait after 20 seconds, but always lets the driver finish its command sequence: it never interrupts it mid-way, because aborting leaves the panel with half a frame and the screen fills with black and white dots, which is worse than a stale image. The wait is abandoned once per frame, not once per command, so a failed redraw costs 20 seconds and not four times that.

What you see: the image stays as it was, while backup, LED and the web page keep working. Each redraw still pays those 20 seconds, so button presses feel like they hang until the panel recovers on its own.

If it does not come back, it is hardware side:

- check the CS, DC, RST and BUSY wiring against [Wiring](02-wiring.md), BUSY is BCM 24
- power-cycle the box completely (the panel keeps its state across a reboot of the Pi, so a `systemctl restart` is not enough)
- suspect the supply: Wi-Fi transmit peaks plus the LED strip can brown out a weak one, and the panel is the first thing to wedge

A different symptom, with the same wiring causes, is a panel that never raises BUSY at all: nothing appears on screen but the box stays perfectly responsive. That one the app detects separately, with `Il display non ha eseguito il refresh (BUSY mai attivo)` in the log, and it tries a hardware reset on the RST line before giving up.

### The box has no network after "Stop AP"

*Stop AP* tries the network that was active before the hotspot, then lets NetworkManager pick the best saved one, then tries every other saved profile (the ones the scan can see first). The screen shows the result: `WiFi: <network name>`, and the status screen reads `WiFi: Connected (<network name>)`. If none of them works you get the plain `◀ menu ▶ backup` legend, `WiFi: Disconnected`, and `Could not reconnect to any known Wi-Fi network` in the log. Check what the Pi has saved with:

```bash
nmcli -t -f TYPE,TIMESTAMP,NAME connection show | grep 802-11-wireless
```

If the network you expect is not there, add it from the web page while the hotspot is on.

If you started at chapter 1 and worked through to here, you now have a working Liquorice Backup box.

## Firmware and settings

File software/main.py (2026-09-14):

#!/usr/bin/env python3
import sys
import os
import argparse
import logging
import time
from pathlib import Path

logging.basicConfig(level=logging.DEBUG)
logger = logging.getLogger(__name__)

parser = argparse.ArgumentParser(
    description="Liquorice photo backup device - interactive UI"
)
parser.add_argument(
    "--mock", action="store_true", help="Use mock EPD (software rendering, no hardware)"
)
args = parser.parse_args()

if args.mock:

    class EPD:
        width = 122
        height = 250

        def init(self):
            pass

        def Clear(self, color):
            pass

        def getbuffer(self, image):
            return image

        def display(self, image):
            pass

        def sleep(self):
            pass
else:
    from waveshare_epd import epd2in13_V4, epdconfig

    EPD = epd2in13_V4.EPD


import threading

from display import (
    StatusBar,
    Legend,
    BackupStatusView,
    MenuView,
    LockView,
    Display,
    load_font,
    setup_ui_handlers,
    install_busy_timeout,
)
from menu import Menu
from keylistener import TerminalKeyListener, GpioKeyListener, ReedSwitch
from eventbus import bus
from config import Config
from database import Database
from cache import Cache
from sdcard import SdCard
from uploader import create_uploader
from log import setup_logger
from backup import Backup, State
from wifi import WiFiManager
from flask_app import create_app, get_ip_address
from led_status import LedStatus


def run_interactive(epd):
    font = load_font(11)
    spi_lock = threading.Lock()
    display = Display(epd, font, io_lock=spi_lock, health_check=not args.mock)
    display.init()

    boot_view = BackupStatusView()
    boot_view.status = "Starting..."
    display.render_full(boot_view, StatusBar(), Legend("Initializing..."))

    config = Config(bus=bus)
    setup_logger(config)
    if not args.mock:
        # Sicurezza al boot: se il profilo AP fosse rimasto su NetworkManager
        # da un arresto anomalo, va rimosso subito, prima che possa essere
        # scelto automaticamente al posto della rete Wi-Fi normale.
        try:
            WiFiManager(config).disable_ap_autostart()
        except Exception as e:
            logger.warning("Could not clear leftover AP profile at boot: %s", e)
    # LED creato dopo setup_logger: cosi' un eventuale "LED disabilitato"
    # (permessi /dev/mem) finisce in liquorice.log e non solo sullo stderr
    # del servizio.
    led = LedStatus(bus=bus, mock=False)
    logger.info(
        "Config: mock=%s sd_src=%s cache=%s db=%s log=%s uploader=%s remote=%s cloud_dst=%s mode=%s filter=%s",
        args.mock,
        config.sd_src,
        config.cache_path,
        config.db_path,
        config.log_path,
        getattr(config, "uploader", "?"),
        getattr(config, "rclone_remote", ""),
        getattr(config, "cloud_dst", ""),
        getattr(config, "mode", ""),
        getattr(config, "file_filter", ""),
    )

    db = Database(Path(config.db_path))
    cache_obj = None
    uploader = None
    try:
        uploader = create_uploader(config, db, bus)
        logger.info("Upload backend: %s", uploader.name)
    except Exception as e:
        logger.warning("Uploader init skipped: %s", e)

    wf = Backup(cache_obj, uploader, db, bus, mode=getattr(config, "mode", "upload"))
    sd_card = SdCard(
        config.sd_src, mock=args.mock, mount_enabled=getattr(config, "sd_mount", True)
    )

    def on_uploader_config_changed(key, value, **kw):
        if key not in ("uploader", "rclone_remote"):
            return
        try:
            wf.set_uploader(create_uploader(config, db, bus))
            logger.info(
                "Upload backend set to %s", getattr(config, "uploader", "webdav")
            )
        except Exception as error:
            logger.warning("Cannot switch upload backend: %s", error)

    bus.on("config:set", on_uploader_config_changed)

    sb = StatusBar()
    legend = Legend()
    menu = Menu(config=config, bus=bus)
    menu_view = MenuView(menu, bus=bus)
    status_view = BackupStatusView(db, bus=bus)
    status_view.refresh()

    sd_available = None

    def sync_sd_card():
        nonlocal cache_obj, sd_available
        mode = getattr(config, "operation_mode", "manual")
        # auto: monta subito. manual: distingue "presente" (device) da "montata".
        if mode == "auto":
            cache_available = sd_card.try_mount()
            ui_available = cache_available
        else:
            present = sd_card.is_present()
            mounted = sd_card.is_available()
            ui_available = present
            cache_available = mounted
        if cache_available and cache_obj is None:
            try:
                cache_obj = Cache(config, db, bus, io_lock=spi_lock)
                wf.set_cache(cache_obj)
                logger.info(
                    "Cache ready: src=%s dst=%s", config.sd_src, config.cache_path
                )
            except Exception as error:
                logger.warning("SD card is mounted but cannot be read: %s", error)
                cache_available = False
        elif not cache_available and cache_obj is not None:
            cache_obj = None
            wf.set_cache(None)

        if ui_available != sd_available:
            sd_available = ui_available
            if ui_available:
                logger.info("SD card available at %s", config.sd_src)
            else:
                hint = ""
                if args.mock and not Path(config.sd_src).is_dir():
                    hint = f" (hint: mock expects sd_src dir to exist, got {config.sd_src})"
                logger.info("SD card not available%s", hint)
            bus.emit("sd:changed", available=ui_available)
            # auto: SD rimossa da COMPLETED/ERROR -> IDLE, pronto al reinserimento.
            if (
                getattr(config, "operation_mode", "manual") == "auto"
                and wf.state in (State.COMPLETED, State.ERROR)
                and not ui_available
            ):
                logger.info("Auto: SD removed in %s, returning to IDLE", wf.state.name)
                wf.stop()

        # auto headless: avvia appena c'e' SD pronta o pending da uploadare.
        if (
            getattr(config, "operation_mode", "manual") == "auto"
            and wf.state == State.IDLE
        ):
            try:
                pending = db.count_pending_uploads()
            except Exception:
                pending = 0
            if ui_available or pending > 0:
                logger.info(
                    "Auto-start backup (mode=auto available=%s pending=%s)",
                    ui_available,
                    pending,
                )
                wf.start()

    def ensure_cache_on_demand() -> bool:
        # Manual/Confirm: tenta mount + init Cache. True se il backup puo' partire
        # (cache appena montata o pending da uploadare). Ritenta sempre il mount
        # nel caso la SD sia stata inserita dopo l'avvio.
        nonlocal cache_obj
        mount_ok = sd_card.try_mount()
        if mount_ok and cache_obj is None:
            try:
                cache_obj = Cache(config, db, bus, io_lock=spi_lock)
                wf.set_cache(cache_obj)
                logger.info(
                    "Cache ready (on-demand): src=%s dst=%s",
                    config.sd_src,
                    config.cache_path,
                )
                bus.emit("sd:changed", available=True)
            except Exception as e:
                logger.warning("On-demand SD mount ok but Cache init failed: %s", e)
                bus.emit("sd:changed", available=False)
                try:
                    pending = db.count_pending_uploads()
                except Exception:
                    pending = 0
                return pending > 0
        elif mount_ok:
            bus.emit("sd:changed", available=True)
        else:
            bus.emit("sd:changed", available=False)

        try:
            pending = db.count_pending_uploads()
        except Exception:
            pending = 0
        if mount_ok or pending > 0:
            return True
        logger.info("On-demand mount failed: no SD available")
        return False

    def on_sd_config_changed(key, value, **kw):
        # Debug > Fake SD (o un cambio di percorso dal web): la sorgente cambia,
        # quindi si smonta l'eventuale SD, si ricrea SdCard e si invalida la Cache.
        if key not in ("fake_sd", "fake_sd_path", "sd_src", "sd_mount"):
            return
        nonlocal sd_card, cache_obj, sd_available
        try:
            sd_card.close()
        except Exception as error:
            logger.warning("Cannot release previous SD source: %s", error)
        sd_card = SdCard(
            config.sd_src,
            mock=args.mock,
            mount_enabled=getattr(config, "sd_mount", True),
        )
        cache_obj = None
        wf.set_cache(None)
        sd_available = None
        logger.info(
            "SD source changed: fake=%s src=%s mount=%s",
            getattr(config, "fake_sd", False),
            config.sd_src,
            getattr(config, "sd_mount", True),
        )
        sync_sd_card()

    bus.on("config:set", on_sd_config_changed)

    sync_sd_card()

    keys = (
        TerminalKeyListener()
        if args.mock
        # pins = (UP, DOWN, LEFT/BACK, RIGHT/CONFIRM)
        else GpioKeyListener(
            pins=(5, 6, 19, 13), display_busy=lambda: display.refreshing
        )
    )
    reed = ReedSwitch(pin=16, enabled=not args.mock)
    if reed.is_closed:
        display.suspend()

    try:
        _loop(
            display,
            menu,
            menu_view,
            status_view,
            sb,
            legend,
            keys,
            backup=wf,
            bus=bus,
            config=config,
            db=db,
            mock=args.mock,
            sync_sd_card=sync_sd_card,
            ensure_cache_on_demand=ensure_cache_on_demand,
            reed=reed,
        )
    finally:
        try:
            led.cleanup()
        except Exception:
            pass
        sd_card.close()
        reed.cleanup()
        keys.cleanup()
        display.init()
        display.sleep()


def _handle_mock_keys(ch, sb, display, current_view, legend):
    if ch == "i":
        sb.set_wifi(not sb._wifi)
        logger.info("WiFi: %s", "connected" if sb._wifi else "disconnected")
        display.render_full(current_view, sb, legend)
        return True
    if ch == "t":
        titles = ["Liquorice", "Settings", "Photos", "System"]
        curr = titles.index(sb._title) if sb._title in titles else -1
        sb.set_title(titles[(curr + 1) % len(titles)])
        logger.info("Title: %s", sb._title)
        display.render_full(current_view, sb, legend)
        return True
    return False


def _loop(
    display,
    menu,
    menu_view,
    status_view,
    sb,
    legend,
    keys,
    backup,
    bus,
    config=None,
    db=None,
    mock=False,
    sync_sd_card=None,
    ensure_cache_on_demand=None,
    reed=None,
):
    redraw_pending = False
    last_refresh = 0.0
    last_sd_check = 0.0

    def request_redraw():
        nonlocal redraw_pending
        if mock:
            display.render_full(active_view[0], sb, legend)
        else:
            redraw_pending = True

    active_view = setup_ui_handlers(
        bus, display, sb, legend, menu, status_view, menu_view, request_redraw
    )

    def _mock_dump():
        if not mock:
            return
        leg = legend._text
        title = sb._title
        wifi_s = "ON" if getattr(sb, "_wifi", True) else "OFF"
        ssid_s = getattr(sb, "_wifi_ssid", None)
        if wifi_s == "ON" and ssid_s:
            wifi_s = f"{wifi_s}({ssid_s})"
        if active_view[0] is status_view:
            bv = status_view
            state_name = getattr(getattr(backup, "state", None), "name", "?")
            sd_s = (
                "?"
                if bv._sd_available is None
                else ("ON" if bv._sd_available else "OFF")
            )
            bar = (
                f" bar:{bv.progress_current}/{bv.progress_total}"
                if bv.progress_total
                else ""
            )
            cur = f" file:{bv.current_file}" if bv.current_file else ""
            stats = getattr(bv, "_stats", None)
            if stats:
                stats_s = f" | stats cached:{stats.get('cached_ok', 0)}/{stats.get('cached_failed', 0)} up:{stats.get('uploaded_ok', 0)}/{stats.get('uploaded_failed', 0)} rm:{stats.get('remote_deleted', 0)} pr:{stats.get('pruned', 0)}"
                if stats.get("up_to_date"):
                    stats_s += " up_to_date"
            else:
                stats_s = ""
            err_s = f" err:{bv._error_msg}" if getattr(bv, "_error_msg", "") else ""
            print(
                f"[DISPLAY] BACKUP | {title} | {bv.status} ({state_name}) | wifi:{wifi_s} sd:{sd_s} | cached:{bv.cached_count} pend:{bv.pending_upload} up:{bv.uploaded_count}{bar}{cur}{stats_s}{err_s} | legend:{leg}"
            )
        elif active_view[0] is menu_view:
            sel = menu.current_label
            idx = menu._selected
            total = len(menu._items)
            items_preview = " | ".join(
                f"{'>' if i == idx else ' '}{it.label}"
                for i, it in enumerate(menu._items)
            )
            print(
                f"[DISPLAY] MENU | {title} | sel:{sel} ({idx + 1}/{total}) | wifi:{wifi_s} | legend:{leg} | {items_preview}"
            )
        else:
            print(f"[DISPLAY] {title} | legend:{leg}")

    _orig_render_full = display.render_full

    def _wrapped_render_full(content_view, status_bar, legend_obj):
        _orig_render_full(content_view, status_bar, legend_obj)
        _mock_dump()

    if mock:
        display.render_full = _wrapped_render_full

    def on_key_press(key, **kw):
        logger.info(
            "Key pressed: %s state=%s active=%s view=%s",
            key,
            backup.state.name,
            backup.is_active,
            "status" if active_view[0] is status_view else "menu",
        )
        if active_view[0] is status_view:
            # Durante un'operazione, ogni tasto laterale mette in pausa (tollera
            # cablaggi diversi dei pin).
            if backup.is_active and key in ("LEFT", "RIGHT", "UP", "DOWN", "a", "d"):
                if backup.pause():
                    logger.info("Pause requested via %s", key)
                return
            if backup.state == State.PAUSED:
                if key in ("RIGHT", "d", "\r", "\n"):
                    backup.resume()
                    return
                if key in ("LEFT", "a", "UP", "DOWN"):
                    bus.emit("menu:opened")
                    return
                return
            if key in ("LEFT", "a"):
                bus.emit("menu:opened")
            else:
                # manual/Confirm: se non c'e' ne' cache ne' pending, ritenta il mount.
                if (
                    getattr(config, "operation_mode", "manual") == "manual"
                    and backup.state == State.IDLE
                    and key in ("RIGHT", "d", "\r", "\n")
                    and ensure_cache_on_demand is not None
                ):
                    pending = 0
                    try:
                        pending = db.count_pending_uploads() if db else 0
                    except Exception:
                        pass
                    if pending == 0:
                        ok = ensure_cache_on_demand()
                        if not ok:
                            sb.set_title("Liquorice")
                            legend.set_text("\u25c0 menu  \u25b6 backup")
                            bus.emit("ui:redraw")
                            return
                backup.handle_key_event(key)
        elif active_view[0] is menu_view:
            menu.handle_key_event(key)

    bus.on("key:press", on_key_press)

    sb.set_title("Liquorice")
    legend.set_text("\u25c0 menu  \u25b6 backup")

    def _set_wifi_status(connected: bool, ssid: str | None = None) -> None:
        """Stato Wi-Fi su barra e schermata Status, col nome della rete."""
        sb.set_wifi(connected, ssid)
        for view in (status_view, active_view[0]):
            if hasattr(view, "_wifi"):
                view._wifi = connected
                if hasattr(view, "_wifi_ssid"):
                    view._wifi_ssid = sb._wifi_ssid

    # Rete al primo disegno: senza questo la schermata mostrava "Connected"
    # anche senza rete, e non diceva mai a quale rete.
    if not mock and config is not None:
        try:
            current_ssid = WiFiManager(config).get_current_ssid()
            _set_wifi_status(bool(current_ssid), current_ssid)
        except Exception as e:
            logger.debug("Cannot read current Wi-Fi network: %s", e)

    status_view.refresh()
    display.render_full(active_view[0], sb, legend)

    wifi_manager = None
    flask_thread = None
    flask_server = None
    wifi_task_lock = threading.Lock()
    wifi_task_running = None

    def _run_wifi_task(name, work, busy_text):
        """Esegue un'operazione di rete fuori dal ciclo principale.

        nmcli puo' prendersi diversi secondi (attivazione del profilo AP,
        riconnessione, scansione): eseguendola dentro l'handler del tasto, il
        ciclo principale non leggeva piu' i tasti ne' ridisegnava lo schermo,
        e il box sembrava piantato fino alla fine dell'operazione. Qui
        l'utente vede subito "Starting/Stopping AP..." e puo' continuare a
        navigare nel menu mentre il lavoro procede.
        """
        nonlocal wifi_task_running
        with wifi_task_lock:
            if wifi_task_running:
                logger.info(
                    "[MENU] %s ignored: '%s' still running", name, wifi_task_running
                )
                legend.set_text("WiFi busy...")
                bus.emit("ui:redraw")
                return
            wifi_task_running = name
        legend.set_text(busy_text)
        bus.emit("ui:redraw")

        def runner():
            nonlocal wifi_task_running
            try:
                work()
            except Exception as e:
                logger.exception("Wi-Fi task '%s' failed: %s", name, e)
                legend.set_text("WiFi error!")
                bus.emit("ui:redraw")
            finally:
                with wifi_task_lock:
                    wifi_task_running = None

        threading.Thread(target=runner, name=name, daemon=True).start()

    def _start_flask(wm=None):
        nonlocal flask_thread, flask_server
        if flask_thread is not None and flask_thread.is_alive():
            logger.info("Flask already running")
            return True
        from werkzeug.serving import make_server

        host = getattr(config, "flask_host", "0.0.0.0")
        port = int(getattr(config, "flask_port", 5000))
        try:
            app = create_app(wifi_manager=wm, db=db, bus=bus)
            flask_server = make_server(host, port, app)
        except (Exception, SystemExit) as e:
            # Porta occupata, errore nell'app: va detto, non ingoiato, o il
            # box mostra "AP pronto" con una pagina che non risponde.
            # SystemExit e' incluso di proposito: make_server() di werkzeug
            # stampa "Port 5000 is in use" e chiama sys.exit(1), che non
            # essendo una Exception faceva terminare tutta l'applicazione.
            logger.error(
                "Error starting Flask on %s:%s: %s",
                host,
                port,
                "port already in use" if isinstance(e, SystemExit) else e,
            )
            flask_server = None
            flask_thread = None
            return False
        flask_thread = threading.Thread(target=flask_server.serve_forever, daemon=True)
        flask_thread.start()
        logger.info("Flask avviato su %s:%s", host, port)
        return True

    def _stop_flask():
        nonlocal flask_thread, flask_server
        if flask_server is not None:
            try:
                flask_server.shutdown()
            except Exception as e:
                logger.error("Error stopping Flask: %s", e)
            flask_server = None
        flask_thread = None
        logger.info("Flask fermato")

    def start_hotspot(**kw):
        _run_wifi_task("start-ap", _start_hotspot_work, "Starting AP...")

    def _start_hotspot_work():
        nonlocal wifi_manager
        # Per sicurezza il server web parte solo insieme all'access point:
        # non deve mai restare in ascolto sulla rete Wi-Fi normale.
        logger.info("[MENU] Starting AP + Flask...")
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

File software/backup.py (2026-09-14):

import logging
import re
import threading
import time
from enum import Enum, auto

from exceptions import TransientError, PermanentError
from eventbus import EventBus

logger = logging.getLogger(__name__)


class State(Enum):
    IDLE = auto()
    CACHING = auto()
    UPLOADING = auto()
    REMOTE_CLEANUP = auto()
    PRUNING = auto()
    COMPLETED = auto()
    PAUSED = auto()
    RETRYING = auto()
    ERROR = auto()


_PHASES = [
    (State.CACHING, "_cache", "copy"),
    (State.UPLOADING, "_uploader", "upload"),
    (State.REMOTE_CLEANUP, "_uploader", "cleanup_remote"),
    (State.PRUNING, "_cache", "prune"),
]

_TIMESTAMP_SUFFIX = re.compile(r"_\d+$")


class Backup:
    def __init__(
        self, cache, uploader, db, bus=None, max_retries=3, retry_delay=5, mode="upload"
    ):
        self._cache = cache
        self._uploader = uploader
        self._next_uploader = None
        self._db = db
        self._bus = bus or EventBus()
        self._max_retries = max_retries
        self._retry_delay = retry_delay
        self._mode = mode
        self._next_mode = mode
        self._state = State.IDLE
        self._resume_state = State.IDLE
        self._cancel = threading.Event()
        # I totali vivono sull'istanza: _run() gira in un thread nuovo a ogni
        # resume, se fossero locali il riepilogo perderebbe i file gia' fatti.
        self._stats = self._new_stats()
        self._bus.on("config:set", self._on_config_set)
        if self._cache is not None:
            self._cache._cancel = self._cancel
        if self._uploader is not None:
            self._uploader._cancel = self._cancel

    @property
    def state(self) -> State:
        return self._state

    @property
    def is_active(self) -> bool:
        return self._state in (
            State.CACHING,
            State.UPLOADING,
            State.REMOTE_CLEANUP,
            State.PRUNING,
        )

    def start(self) -> bool:
        if self._state != State.IDLE:
            logger.info("Backup start ignored: state=%s", self._state.name)
            return False

        pending = self._db.count_pending_uploads()

        if self._cache is None and pending == 0:
            logger.info(
                "Backup start ignored: no cache and no pending uploads (pending=%s)",
                pending,
            )
            return False
        self._mode = self._next_mode

        if self._next_uploader is not None:
            self._uploader = self._next_uploader
            self._next_uploader = None

        if self._cache:
            self._cache.prepare_backup()
        self._cancel.clear()
        self._stats = self._new_stats()
        self._set_state(State.CACHING, reset=True)
        threading.Thread(target=self._run, daemon=True).start()
        return True

    def set_cache(self, cache) -> None:
        self._cache = cache
        if cache is not None:
            cache._cancel = self._cancel

    def set_uploader(self, uploader) -> None:
        # Se un backup è in corso, il cambio scatta al backup successivo.
        if self.is_active or self._state in (State.PAUSED, State.RETRYING):
            self._next_uploader = uploader
            if uploader is not None:
                uploader._cancel = self._cancel
            logger.info("Upload backend will change on the next backup")
            return
        self._uploader = uploader
        self._next_uploader = None
        if uploader is not None:
            uploader._cancel = self._cancel

    def _on_config_set(self, key, value, **kw):
        if key == "mode":
            self._next_mode = value
            logger.info("Backup mode will change to %s on the next backup", value)

    @staticmethod
    def _new_cloud_destination(cloud_dst: str, timestamp: int) -> str:
        base = cloud_dst
        while _TIMESTAMP_SUFFIX.search(base):
            base = _TIMESTAMP_SUFFIX.sub("", base)
        return f"{base}_{timestamp}"

    def pause(self) -> bool:
        if not self.is_active and self._state != State.RETRYING:
            return False
        self._cancel.set()
        self._set_state(State.PAUSED)
        logger.info("Backup paused by user")
        return True

    def resume(self) -> bool:
        if self._state != State.PAUSED:
            return False
        self._cancel.clear()
        self._set_state(self._resume_state)
        threading.Thread(target=self._run, daemon=True).start()
        return True

    def stop(self) -> bool:
        if self._state not in (State.PAUSED, State.COMPLETED, State.ERROR):
            return False
        self._set_state(State.IDLE)
        return True

    def _set_state(self, state: State, **kw):
        if state != self._state:
            old, self._state = self._state, state
            if state == State.PAUSED:
                self._resume_state = old
            logger.info("Backup: %s -> %s", old.name, state.name)
        self._bus.emit("backup:state", state=state, **kw)

    def _get_phase_total(self, state) -> int:
        try:
            if state == State.CACHING:
                return self._cache.count_uncached() if self._cache else 0
            if state == State.UPLOADING:
                return self._db.count_pending_uploads()
            if state == State.REMOTE_CLEANUP:
                return len(self._db.find_marked_for_deletion())
            if state == State.PRUNING:
                return len(self._db.find_uploaded_not_pruned())
        except Exception:
            return 0
        return 0

    @staticmethod
    def _new_stats() -> dict:
        return {
            "cached_ok": 0,
            "cached_failed": 0,
            "uploaded_ok": 0,
            "uploaded_failed": 0,
            "remote_deleted": 0,
            "pruned": 0,
        }

    def _collect_stats(self, state, obj):
        stats = self._stats
        if state == State.CACHING:
            s = getattr(obj, "last_copy_stats", {})
            stats["cached_ok"] += s.get("ok", 0)
            stats["cached_failed"] = s.get("failed", 0)
        elif state == State.UPLOADING:
            s = getattr(obj, "last_upload_stats", {})
            stats["uploaded_ok"] += s.get("ok", 0)
            stats["uploaded_failed"] = s.get("failed", 0)
        elif state == State.REMOTE_CLEANUP:
            stats["remote_deleted"] += getattr(obj, "last_cleanup_stats", {}).get(
                "ok", 0
            )
        elif state == State.PRUNING:
            stats["pruned"] += getattr(obj, "last_prune_stats", {}).get("ok", 0)

    def _skip_phase(self, state) -> bool:
        if self._mode == "upload" and state == State.REMOTE_CLEANUP:
            return True
        if self._mode == "mirror" and state == State.PRUNING:
            return True
        return False
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

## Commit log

2026-06-13 Changed pin
2026-09-03 Fix GPIO buttons pins
    [main.py]
2026-09-04 gpio permission and chenged pin for led
2026-09-06 Fix SD card mounting
2026-09-08 Reed switch and minor improvements
2026-09-09 Added wiki
    [base.3mf, base.stl, cover.3mf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]
2026-09-09 Revise microSD card specifications for Pi
    Updated microSD card recommendation to suggest a minimum of 64 GB for better performance with the camera.
2026-09-10 Refactored code and wiki
    [base.3mf, base.stl, cover.3mf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]
2026-09-14 Led bug fixed
2026-09-14 Bug current file fixed
    [cache.py, display.py, main.py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]
